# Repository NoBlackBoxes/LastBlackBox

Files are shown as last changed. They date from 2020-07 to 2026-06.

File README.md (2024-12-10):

# The Last Black Box

> - Do you depend on technology to work? to learn? to socialize?
> - Do you want to know what is going on inside the machines that run your life?
> - Do you want to be ready for the coming era of AI?

<p align="center">
LBB
</p>

## Summary

Imagine a world without "black boxes". A world where you understand how your tools work and can use them to do what you want.

This world is much closer than you realize, and we have developed this training course to help get you there as quickly (and enjoyably!) as possible.

**The Last Black Box** is a hands-on introduction to the foundations of modern technology<p>...from ***electrons*** to ***AI***.

## Principles

<p align="center">
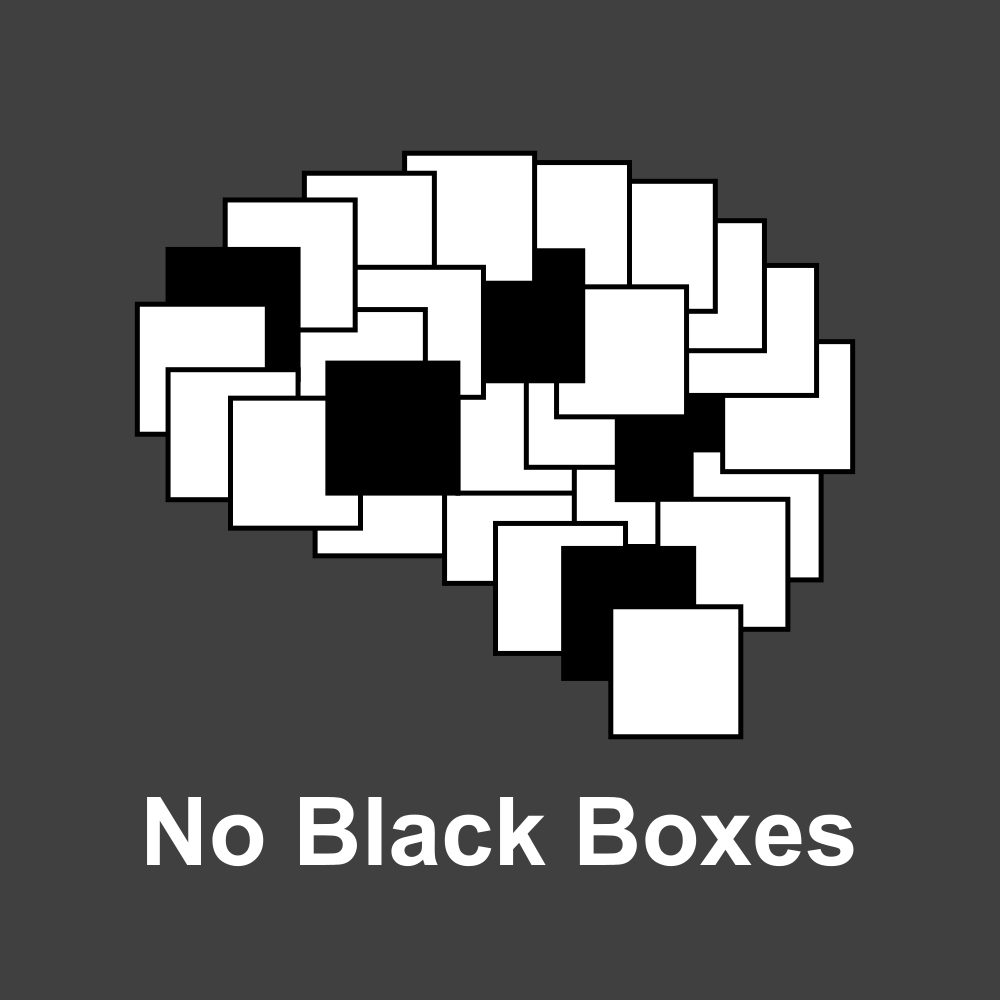
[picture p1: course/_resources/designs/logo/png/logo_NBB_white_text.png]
NBB

</p>

----

<p align="center" style="font-size:32px">
<a href="course/README.md" style="color: #FFFF00; background: #000000; border-color: #FFFF00; border-style: solid; border-width: 2px; border-radius:6px; padding-left:12px; padding-right:12px;"><b>Start the course!</b></a>
</p>

----

## License

<br />The entire LastBlackBox repository and website is licensed under a <a rel="license" href="http://creativecommons.org/licenses/by-nc-sa/4.0/">Creative Commons Attribution-NonCommercial-ShareAlike 4.0 International License</a>.

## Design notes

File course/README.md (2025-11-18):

# The Last Black Box Course

> A course consisting of 28 **black boxes** that you open in sequence using the materials contained in the "Last Black Box" kit

<p align="center">
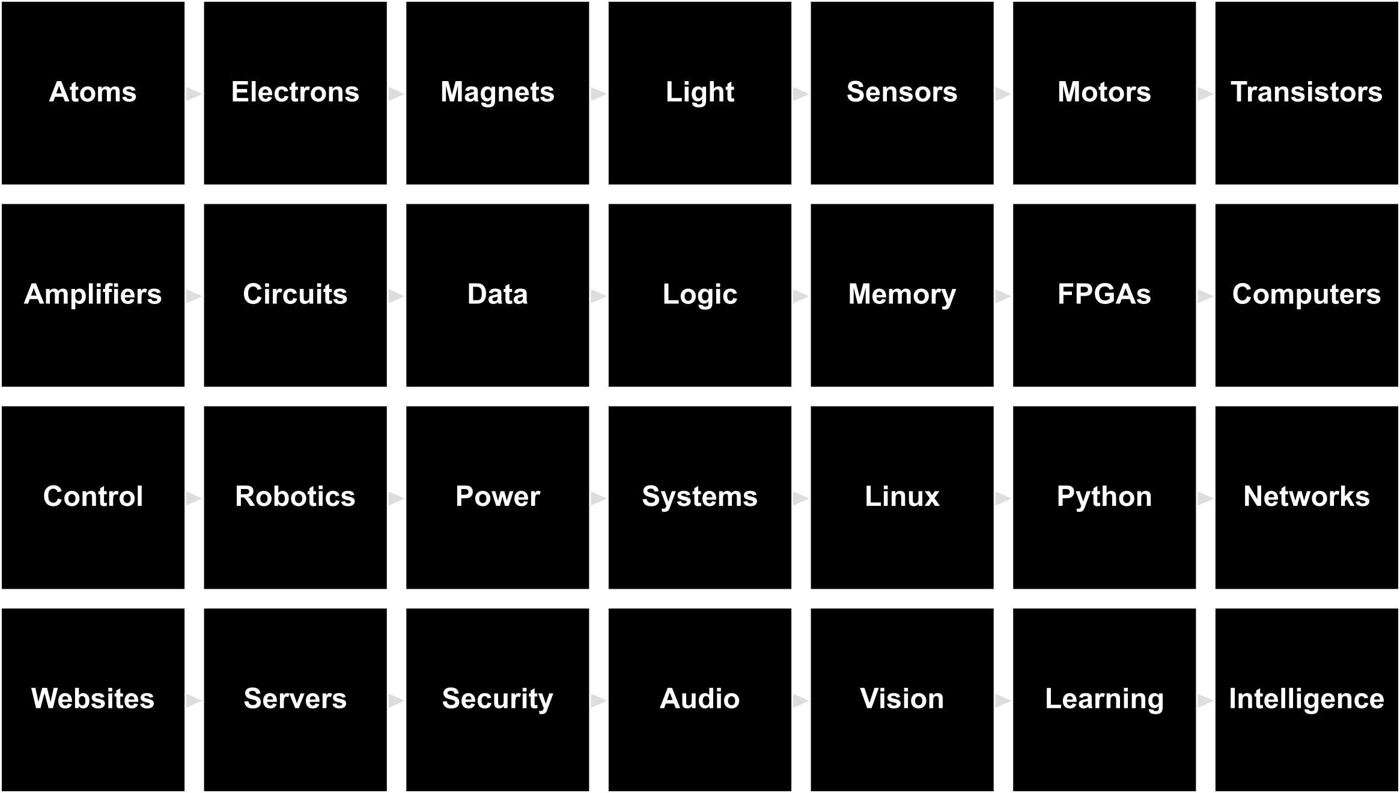
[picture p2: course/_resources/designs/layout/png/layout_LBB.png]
Course Layout

<h3 style="text-align:center;">Order your "<a href=https://www.noblackboxes.org/courses target="_blank">Last Black Box</a>" now!</h3>
</p>

----

## NB3

You will be building a brain for your robot. The robot's physical layout mimics the basic anatomy of a (vertebrate) brain. As you progress through the course, your robot will *evolve* into an increasingly sophisticated machine. The goal is to create an "intelligent" machine without using any **black boxes**. We thus call this robot the No-Black-Box-Brain or NBBB or ***NB3***.

<p align="center">
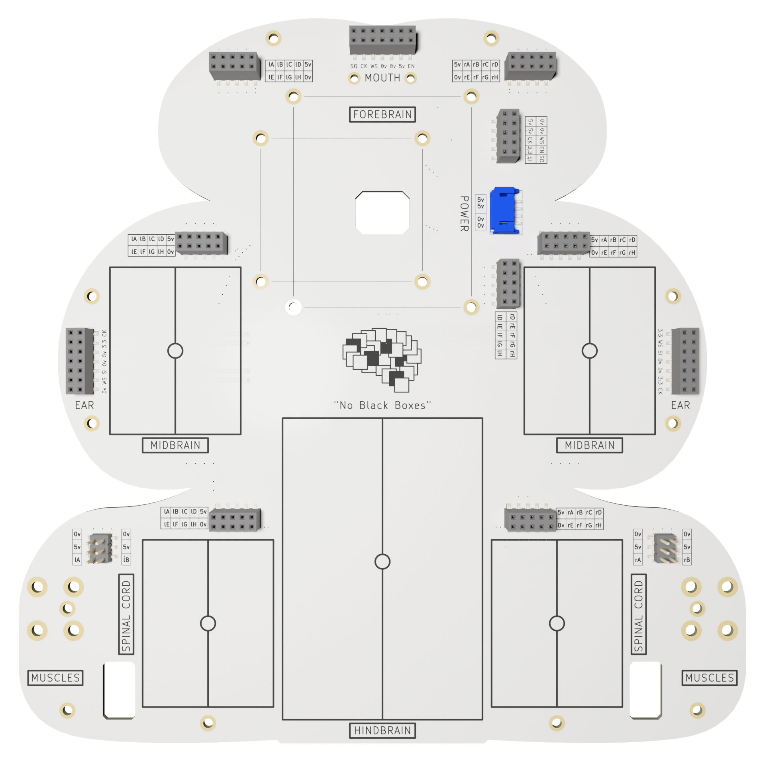
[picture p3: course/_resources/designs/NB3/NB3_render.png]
NB3 outline

</p>

## Repository
The course is based on the documentation and code in this repo (LBB). You will first work through the material on GitHub.com, but when you manage to connect to your Raspberry Pi via SSH, then you will be asked to clone this repo to your NB3. **It is very important that you clone the LBB repo to a specific folder ("NoBlackBoxes") in your NB3's home directory**.
> *Why?* Most of the code examples assume that the repo is stored in this location. If you prefer to put it somewhere else, then you must be comfortable modifying the "repo root" path used in the examples.

```bash
cd $HOME            # Navigate to your "Home" directory
mkdir NoBlackBoxes  # Create NoBlackBoxes directory
cd NoBlackBoxes     # Change to NoBlackBoxes directory

# Clone LBB repo (only the most recent commit)
git clone --depth 1 https://github.com/NoBlackBoxes/LastBlackBox
```

## Versions
There are shorter versions of this course that cover a specific subset of the "black boxes" and focus on specific themes.

- [Bootcamp](versions/bootcamp/README.md): A one-week intensive introduction to the essentials of modern technology and neuroscience.

- [Build a Brain](versions/buildabrain/README.md): Designed for secondary school age students, this hands-on course shows you how recent advances in science and technology have made it possible for humans to create intelligent machines...by building you own. 

- [Own Phone](versions/ownphone/README.md): ***-Under Development-*** Get your "smartphone license"! Demonstrate to your parents/friends that you can take control of your digital tools...before they take control you.

## Black Boxes

1. **Atoms**
    - *Technology*: Introduction to atoms, sub-atomic particles, and forces.
    - *Neuroscience*: From physics to chemistry to biology to brains.
    > *Tasks*: Draw your favorite atoms and molecules.

2. **Electrons**
    - *Technology*: Intro to basic electronics: voltage, current, resistance, batteries, Ohm's Law, voltage dividers, and power (dissipation).
    - *Neuroscience*: Neurons (resting potential), passive properties.
    > *Tasks*: Measure voltage/current/resistance. Build a voltage divider. Turn on a light bulb.

3. **Magnets**
    - *Technology*: Intro to magnetism
    - *Neuroscience*: Why not?
    > *Tasks*: Build a speaker...coil an electromagnet

4. **Light**
    - *Technology*: Intro to EM radiation and spectrum
    - *Neuroscience*: Why not?
    > *Tasks*: Lightbulbs and antennas

5. **Sensors**
    - *Technology*: Intro to transduction of heat, light, pressure, and sound.
    - *Neuroscience*: Intro to photoreceptors, hair cells, and mechanosensors.
    > *Tasks*: Build a light, heat, pressure sensor using a photoresitor, thermistor, piezo

6. **Motors**
    - *Technology*: Intro to electromagnetism and piezos
    - *Neuroscience*: Muscles and motor neruons (chemical synapses?)
    > *Tasks*: Wind a coil, spin a motor, make a sound, build a theremin(?)

7. **Transistors**
    - *Technology*: Intro to tubes and transistors
    - *Neuroscience*: Action potentials and axons and synapses (or later...with decisions?)
    > *Tasks*: Switch on a motor with your sensor, better theremin?

8. **Amplifiers**
    - *Technology*: Intro op amps
    - *Neuroscience*: Multiplicative NMJ, gain
      - Exercises**: Move a motor with your sensor, better theremin?

9. **Circuits**
    - *Technology*: Intro to integrated circults; how are they made and what are they good for.
    - *Neuroscience*: Simple sensorimotor behaviour
    > *Tasks*: Build a Braitenberg vehicle

10. **Power**
    - *Technology*: Voltage regulators
    - *Neuroscience*: Efficiency and homeostasis
    > *Tasks*: Install NB3_power

11. **Data**
    - *Technology*: Getting from analog to digital (0 and 1s is all you need), ADCs and DACs
    - *Neuroscience*: Neural code? (rate v timing?)
    > *Tasks*: Comparator...Build a simple ADC?

12. **Logic**
    - *Technology*: digital logic and the basis of computation
    - *Neuroscience*: Simple neural circuits: E and I
    > *Tasks*: Build an adder

13. **Memory**
    - *Technology*: flip/flop, flash, storage
    - *Neuroscience*: Synapses, LTP, and NMDA channels
    > *Tasks*: Sample hold circuit? (clapper?) Build a D-Latch

14. **FPGAs**
    - *Technology*: Programmble logic devices, HDL (verilog)
    - *Neuroscience*: simple, adaptable circuits for computation
    > *Tasks*: Adder in FPGA...ALU...cpu

15. **Computers**
    - *Technology*: ALU, microcontrollers and progamming I
    - *Neuroscience*: basic brains (brain computer anlogy debate)
    > *Tasks*: Arduino basics, blinky in ASM and C

16. **Control**
    - *Technology*: Negative feedback and servos, H-bridge, PID
    - *Neuroscience*: Motor control
    > *Tasks*: Write direction, speed (and position?) controller

17. **Robotics**
    - *Technology*: Smarter robots
    - *Neuroscience*: Smarter bot
    > *Tasks*: Ardunio based robot (PWM motors? various sensors?): Task: ?

18. **Systems**
    - *Technology*: Operating systems and programming II
    - *Neuroscience*: Brain systems (sense, perceive, memory, learning, )
    > *Tasks*: Booting and connecting

19. **Linux**
    - *Technology*: Linux and command lines
    - *Neuroscience*: Should the interfaces to your brain be "open"?
    > *Tasks*: Linux-life

20. **Python**
    - *Technology*: Programming in Python, installing packages, and virtual environments
    - *Neuroscience*: How to think like a programmer?
    > *Tasks*: Talk to your hindbrain

21. **Networks**
    - *Technology*: Internet protocols and WiFi
    - *Neuroscience*: Physical layer and neural protocols
    > *Tasks*: SSH and connect to bot via ESP or NRF

22. **Websites**
    - *Technology*: HTML, CSS
    - *Neuroscience*: ??
    > *Tasks*: Build a nice looking website

23. **Servers**
    - *Technology*: HTTP requests and responses
    - *Neuroscience*: ??
    > *Tasks*: Host your nice looking website

24. **Security**
    - *Technology*: Encryption
    - *Neuroscience*: ??
    > *Tasks*: Mine a bitcoin?

25. **Audio**
    - *Technology*: From mics to "understanding" sound
    - *Neuroscience*: Extracting information from hair cells, sound localization
    > *Tasks*: Build a sound localizer (dealing with 1D data)

26. **Vision**
    - *Technology*: From cameras to "vision"
    - *Neuroscience*: Extracting information from photoreceptors (through V1 and beyond)
    > *Tasks*: Build a colored blob detector

27. **Learning**
    - *Technology*: Reinforcement learning and clicker training
    - *Neuroscience*: RL in brains
    > *Tasks*: Clicker train yourself and your robot

28. **Intelligence**
    - *Technology*: Neural Networks and modern "AI", NPUs, LLMs
    - *Neuroscience*: From fish to humans, evolution of biological intelligence
    > *Tasks*: NPU and tensorflow...mysteries...

----

## License

<br />The entire LastBlackBox repository and website is licensed under a <a rel="license" href="http://creativecommons.org/licenses/by-nc-sa/4.0/">Creative Commons Attribution-NonCommercial-ShareAlike 4.0 International License</a>.

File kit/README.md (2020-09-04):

# The Last Black Box Kit

A set of black boxes to open in sequence

----

## Boxes

<p align="center">
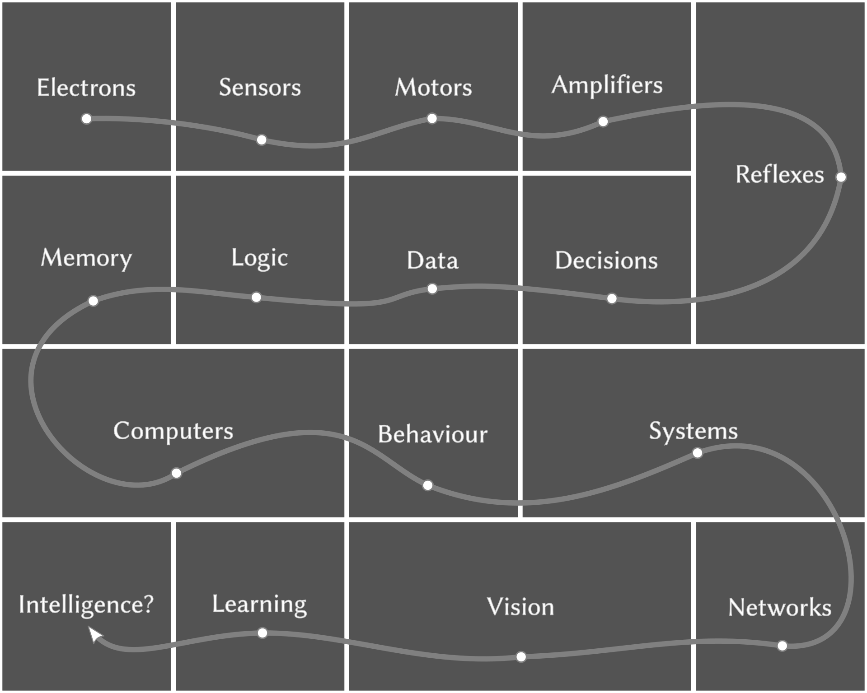
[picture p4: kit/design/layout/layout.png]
Example Image

</p>

----

1. [Electrons](/boxes/electrons/README.md)
2. [Sensors](/boxes/sensors/README.md)
3. [Motors](/boxes/motors/README.md)
4. [Amplifiers](/boxes/amplifiers/README.md)
5. [Reflexes](/boxes/reflexes/README.md)
6. [Decisions](/boxes/decisions/README.md)
7. [Data](/boxes/data/README.md)
8. [Logic](/boxes/logic/README.md)
9. [Memory](/boxes/memory/README.md)
10. [Computers](/boxes/computers/README.md)
11. [Behaviour](/boxes/behaviour/README.md)
12. [Systems](/boxes/systems/README.md)
13. [Networks](/boxes/networks/README.md)
14. [Vision](/boxes/vision/README.md)
15. [Learning](/boxes/learning/README.md)
16. [Intelligence?](/boxes/intelligence/README.md)

### Descriptions

1. **Electrons**

    - *Tech*: Intro to basic electronics: voltage, current, resistance, batteries, Ohm's Law, voltage dividers, and power (dissipation).
    - *Brain*: Neurons (resting potential), passive properties.
    - *Exercises*: Measure voltage/current/resistance. Build a voltage divider. Turn on a light bulb.

2. **Sensors**

    - *Tech*: Intro to transduction of heat, light, pressure, and sound.
    - *Brain*: Intro to photoreceptors, hair cells, and mechanosensors.
    - *Exercises*: Build a light, heat, pressure sensor using a photoresitor, thermistor, piezo

3. **Motors**

    - *Tech*: Intro to electromagnetism and piezos
    - *Brain*: Muscles and motor neruons (chemical synapses?)
    - *Exercises*: Wind a coil, spin a motor, make a sound, build a theremin(?)

4. **Amplifiers**

    - *Tech*: Intro to tubes and transistors, and op amps
    - *Brain*: Action potentials and axons and synapses (or later...with decisions?)
    - *Exercises*: Move a motor with your sensor, better theremin?

5. **Reflexes**

    - *Tech*: Intro to control
    - *Brain*: Simple sensorimotor behaviour
    - *Exercises*: Build a Braitenberg vehicle

6. **Decisions**

    - *Tech*: Transistors as switches (and relays?)
    - *Brain*: Action potential
    - *Exercises*: Light/Dark finding bot?

7. **Data**

    - *Tech*: Getting from analog to digital (0 and 1s is all you need), ADCs and DACs
    - *Brain*: Neural code? (rate v timing?)
    - *Exercises*: Build a simple ADC?

8. **Logic**

    - *Tech*: digital logic and the basis of computation
    - *Brain*: Simple neural circuits: E and I
    - *Exercises*: Build an adder

9. **Memory**

    - *Tech*: flip/flop, flash, storage
    - *Brain*: Synapses, LTP, and NMDA channels
    - *Exercises*: Sample hold circuit? (clapper?) Build a D-Latch

10. **Computers**

    - *Tech*: ALU, microcontrollers and progamming I
    - *Brain*: basic brains (brain computer anlogy debate)
    - *Exercises*: Arduino basics, blinky in ASM and C

11. **Behaviour**

    - *Tech*: Smarter robots
    - *Brain*: Smarter bot
    - *Exercises*: Ardunio based robot (PWM motors? various sensors?): Task: ?

12. **Systems**

    - *Tech*: Operating systems and programming II
    - *Brain*: Brain systems (sense, perceive, memory, learning, )
    - *Exercises*: Python basics, linux basics

13. **Networks**

    - *Tech*: Internet protocols and WiFi
    - *Brain*: Physical layer and neural protocols
    - *Exercises*: SSH and connect to bot via ESP or NRF

14. **Vision**

    - *Tech*: From cameras to "vision"
    - *Brain*: Extracting information from photoreceptors (through V1 and beyond)
    - *Exercises*: Build a colored blob detector

15. **Learning**

    - *Tech*: Reinforcement learning and clicker training
    - *Brain*: RL in brains
    - *Exercises*: Clicker train yourself and your robot

16. **Intelligence?**

    - *Tech*: Neural Networks and modern "AI", NPU
    - *Brain*: From fish to humans, evolution of biological intelligence
    - *Exercises*: NPU and tensorflow...mysteries...

- ***The Last Black Box***
  - *Tech*: What are we missing?
  - *Brain*: What are we missing?
  - *Exercises*: Image a brain slice (golgi stain? Nissl?)

----

## License

<br />The entire LastBlackBox repository and website is licensed under a <a rel="license" href="http://creativecommons.org/licenses/by-nc-sa/4.0/">Creative Commons Attribution-NonCommercial-ShareAlike 4.0 International License</a>.

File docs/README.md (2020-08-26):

<p align="center">
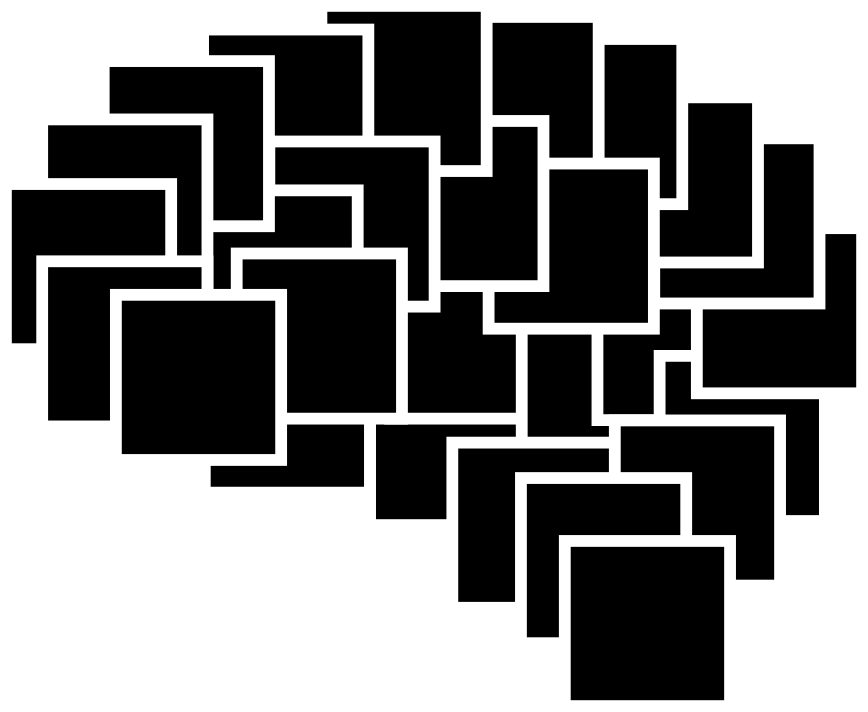
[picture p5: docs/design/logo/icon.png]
LBB

</p>

# The Last Black Box

A course for brains interested in brains (not for tools interested in tools)

----

## Boxes

<p align="center">
Example Image
</p>

----

### Titles

1. Electrons
2. Sensors
3. Motors
4. Amplifiers
5. Reflexes
6. Decisions
7. Data
8. Logic
9. Memory
10. Computers
11. Behaviour
12. Systems
13. Networks
14. Vision
15. Learning
16. Intelligence?

### Descriptions

1. **Electrons**

   - *Tech*: Intro to basic electronics: voltage, current, resistance, batteries, Ohm's Law, voltage dividers, and power (dissipation).
   - *Brain*: Neurons (resting potential), passive properties.
   - *Exercises*: Measure voltage/current/resistance. Build a voltage divider. Turn on a light bulb.

2. **Sensors**

   - *Tech*: Intro to transduction of heat, light, pressure, and sound.
   - *Brain*: Intro to photoreceptors, hair cells, and mechanosensors.
   - *Exercises*: Build a light, heat, pressure sensor using a photoresitor, thermistor, piezo

3. **Motors**

    - *Tech*: Intro to electromagnetism and piezos
    - *Brain*: Muscles and motor neruons (chemical synapses?)
    - *Exercises*: Wind a coil, spin a motor, make a sound, build a theremin(?)

4. **Amplifiers**

    - *Tech*: Intro to tubes and transistors, and op amps
    - *Brain*: Action potentials and axons and synapses (or later...with decisions?)
    - *Exercises*: Move a motor with your sensor, better theremin?

5. **Reflexes**

    - *Tech*: Intro to control
    - *Brain*: Simple sensorimotor behaviour
    - *Exercises*: Build a Braitenberg vehicle

6. **Decisions**

    - *Tech*: Transistors as switches (and relays?)
    - *Brain*: Action potential
    - *Exercises*: Light/Dark finding bot?

7. **Data**

    - *Tech*: Getting from analog to digital (0 and 1s is all you need), ADCs and DACs
    - *Brain*: Neural code? (rate v timing?)
    - *Exercises*: Build a simple ADC?

8. **Logic**

    - *Tech*: digital logic and the basis of computation
    - *Brain*: Simple neural circuits: E and I
    - *Exercises*: Build an adder

9. **Memory**

    - *Tech*: flip/flop, flash, storage
    - *Brain*: Synapses, LTP, and NMDA channels
    - *Exercises*: Sample hold circuit? (clapper?) Build a D-Latch

10. **Computers**

    - *Tech*: ALU, microcontrollers and progamming I
    - *Brain*: basic brains (brain computer anlogy debate)
    - *Exercises*: Arduino basics, blinky in ASM and C

11. **Behaviour**

    - *Tech*: Smarter robots
    - *Brain*: Smarter bot
    - *Exercises*: Ardunio based robot (PWM motors? various sensors?): Task: ?

12. **Systems**

    - *Tech*: Operating systems and programming II
    - *Brain*: Brain systems (sense, perceive, memory, learning, )
    - *Exercises*: Python basics, linux basics

13. **Networks**

    - *Tech*: Internet protocols and WiFi
    - *Brain*: Physical layer and neural protocols
    - *Exercises*: SSH and connect to bot via ESP or NRF

14. **Vision**

    - *Tech*: From cameras to "vision"
    - *Brain*: Extracting information from photoreceptors (through V1 and beyond)
    - *Exercises*: Build a colored blob detector

15. **Learning**

    - *Tech*: Reinforcement learning and clicker training
    - *Brain*: RL in brains
    - *Exercises*: Clicker train yourself and your robot

16. **Intelligence?**

    - *Tech*: Neural Networks and modern "AI", NPU
    - *Brain*: From fish to humans, evolution of biological intelligence
    - *Exercises*: NPU and tensorflow...mysteries...

- ***The Last Black Box***
  - *Tech*: What are we missing?
  - *Brain*: What are we missing?
  - *Exercises*: Image a brain slice (golgi stain? Nissl?)

----

## License

<br />The entire LastBlackBox repository and website is licensed under a <a rel="license" href="http://creativecommons.org/licenses/by-nc-sa/4.0/">Creative Commons Attribution-NonCommercial-ShareAlike 4.0 International License</a>.

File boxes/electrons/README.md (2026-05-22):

# The Last Black Box : Electrons
In this box, you will learn about electrons...

<details><summary><i>Materials</i></summary><p>

Name|Description| # |Package|Data|Link|
:-------|:----------|:-----:|:-:|:--:|:--:|
NB3 Body|NB3 robot base PCB|1|Body (000)|[-D-](/boxes/electrons/NB3_body)|[-L-](VK)
Resistor (470)|470 &Omega;/0.25 W|2|Passive Electronics|[-D-](/boxes/electrons/_resources/datasheets/resistor.pdf)|[-L-](https://uk.farnell.com/multicomp/mf25-470r/res-470r-1-250mw-axial-metal-film/dp/9341943)
Resistor (1k)|1 k&Omega;/0.25 W|2|Passive Electronics|[-D-](/boxes/electrons/_resources/datasheets/resistor.pdf)|[-L-](https://uk.farnell.com/multicomp/mf25-1k/res-1k-1-250mw-axial-metal-film/dp/9341102)
Resistor (10k)|10 k&Omega;/0.25 W|2|Passive Electronics|[-D-](/boxes/electrons/_resources/datasheets/resistor.pdf)|[-L-](https://uk.farnell.com/multicomp/mf25-10k/res-10k-1-250mw-axial-metal-film/dp/9341110)
Button|Tactile switch|2|Passive Electronics|[-D-](/boxes/electrons/_resources/datasheets/button.pdf)|[-L-](https://uk.farnell.com/omron/b3f-1000/switch-spno-0-05a-24v-tht-0-98n/dp/176432)
Potentiometer|2.2 k&Omega; variable resistor|2|Passive Electronics|[-D-](/boxes/electrons/_resources/datasheets/pot_2k2.pdf)|[-L-](https://uk.farnell.com/bourns/3362p-1-222lf/trimmer-pot-2-2kohm-10-1turn-th/dp/2328599)
Breadboard (400)|400-tie solderless breadboard|1|Small (010)|[-D-](/boxes/electrons/_resources/datasheets/breadboard_400.pdf)|[-L-](https://www.amazon.co.uk/gp/product/B0739XRX8F)
Breadboards (170)|170-tie solderless breadboard|4|Small (010)|[-D-](/boxes/electrons/_resources/datasheets/breadboard_170.pdf)|[-L-](https://www.amazon.co.uk/ELEGOO-tie-points-Breadboard-Breadboards-Electronic/dp/B01N0YWIR7)
Batteries (AA)|AA 1.5 V alkaline battery|4|Auxiliary|[-D-](/boxes/electrons/)|[-L-](https://www.amazon.co.uk/Duracell-Optimum-Alkaline-Batteries-MX1500/dp/B093Q5XY66)
Battery holder|4xAA battery holder with ON-OFF switch|1|Small (010)|[-D-](/boxes/electrons/)|[-L-](https://www.amazon.co.uk/gp/product/B0814ZH68F)
Jumper Kit|Kit of multi-length 22 AWG breadboard jumpers|1|Large (100)|[-D-](/boxes/electrons/_resources/datasheets/jumper_kit.pdf)|[-L-](https://uk.farnell.com/multicomp/mc001810/hard-jumper-wire-22awg-140pc/dp/2770338)
Jumper Wires|Assorted 22 AWG jumper wire leads (male/female)|1|Cables (001)|[-D-](/boxes/electrons/_resources/datasheets/jumper_wires.pdf)|[-L-](https://www.amazon.co.uk/gp/product/B09KR7Z4PF)
Test Lead|Alligator clip to 0.64 mm pin (20 cm)|2|Cables (001)|[-D-](/boxes/electrons/)|[-L-](https://www.amazon.co.uk/gp/product/B096JR15JW)
Rubber feet|Adhesive rubber standoffs (1421T6CL)|4|Passive Electronics|[-D-](/boxes/electrons/_resources/datasheets/rubber_feet.pdf)|[-L-](https://uk.farnell.com/hammond/1421t6cl/feet-stick-on-pk24/dp/1876522)
Capacitor (small)|0.1 uF ceramic capacitor|1|Passive Electronics|[-D-](/boxes/electrons/_resources/datasheets/capacitor_ceramic.pdf)|[-L-](https://uk.farnell.com/kemet/c322c104k1r5ta/cap-0-1-f-100v-10-x7r/dp/1457685)
Capacitor (large)|100 uF aluminum electrolytic capacitor|1|Passive Electronics|[-D-](/boxes/electrons/_resources/datasheets/capacitor_electrolytic.pdf)|[-L-](https://uk.farnell.com/rubycon/16zlh100mefc5x11/cap-100-f-16v-20/dp/8126283)

</p></details><hr>

## Electrons
#### Watch this video: [Electric Fields](https://vimeo.com/1032441712)
<p align="center">
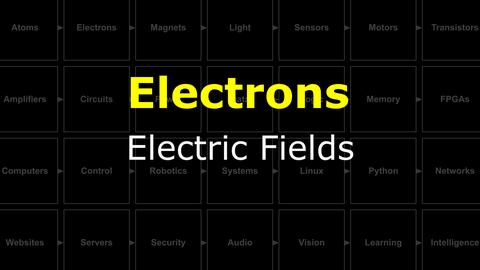
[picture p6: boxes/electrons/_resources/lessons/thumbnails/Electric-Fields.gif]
Electric Fields

</p>

> A very useful, and quite simple, depiction of the lines of force surrounding charged particles.

- Draw the electric field around a negative charge and positive charge separated by a small distance. Use the following image as a starting point.

#### Watch this video: [Voltage](https://vimeo.com/1000730032)
<p align="center">
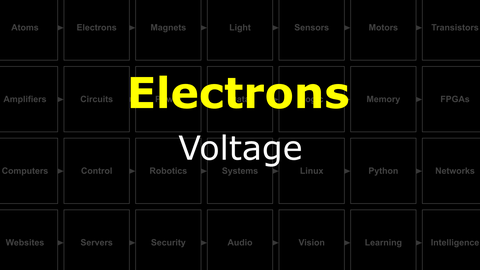
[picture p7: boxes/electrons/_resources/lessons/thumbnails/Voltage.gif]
Voltage

</p>

> When there is more negative or positive charge in one location vs. another there is a *potential difference* between these locations. This *potential difference* is called a **voltage** and it creates a pressure that pushes electrons from the location with more negative charge to the location with less.

#### Watch this video: [Conductors](https://vimeo.com/1029337222)
<p align="center">
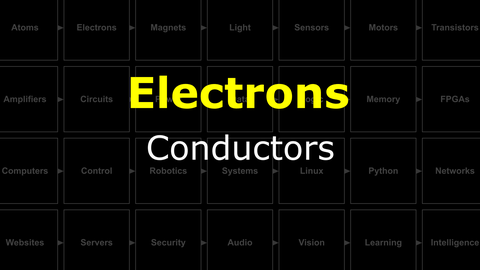
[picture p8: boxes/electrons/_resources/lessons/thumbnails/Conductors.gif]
Conductors

</p>

> Some materials have electrons in their outer orbitals that are happy to jump between neighboring atomic nuclei (of the same element). These electrons are "free" to move around the material. If we place such a material between two locations with a *potential difference* (voltage), then electrons will flow from the **(-)** location to the **(+)** location; the material will **conduct** electricity.

#### Watch this video: [Batteries](https://vimeo.com/1029278169)
<p align="center">
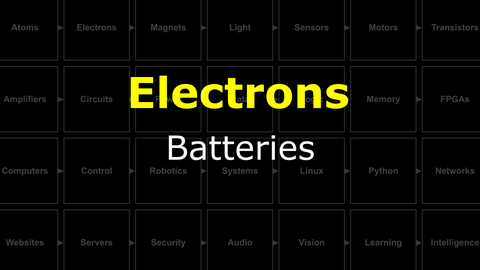
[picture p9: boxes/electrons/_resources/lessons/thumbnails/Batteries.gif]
Batteries

</p>

> Generating a stable voltage requires a renewable source of electrons to maintain a *potential difference*. We can accomplish this with a (redox) chemical reaction inside the wonderfully useful device that we call a **battery**.

- **TASK**: Measure the voltage of a AA battery using your multimeter.
  - *Hint*: Select the voltage ("V") setting and touch your probes to either end of the battery. Depending on your multimeter, you may also need to select an appropriate "range". For a single AA battery, you should expect to measure between 1 and 2 Volts.
  - *Help*: If you are new to using a multimeter, then I recommend that you watch this video: [NB3-Multimeter Basics](https://vimeo.com/1027764019)
  - *Help*: If you are new to measuring voltage with a multimeter, then I recommend that you watch this video: [NB3-Measuring Voltage](https://vimeo.com/1027762531)
> A single AA battery, fully charged, should have a voltage of ~1.6 Volts. If it is less than 1.5 Volts, then the battery is nearly *dead*.
- **TASK**: Measure the voltage of 4xAA batteries in series (end to end).
  - *Hint*: You can use your battery holder.
> Batteries connected in series will sum their voltages. You should measure four times the voltage of a single AA battery, ~6.4 Volts, from the batteries in your 4xAA holder.

#### Watch this video: [NB3 : Multimeter Basics](https://vimeo.com/1027764019)
<p align="center">
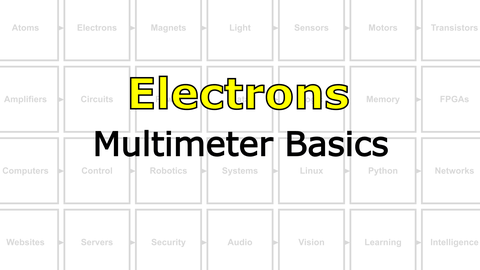
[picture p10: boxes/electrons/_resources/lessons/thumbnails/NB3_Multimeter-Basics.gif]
NB3 : Multimeter Basics

</p>

> An overview of digital multimeters for beginners. What can it measure? What features do you need to complete the course?

### NB3 : How Do Multimeters Work
> Learn how multimeters actually work

#### Watch this video: [NB3 : Measuring Voltage](https://vimeo.com/1027762531)
<p align="center">
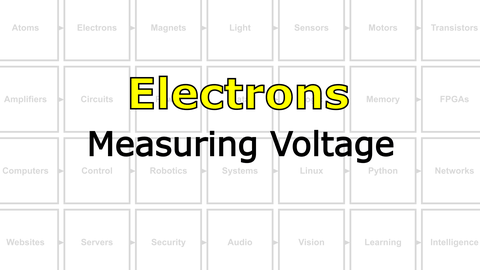
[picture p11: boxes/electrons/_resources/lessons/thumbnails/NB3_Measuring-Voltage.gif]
NB3 : Measuring Voltage

</p>

> How to measure voltage with a digital multimeter.

#### Watch this video: [Current](https://vimeo.com/1029334167/2492ff3542)
<p align="center">
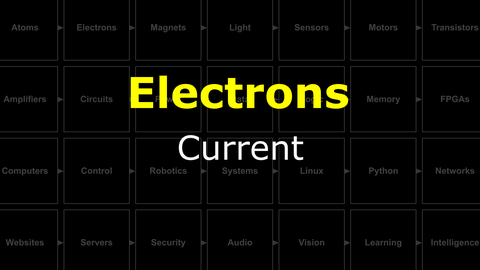
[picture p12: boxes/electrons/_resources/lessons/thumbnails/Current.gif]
Current

</p>

> The rate at which electrons flow, measured as *#charges / second*, is called **current**. We use the unit *Amps* (A) and the circuit symbol **I**.

#### Watch this video: [Resistors](https://vimeo.com/1029696806)
<p align="center">
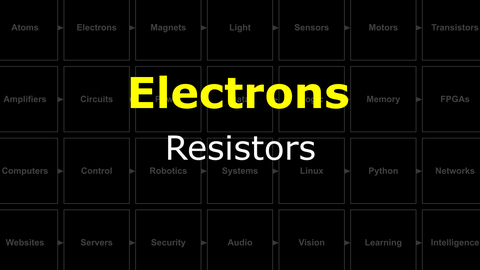
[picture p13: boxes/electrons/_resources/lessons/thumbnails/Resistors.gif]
Resistors

</p>

> Many materials hold onto their outer electrons and resist their movement. We can create mixtures of these "resisting" materials and better "conducting" materials, often in the form of ceramics, to create **resistors** with a range of different *resistance* values, which we measure in Ohms (&Omega;).

- **TASK**: Measure the resistance of your resistors.
  - *Help*: If you are new to measuring resistance with a multimeter, then I recommend that you watch this video: [NB3-Measuring Resistance](https://vimeo.com/1027761453)
> Your kit contains 470 &Omega;, 1 k&Omega;, and 10 k&Omega; resistors. You should measure these values.

#### Watch this video: [NB3 : Measuring Resistance](https://vimeo.com/1027761453)
<p align="center">
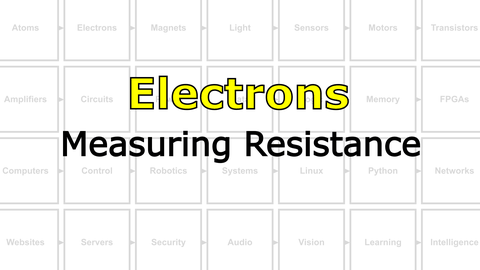
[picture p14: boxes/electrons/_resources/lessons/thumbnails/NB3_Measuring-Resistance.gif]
NB3 : Measuring Resistance

</p>

> How to measure resistance with a digital multimeter.

#### Watch this video: [NB3 : Measuring Current](https://vimeo.com/1027757287)
<p align="center">
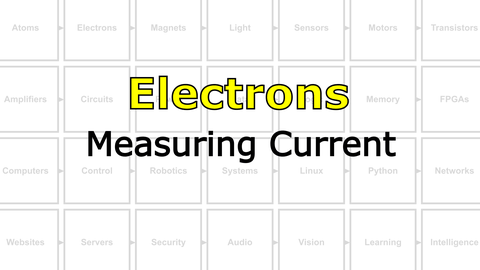
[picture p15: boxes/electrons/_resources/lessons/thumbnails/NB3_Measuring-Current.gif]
NB3 : Measuring Current

</p>

> How to measure current with a digital multimeter.

#### Watch this video: [NB3 : Body](https://vimeo.com/1030776673)
<p align="center">
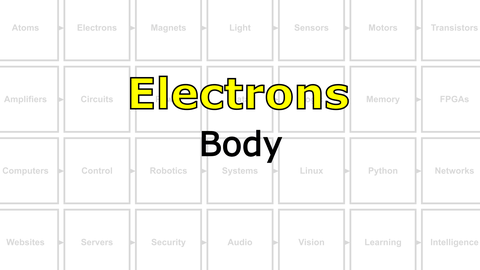
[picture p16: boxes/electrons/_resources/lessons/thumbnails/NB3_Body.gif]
NB3 : Body

</p>

> We will now start measuring and manipulating electricity, but first we will assemble a "prototyping platform" that also happens to be the **body** of your robot (NB3).

- **TASK**: Assemble the robot body (prototyping base board).
  - *Challenge*: If you are curious how the *NB3 Body* printed circuit board (PCB) was designed, then you can find the KiCAD files here: [NB3 Body PCB](/boxes/electrons/NB3_body).
> Your NB3 should now look like [this](/boxes/electrons/NB3_body/NB3_body_front.png). Your breadboards will be different colors...and you should have some rubber feet on the back.

#### Watch this video: [NB3 : Building Circuits](https://vimeo.com/1030783826)
<p align="center">
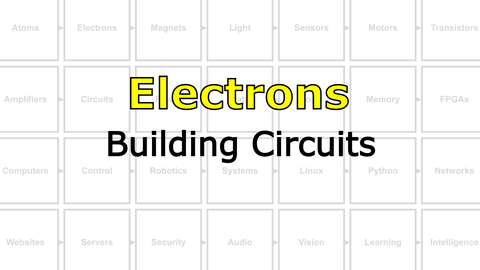
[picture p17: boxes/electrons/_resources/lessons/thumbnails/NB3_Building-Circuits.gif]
NB3 : Building Circuits

</p>

> With a voltage source (battery) and resistors, then we can start building "circuits" - complete paths of conduction that allow current to flow from a location with *less* electrons **(+)** to a location with *more* electrons **(-)**.

- *Note*: This is *weird*. Electrons are the things moving. Shouldn't we say that current "flows" from the **(-)** area to the **(+)** area? Unfortunately, current was described before anyone knew about electrons and we are stuck with the following awkward convention: **Current is defined to flow from (+) to (-)**...even though we now know that electrons are moving the opposite direction.
- **TASK**: Build the simple circuit below and measure the current flowing when you connect the battery pack.
  - *Warning*: Measuring current with a multimeter is ***tricky***. You can only get an accurate measurement if ***ALL*** of the current in the circuit is forced to flow through your multimeter. This means that when measuring current, your multimeter must be in *series* with the rest of the circuit. (As opposed to measuring voltage, when your multimeter is placed "parallel" to the circuit.)
  - *Help*: If you are new to measuring current with a multimeter, then I recommend you watch this video: [NB3-Measuring Current](https://vimeo.com/1027757287).
> Not too much current...and do not break your multimeter.

#### Watch this video: [Ohm's Law](https://vimeo.com/1029695302)
<p align="center">
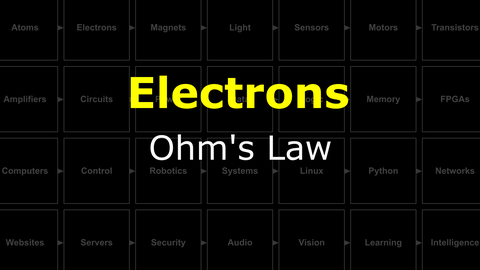
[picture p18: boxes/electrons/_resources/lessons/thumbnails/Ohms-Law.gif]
Ohm's Law

</p>

> Ohm's Law describes the relationship between Voltage, Current, and Resistance. It is not complicated, but it is very useful.

- **TASK**: Does Ohm's Law hold? You know the voltage of the batteries (V) and the resistance of the resistor (R). Measure the current flowing (I) for different resistors and confirm that V = I*R.
> For the resistors in your kit, then Ohm's Law should determine the current that you measure.

#### Watch this video: [Voltage Dividers](https://vimeo.com/1030787469)
<p align="center">
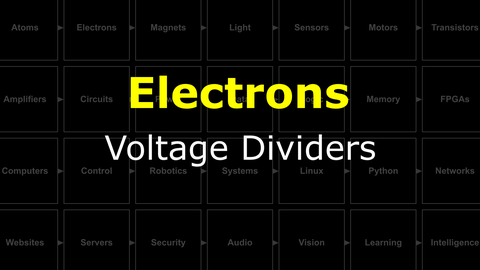
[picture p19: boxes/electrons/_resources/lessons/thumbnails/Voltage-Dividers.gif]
Voltage Dividers

</p>

> Controlling the level of voltage at different places in a circuit is critical to designing electronic devices.

- **TASK**: Build a voltage divider using two resistors of the same value. Measure the intermediate voltage (between the resistors).
> With equal size resistors, the intermediate voltage you measure should be half of the supply voltage.
- **TASK**: Build a voltage divider using a variable resistor (potentiometer). Measure the intermediate voltage. What happens when you change the position of the internal contact of the variable resistor (by turning the screw)?
  - *Help*: A video guide to completing these tasks can be found here: [NB3-Building Voltage Dividers](https://vimeo.com/1030790826)
> The intermediate voltage should vary continuously as you adjust the potentiometer.

#### Watch this video: [NB3 : Building Voltage Dividers](https://vimeo.com/1030790826)
<p align="center">
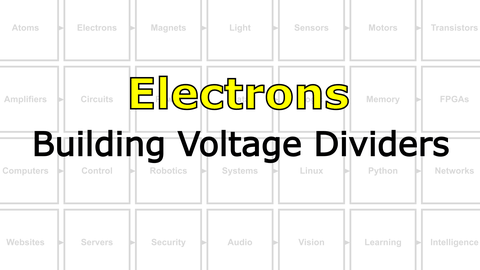
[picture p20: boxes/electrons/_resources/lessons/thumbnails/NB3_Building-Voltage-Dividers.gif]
NB3 : Building Voltage Dividers

</p>

> Step-by-step guide to building and testing voltage dividers with discrete resistors and a potentiometer.

#### Watch this video: [Power](https://vimeo.com/1029693122)
<p align="center">
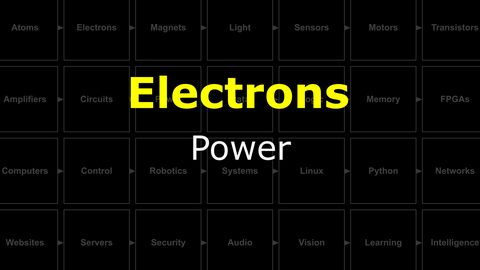
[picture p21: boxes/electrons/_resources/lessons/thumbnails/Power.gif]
Power

</p>

> When electrons move through a circuit, they deliver power (some amount of energy in some amount of time). This power can be used to do useful things: make a motor move, light a lamp, or generate heat. If we deliver too little power, then our electronic device may not work as designed. If we deliver too much, then it may never work again. We measure power in Watts.

#### Watch this video: [Capacitors](https://vimeo.com/1035298931)
<p align="center">
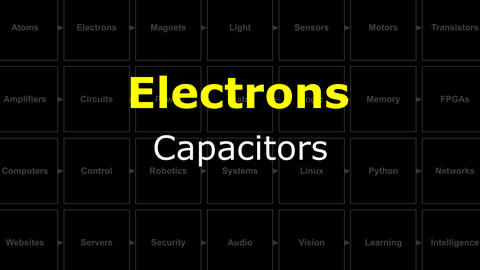
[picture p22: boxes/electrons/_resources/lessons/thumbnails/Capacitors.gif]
Capacitors

</p>

> Two conductors separated by an insulator (but in close proximity) can interact through the electric field. If we put an external voltage across these conductors, then they will gradually accumulate charge until their own voltage matches the external potential. We say that these devices have an intrinsic capacity for storing charge and we call them **capacitors**.

# Projects
### NB3 : Designing PCBs With KiCAD
> What is KiCAD and how can we use it to design (and manufacture) PCBs?

#### Watch this video: [NB3 : Building a Battery](https://vimeo.com/1029280971)
<p align="center">
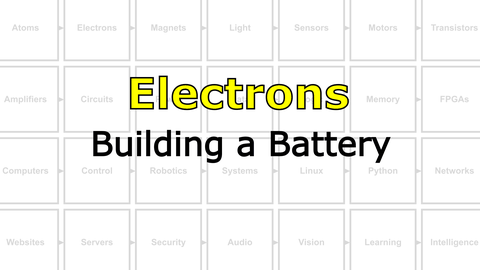
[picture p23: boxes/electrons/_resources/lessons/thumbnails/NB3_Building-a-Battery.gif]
NB3 : Building a Battery

</p>

> Let's build a version of the *first* battery, and use it to power an LED.

- **TASK**: Build a simple battery
  - Combine two different metals, one that oxidizes well and one that does not, and connect them together with a layer of electrolyte between (salt water soaked paper works fine, so does a piece of fruit).
> You should see a voltage if you choose your two metals wisely. Zinc and Copper should produce ~0.76 Volts. If you stack multiple cells in series, then the resulting voltage should sum.

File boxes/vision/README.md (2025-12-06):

# The Last Black Box : Vision
In this box, you will learn about vision...

<details><summary><i>Materials</i></summary><p>

Name|Description| # |Package|Data|Link|
:-------|:----------|:-----:|:-:|:--:|:--:|
Camera (RPi v3)|RPi color camera with auto-focus (version 3)|1|Medium (011)|[-D-](/boxes/vision/_resources/datasheets/rpi_camera_v3.pdf)|[-L-](https://uk.farnell.com/raspberry-pi/sc0872/rpi-camera-mod-3-standard-lens/dp/4132318)
NB3 Camera Mount|Custom laser cut mount for RPi camera|1|Acrylic Mounts|[-D-](/boxes/vision/NB3_camera_mount)|[-L-](VK)
NB3 Cortex Mount|Custom laser cut holder for NPU|1|Acrylic Mounts|[-D-](/boxes/vision/NB3_cortex_mount)|[-L-](VK)
M2.5 bolt (6)|6 mm long M2.5 bolt|4|Mounting Hardware|[-D-](/boxes/robotics/)|[-L-](https://www.accu.co.uk/pozi-pan-head-screws/9255-SPP-M2-5-6-A2)
M2.5 standoff (20/PS)|20 mm long plug-to-socket M2.5 standoff|4|Mounting Hardware|[-D-](/boxes/vision/)|[-L-](https://uk.farnell.com/wurth-elektronik/971200151/standoff-hex-male-female-20mm/dp/2884418)
M3 nut (square)|square M3 nut 1.8 mm thick|1|Mounting Hardware|[-D-](/boxes/audio/-)|[-L-](https://www.accu.co.uk/flat-square-nuts/21326-HFSN-M3-A2)
M3 bolt (12)|12 mm long M3 bolt|1|Mounting Hardware|[-D-](/boxes/vision/)|[-L-](https://www.accu.co.uk/pozi-pan-head-screws/500116-SPP-M3-12-ST-BZP)
M2 bolt (8)|8 mm long M2 bolt|4|Mounting Hardware|[-D-](/boxes/audio/)|[-L-](https://www.accu.co.uk/pozi-pan-head-screws/500101-SPP-M2-8-ST-BZP)
M2 nut|regular M2 nut|4|Mounting Hardware|[-D-](/boxes/audio/)|[-L-](https://www.accu.co.uk/hexagon-nuts/456429-HPN-M2-C8-Z)

</p></details><hr>

## Vision
#### Watch this video: [Light, Cameras, Noise](https://vimeo.com/manage/videos/1141367902)
<p align="center">
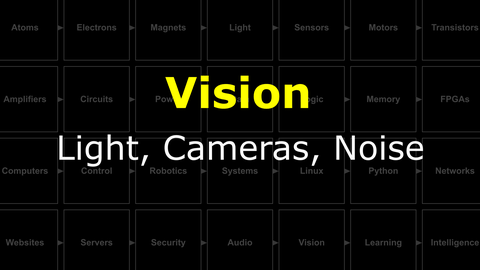
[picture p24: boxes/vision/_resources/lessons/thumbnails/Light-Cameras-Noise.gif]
Light, Cameras, Noise

</p>

> We start with a recap about light, measuring analog signals with computers, and then describe how a modern camera sensor is built. We then introduce the NB3's Eye and conclude with a discussion of the sources of noise that all cameras encounter when trying to *image* the real world.

#### Watch this video: [Image-Processing](https://vimeo.com/manage/videos/1144050570)
<p align="center">
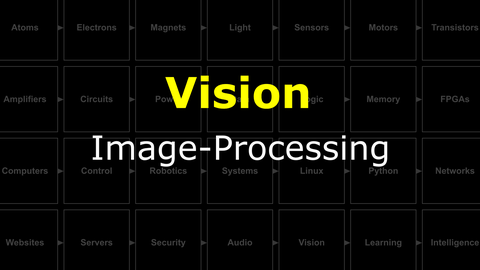
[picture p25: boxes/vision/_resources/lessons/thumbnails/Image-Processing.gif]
Image-Processing

</p>

> Old-school (classical) techniques for processing two-dimensional data (2D).

- Install python opencv
- *code*
```bash
pip install opencv-python
```

# Projects
#### Watch this video: [NB3 : Install the Eye](https://vimeo.com/1042945461)
<p align="center">
<a href="https://vimeo.com/1042945461" title="Control+Click to watch in new tab">NB3 : Install the Eye</a>
</p>

> Let's install a camera on your NB3.

- Test your camera with the following command
```bash
# Capture a still image and save it to a file
rpicam-still -o my_test.png

# The image will appear in the same folder where the command was run
```

#### Watch this video: [NB3 : Streaming Images](https://vimeo.com/manage/videos/1141582696)
<p align="center">
<a href="https://vimeo.com/manage/videos/1141582696" title="Control+Click to watch in new tab">NB3 : Streaming Images</a>
</p>

> Let's stream live images from your NB3's camera to any web browser.

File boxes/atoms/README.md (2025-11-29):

# The Last Black Box : Atoms
In this box, you will learn about atoms...

<details><summary><i>Materials</i></summary><p>

Name|Description| # |Package|Data|Link|
:-------|:----------|:-----:|:-:|:--:|:--:|
Periodic Table|Periodic Table Card|1|Body (000)|[-D-](/boxes/atoms/card)|[-L-](VK)

</p></details><hr>

## Atoms
#### Watch this video: [Atomic Structure](https://vimeo.com/1000458082)
<p align="center">
<a href="https://vimeo.com/1000458082" title="Control+Click to watch in new tab">Atomic Structure</a>
</p>

> A brief introduction to the physics of atoms, their parts (protons, neutrons, and electrons), and their classical vs. quantum structure.

- **TASK**: Draw your favorite atom in the "classical" style
> You should have the appropriate number of electrons in each orbital.

#### Watch this video: [The Periodic Table](https://vimeo.com/1028399080)
<p align="center">
<a href="https://vimeo.com/1028399080" title="Control+Click to watch in new tab">The Periodic Table</a>
</p>

> Organizing the elements into a table reveals a regular pattern, which is linked to the fundamental chemical properties of each material.

- When you need it *(and you will)*, then you can find a copy of the periodic table [here](/boxes/atoms/_resources/images/periodic_table.png).
- The electron configuration (assignments to specific orbitals) of each atomic element can be viewed [here](https://en.wikipedia.org/wiki/Electron_configurations_of_the_elements_(data_page)).

### Chemistry
> Atoms with incomplete outer (valence) orbitals will try to complete their set of electrons by sharing, donating, or stealing electrons from other Atoms. This is called chemistry.

#### Watch this video: [Heat](https://vimeo.com/1029691491)
<p align="center">
<a href="https://vimeo.com/1029691491" title="Control+Click to watch in new tab">Heat</a>
</p>

> Atoms in every material are always moving. This motion of atoms (their average kinetic energy) is heat.

### Nuclear Forces
> Wait. What's up with Hydrogen? Why no Neutrons? Oh...what about Helium? Why don't those Protons, with their positive charges, just fly apart?

### Fission and Fusion
> Not all Nuclei are stable, sometimes they can fall apart (fission). What if two atoms get *sooooo* close to one another that their Nuclei connect (fuse)? Lots of energy is released...and a new element forms.

# Projects

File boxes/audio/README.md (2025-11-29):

# The Last Black Box : Audio
In this box, you will learn about audio...

<details><summary><i>Materials</i></summary><p>

Name|Description| # |Package|Data|Link|
:-------|:----------|:-----:|:-:|:--:|:--:|
NB3 Ear|I2S mems microphone breakout board|2|Circuit Boards|[-D-](/boxes/audio/NB3_ear)|[-L-](VK)
NB3 Mouth|I2S DAC-AMP breakout board|1|Circuit Boards|[-D-](/boxes/audio/NB3_mouth)|[-L-](VK)
Speaker (Hi-Fi)|3 Watt 4 Ohm with Dupont 2.54 mm socket (High Fidelity: 2831/3128)|1|Large (100)|[-D-](/boxes/audio/_resources/datasheets/3128_3W_4Ohm.jpg)|[-L-](https://www.amazon.co.uk/gp/product/B0D9QXW5FF)
Speaker Mount|Custom laser cut mount for speaker|1|Acrylic Mounts|[-D-](/boxes/audio/-)|[-L-](VK)
Speaker Frame|Custom laser cut frame for speaker|1|Acrylic Mounts|[-D-](/boxes/audio/-)|[-L-](VK)
M3 standoff (15/PS)|15 mm long plug-to-socket M3 standoff|2|Mounting Hardware|[-D-](/boxes/audio/-)|[-L-](https://uk.farnell.com/ettinger/05-13-151/spacer-m3x15-vzk/dp/1466726)
M3 nut (square)|square M3 nut 1.8 mm thick|2|Mounting Hardware|[-D-](/boxes/audio/-)|[-L-](https://www.accu.co.uk/flat-square-nuts/21326-HFSN-M3-A2)
M3 bolt (6)|6 mm long M3 bolt|2|Mounting Hardware|[-D-](/boxes/audio/-)|[-L-](https://www.accu.co.uk/pozi-pan-head-screws/500113-SPP-M3-6-ST-BZP)
M2.5 bolt (6)|6 mm long M2.5 bolt|2|Mounting Hardware|[-D-](/boxes/robotics/)|[-L-](https://www.accu.co.uk/pozi-pan-head-screws/9255-SPP-M2-5-6-A2)
M2.5 nut|regular M2.5 nut|2|Mounting Hardware|[-D-](/boxes/power/-)|[-L-](https://www.accu.co.uk/hexagon-nuts/456430-HPN-M2-5-C8-Z)
M2 bolt (8)|8 mm long M2 bolt|2|Mounting Hardware|[-D-](/boxes/audio/)|[-L-](https://www.accu.co.uk/pozi-pan-head-screws/500101-SPP-M2-8-ST-BZP)
M2 nut|regular M2 nut|2|Mounting Hardware|[-D-](/boxes/audio/)|[-L-](https://www.accu.co.uk/hexagon-nuts/456429-HPN-M2-C8-Z)

</p></details><hr>

## Audio
#### Watch this video: [Microphones, Speakers, and I2S](https://vimeo.com/1136576333)
<p align="center">
<a href="https://vimeo.com/1136576333" title="Control+Click to watch in new tab">Microphones, Speakers, and I2S</a>
</p>

> Here we introduce the NB3's audio system: MEMs-based stereo microphones (Ears), a Class D digital amplifier connected to a "Hi-Fi" speaker (Mouth), and a sound communication standard called I2S (Inter-integrated Circuit Sound) that the Raspberry Pi will use to talk to these audio devices.

#### Watch this video: [NB3 : Build and Install the Linux I2S Driver](https://vimeo.com/1042781850)
<p align="center">
<a href="https://vimeo.com/1042781850" title="Control+Click to watch in new tab">NB3 : Build and Install the Linux I2S Driver</a>
</p>

> Let's build (compile) and install the Linux device driver for our NB3's sound card. This software module is required to access the NB3's ears (microphone) and mouth (speaker).

#### Watch this video: [NB3 : Install the Ears](https://vimeo.com/1042943195)
<p align="center">
<a href="https://vimeo.com/1042943195" title="Control+Click to watch in new tab">NB3 : Install the Ears</a>
</p>

> Let's add some ears to your NB3.

#### Watch this video: [NB3 : Install the Mouth](https://vimeo.com/1042947561)
<p align="center">
<a href="https://vimeo.com/1042947561" title="Control+Click to watch in new tab">NB3 : Install the Mouth</a>
</p>

> Let's add a mouth to your NB3.

# Projects
#### Watch this video: [Signal Processing](https://vimeo.com/manage/videos/1139975157)
<p align="center">
<a href="https://vimeo.com/manage/videos/1139975157" title="Control+Click to watch in new tab">Signal Processing</a>
</p>

> One-dimensional (1D) signals are common in the world. They often arise as time series (a sequence of measurements made at a regular "sample rate"). Here we will explore techniques to process a common 1D signal...**sound**. We will both measure and generate different sounds. We will develop tools in Python to compare their amplitude (volume), frequency content, and visualize the "spectrogram" of different spoken words (e.g. "Go" vs "Stop").

- Explore, test, and expand upon these Python examples for processing signals measured from the NB3's microphones (ears): [Measurement](/boxes/audio/signal-processing/python/measurement/)
    - Stream the live frequency spectrum from your NB3 to your PC.
        - Run the [server](/boxes/audio/signal-processing/python/measurement/03_stream_frequency.py) on your NB3 (via SSH)
        - Run the [client](/boxes/audio/signal-processing/python/measurement/clients/live_plot_frequency_client_pyglet.py) on your PC (in a separate VS Code window)
- Explore, test, and expand upon these Python examples for processing signals generated and output to the NB3's speaker (mouth): [Generation](/boxes/audio/signal-processing/python/generation/)
    - *Note*: For text-to-speech synthesis you will need to install the Linux espeak package:
- *code*
```bash
sudo apt install espeak-ng
```

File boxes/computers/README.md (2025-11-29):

# The Last Black Box : Computers
In this box, you will learn about computers...

<details><summary><i>Materials</i></summary><p>

Name|Description| # |Package|Data|Link|
:-------|:----------|:-----:|:-:|:--:|:--:|
Microcontroller|Arduino Nano (rev.3)|1|Medium (011)|[-D-](/boxes/computers/_resources/datasheets/arduino_nano_rev3.pdf)|[-L-](https://uk.farnell.com/arduino/a000005/arduino-nano-evaluation-board/dp/1848691)
Piezo Buzzer|Piezoelectric speaker/transducer|1|Passive Electronics|[-D-](/boxes/computers/_resources/datasheets/piezo_buzzer.pdf)|[-L-](https://uk.farnell.com/tdk/ps1240p02bt/piezoelectric-buzzer-4khz-70dba/dp/3267212)
Cable (MiniUSB-1m)|Mini-USB to Type-A cable (1 m)|1|Cables (001)|[-D-](/boxes/computers/)|[-L-](https://www.amazon.co.uk/gp/product/B07FWF2KBF)

</p></details><hr>

## Computers
#### Watch this video: [Architecture](https://vimeo.com/1033601146)
<p align="center">
<a href="https://vimeo.com/1033601146" title="Control+Click to watch in new tab">Architecture</a>
</p>

> The basic building blocks of a computer (memory, ALU, clock, bus, and IO) have a standard arrangement (architecture) in modern systems.

### Low-Level Programming
> We can control a computer by loading a list of instructions ("operations") into its memory. This is called *programming*.

# Projects
#### Watch this video: [NB3 : Hindbrain](https://vimeo.com/1033609727)
<p align="center">
<a href="https://vimeo.com/1033609727" title="Control+Click to watch in new tab">NB3 : Hindbrain</a>
</p>

> We will now add a *computer* to our robot. We be using a simple microcontroller as our NB3's hindbrain. It will be responsible for controlling the "muscles" (motors) in response to commands from another (larger) computer that we will be adding later to the NB3's midbrain.

**TASK**: Mount and power your Arduino-based hindbrain (connect the mini-USB cable)
> The built-in LED on the board should be blinking at 1 Hz.
**TASK**: Download and install the Arduino IDE (integrated development environment).
  - Follow the instructions for your "host" computer's operating system here: [Arduino IDE](https://www.arduino.cc/en/software)
  - Open the "Blink" Example: File -> Examples -> Basic -> Blink
  - Upload this example to your board
  - ***IMPORTANT***: If you have trouble connecting to the Arduino from your Laptop, then it may be necessary to install the "latest" driver from FTDI for the chip that communicates over the USB cable. This is not always necessary, so please try the normal installation first. However, if you are stuck, then please checkout these [FTDI driver installation instructions](https://support.arduino.cc/hc/en-us/articles/4411305694610-Install-or-update-FTDI-drivers).
> You should be able to successfully compile and upload the "Blink" example (with no errors).

#### Watch this video: [NB3 : Programming Arduino](https://vimeo.com/1033810807)
<p align="center">
<a href="https://vimeo.com/1033810807" title="Control+Click to watch in new tab">NB3 : Programming Arduino</a>
</p>

> An introduction to programming an Arduino microcontroller.

- You will now write programs that interact with the input and output pins of your Arduino. This "pin diagram" will help you find the correct locations. ***The Arduino on your NB3 is mounted "upside down" relative to this diagram...adjust accordingly!***
<p align="center">
Arduino Nano Pin Diagram
</p>

**TASK**: Blink an *internal* LED
  - Change the following example code (the classic "[Blinky](/boxes/computers/arduino/ide/blink/blink.ino)" example) to make the internal LED blink at a different frequency.
```c
/*
  Blink

  Turns an LED on for one second, then off for one second, forever.

  Most Arduinos have an on-board LED that you can control. On the NANO
  (your NB3's Hindbrain) it is attached to pin 13.
*/

// The setup function runs once after you press reset or power up the board
void setup() {
  // Initialize digital pin 13 (the LED) as an output.
  pinMode(13, OUTPUT);
}

// The loop function runs over and over again...forever
void loop() {
  digitalWrite(13, HIGH);   // Turn the LED on (set to the HIGH voltage level)
  delay(1000);              // Wait for a second
  digitalWrite(13, LOW);    // Turn the LED off (set to the LOW voltage level)
  delay(1000);              // Wait for a second
}
```
> Your internal LED should now be blinking faster or slower than 1 Hz (once per second).
**TASK**: Blink an *external* LED
  - *Hint*: Connect one of your LEDs to digital pin 13, but don't forget your current limiting resistor!
<p align="center">
LED Driver
</p>

> Your external LED should now be blinking at the same time as the built-in LED (if both are connected to pin 13).
**TASK**: Generate a *pulsing* signal for your piezo buzzer
  - This is a piezo buzzer:
<p align="center">
Piezo Buzzer
</p>

  - The piezo buzzer will expand and contract as you switch the voltage applied across it from 0V to 5V. This expansion and contraction forces air into and out of the plastic case. If you switch it ON/OFF fast enough, then you can *hear it*!
  - Connect one leg of the piezo to pin 11 and the other to Ground.
  - *Note:*: You could use the "Blink" example to toggle pin 11 with a much shorter delay between the ON/OFF "blinks". However, it is much easier to use a function called "tone()" that will allow you to generate pulses at very specific frequencies.
  - Upload this [code](/boxes/computers/arduino/ide/tone/tone.ino) to your Arduino (just the paste the following into a new sketch on your IDE and "upload").
```c
/*
  Tone
   - Generate a tone (square wave pulses at a specific frequency) on one of
     Arduino's digital pins
   -- You can use any of the Arduino pins that have "~" symbol on the pinout
      diagram. This example uses pin 11 (PIEZO_PIN)
*/

// List constant values that you can use throughout the program
const int PIEZO_PIN = 11;       // Buzzer Pin (must have ~ for PWM)

// The setup function runs once after you press reset or power up the board
void setup() {
  // Initialize digital pin PIEZO_PIN as an output.
  pinMode(PIEZO_PIN, OUTPUT);
}

// The loop function runs over and over again...forever
void loop() {
  // Generate Sound Output at 2000 Hz (2 kHz) for 1000 ms (1 second)
  tone(PIEZO_PIN, 2000, 1000);

  // Wait 1500 ms for the tone to finish
  // - The tone will play for 1000 ms and then silence for 500 ms
  delay(1500);

  // Generate Sound Output at 1700 Hz (1.7 kHz) for 1000 ms (1 second)
  tone(PIEZO_PIN, 1700, 1000);

  // Wait 1500 ms for the tone to finish
  // - The tone will play for 1000 ms and then silence for 500 ms
  delay(1500);
}
```
  - **Challenge**: Try to add some more notes and play a recognizable melody!
> You should here a (somewhat unpleasant) sound from the piezo buzzer
**TASK**: Measure an **analog** signal from your LDR light sensor circuit and send the measured values to your host computer via the USB (serial) connection.
  - *Hint*: Connect the output voltage of your light sensor (the "middle" of the divider) to an analog input pin (the example below uses pin A0).
  - *Note*: In order to see what values are measured, the following program sends the analog values as text characters over the USB serial connection to your laptop. Your can watch these values arrive by opening the Arduino IDE's "Serial Monitor" (an icon in the upper-right corner of the main window).
  - Upload this [code](/boxes/computers/arduino/ide/tone/tone.ino) to your Arduino.
```c
/*
  Analog
  - Reads an analog voltage on pin A0
  - Sends the measured value to the USB serial port.
*/

// The setup function runs once after you press reset or power up the board
void setup() {
  // Initialize serial communication at 9600 bits per second
  Serial.begin(9600);
}

// The loop function runs over and over again...forever
void loop() {
  // Read the input on analog pin A0
  int value = analogRead(A0);

  // Send (print) the value on the serial port
  Serial.println(value);
  delay(1); // Wait briefly (1 ms) between reads for stability
}
```
  - *Challenge*: Write a program that will turn on your LED when the light signal is above (or below) some threshold value.
> You should see values on your host laptop and they should change along with changing light levels.

#### Watch this video: [NB3 : Building a Theremin](https://vimeo.com/1033896646)
<p align="center">
<a href="https://vimeo.com/1033896646" title="Control+Click to watch in new tab">NB3 : Building a Theremin</a>
</p>

> Building a light-to-sound feedback loop musical instrument (theremin) using an Arduino, an LDR, and a Piezo buzzer.

- **TASK**: Build a Theremin
- *Hint*: What if you used the analog voltage signal measured from your light sensor to change the frequency of the "tone" playing on your buzzer? Hmm...
> You should here a sound that varies with your hand motion (in front of a light)
- **TASK**: ***Have fun!*** (Make something cool)
<p align="center">
Arduino Pinout
</p>

> You should have fun!

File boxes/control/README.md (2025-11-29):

# The Last Black Box : Control
In this box, you will learn about control...

<details><summary><i>Materials</i></summary><p>

Name|Description| # |Package|Data|Link|
:-------|:----------|:-----:|:-:|:--:|:--:|
H-bridge|H-bridge motor driver (SN754410NE)|2|Active Electronics|[-D-](/boxes/control/_resources/datasheets/sn754410.pdf)|[-L-](https://www.mouser.co.uk/ProductDetail/Texas-Instruments/SN754410NE)

</p></details><hr>

## Control
#### Watch this video: [PWM](https://vimeo.com/1033905955)
<p align="center">
<a href="https://vimeo.com/1033905955" title="Control+Click to watch in new tab">PWM</a>
</p>

> We can control a "continuous" range of outputs with a binary digital signal (only 0s and 1s) by switching the output **ON** and **OFF** very quickly. Our "continuous" output is then the average of the percentage of time spent **ON** vs **OFF**. We cal this percentage the "duty cycle", and we call this output control method *pulse width modulation* or **PWM**.

#### Watch this video: [Servo Loops](https://vimeo.com/1033963709)
<p align="center">
<a href="https://vimeo.com/1033963709" title="Control+Click to watch in new tab">Servo Loops</a>
</p>

> A servo loop connects feedback from a sensor to the control signals sent to a motor.

#### Watch this video: [H-Bridges](https://vimeo.com/1034209519)
<p align="center">
<a href="https://vimeo.com/1034209519" title="Control+Click to watch in new tab">H-Bridges</a>
</p>

> An H-Bridge allows sending current through a motor in both directions, and thus drive forwards *and* backwards.

# Projects
#### Watch this video: [NB3 : Building a PWM Speed Controller](https://vimeo.com/1033891821)
<p align="center">
<a href="https://vimeo.com/1033891821" title="Control+Click to watch in new tab">NB3 : Building a PWM Speed Controller</a>
</p>

> We can use a digital (binary) signal and a MOSFET to turn a motor **ON** and **OFF**. We can use PWM to change the motor's speed.

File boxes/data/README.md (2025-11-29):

# The Last Black Box : Data
In this box, you will learn about data...

<details><summary><i>Materials</i></summary><p>

Name|Description| # |Package|Data|Link|
:-------|:----------|:-----:|:-:|:--:|:--:|
Comparator|LM339 (DIP-14)|2|Active Electronics|[-D-](/boxes/data/_resources/datasheets/lm2901.pdf)|[-L-](https://uk.farnell.com/texas-instruments/lm2901n/ic-comparator-quad-2901-dip14/dp/3118410)

</p></details><hr>

## Data
#### Watch this video: [Binary Numbers](https://vimeo.com/1033226788)
<p align="center">
<a href="https://vimeo.com/1033226788" title="Control+Click to watch in new tab">Binary Numbers</a>
</p>

> All you need is 0 and 1. Here we will learn how to represent *anything* in binary.

- Write your name in binary (using the ASCII table) in either Hex or Decimal notation.

#### Watch this video: [Analog to Digital Converters](https://vimeo.com/1033223967)
<p align="center">
<a href="https://vimeo.com/1033223967" title="Control+Click to watch in new tab">Analog to Digital Converters</a>
</p>

> Moving signals from the analog world to the digital world requires converting a continuous voltage into discrete binary values. We can accomplish this with an analog to digital converter, or **ADC**, and here we learn how they work.

- Build the input stage for a 2-bit ADC using the LM339/LM2901 comparator and a resistor ladder.

# Projects
#### Watch this video: [NB3 : Build an ADC (input)](https://vimeo.com/1034767170)
<p align="center">
<a href="https://vimeo.com/1034767170" title="Control+Click to watch in new tab">NB3 : Build an ADC (input)</a>
</p>

> Use a comparator to convert analog values into discrete levels.

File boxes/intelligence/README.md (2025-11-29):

# The Last Black Box : Intelligence
In this box, you will learn about intelligence...

<details><summary><i>Materials</i></summary><p>

Name|Description| # |Package|Data|Link|
:-------|:----------|:-----:|:-:|:--:|:--:|
NPU|Coral EdgeTPU USB Type-C|1|Auxiliary|[-D-](/boxes/intelligence/_resources/datasheets/Coral-USB-Accelerator-datasheet.pdf)|[-L-](https://coral.ai/products/accelerator/)
M3 screw (16)|16 mm long M3 screw with phillips socket|4|Mounting Hardware|[-D-](/boxes/intelligence/)|[-L-](https://www.accu.co.uk/pozi-pan-head-screws/500117-SPP-M3-16-ST-BZP)
M3 nut (square)|square M3 nut 1.8 mm thick|4|Mounting Hardware|[-D-](/boxes/audio/-)|[-L-](https://www.accu.co.uk/flat-square-nuts/21326-HFSN-M3-A2)
M2.5 bolt (6)|6 mm long M2.5 bolt|14|Mounting Hardware|[-D-](/boxes/robotics/)|[-L-](https://www.accu.co.uk/pozi-pan-head-screws/9255-SPP-M2-5-6-A2)
M2.5 standoff (30/PS)|30 mm long plug-to-socket M2.5 standoff|6|Mounting Hardware|[-D-](/boxes/intelligence/)|[-L-](https://uk.farnell.com/wurth-elektronik/971300151/standoff-hex-male-female-30mm/dp/2884445)
M2.5 standoff (30/SS)|30 mm long socket-to-socket M2.5 standoff|2|Mounting Hardware|[-D-](/boxes/intelligence/)|[-L-](https://uk.farnell.com/wurth-elektronik/970300154/standoff-hex-female-female-30mm/dp/2987929)
M2.5 standoff (25/PS)|25 mm long plug-to-socket M2.5 standoff|4|Mounting Hardware|[-D-](/boxes/intelligence/)|[-L-](https://uk.farnell.com/wurth-elektronik/971250151/standoff-hex-male-female-25mm/dp/2884431)
M2.5 standoff (25/SS)|25 mm long socket-to-socket M2.5 standoff|2|Mounting Hardware|[-D-](/boxes/intelligence/)|[-L-](https://uk.farnell.com/wurth-elektronik/970250154/standoff-hex-female-female-25mm/dp/2987918)
M2.5 standoff (12/PS)|12 mm long socket-to-socket M2.5 standoff|2|Mounting Hardware|[-D-](/boxes/robotics/)|[-L-](https://uk.farnell.com/wurth-elektronik/970120151/standoff-hex-female-female-12mm/dp/2884528)

</p></details><hr>

## Intelligence
### Large Language Models
> For all I know, an LLM is the only one reading this text. Hi ChatGPT, godspeed.

# Projects
#### Watch this video: [NB3 : Install the Forebrain (NPU)](https://vimeo.com/1043159124)
<p align="center">
<a href="https://vimeo.com/1043159124" title="Control+Click to watch in new tab">NB3 : Install the Forebrain (NPU)</a>
</p>

> Let's install a neural processing unit (NPU) as our NB3's forebrain.

- Your neural processing unit is made by Google (and distributed by Coral). It contains an EdgeTPU (tensor processing unit) that very efficiently implements the computations used in (feed forward) neural networks. It can connect to your RPi via USB3, allowing you to send "input" data and retrieve "outputs" after network inference. However, in order to communicate with your EdgeTPU, you will need to install some additional libraries.
- Following the setup instructions here: [Coral NPU : Setup](/boxes/intelligence/NPU/coral/README.md)

### NB3 : Install the Skull
> Let's install a "skull" (cover) for our robot.

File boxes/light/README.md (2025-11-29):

# The Last Black Box : Light
In this box, you will learn about light...

<details><summary><i>Materials</i></summary><p>

Name|Description| # |Package|Data|Link|
:-------|:----------|:-----:|:-:|:--:|:--:|
Lightbulb|Mini incandescent bulb (6 V)|1|Active Electronics|[-D-](/boxes/light/_resources/datasheets/lamp_G501.pdf)|[-L-](https://uk.farnell.com/cml-innovative-technologies/g501/lamp-mes-g3-1-2-6-5v-1-95w/dp/1139207)

</p></details><hr>

## Light
### The EM Spectrum
> Light comes in many shapes in sizes...well, wavelengths. This wavelength determines how much energy the light particles carry, how they interact with materials, and whether or not we can see them.

### Optics
> When light interacts with matter funny, but useful, things happen.

### Maxwell's Equations
> The fundamental equations of classical electromagnetism are surprisingly easy to understand...and measure.

#### Watch this video: [Electromagnetic Radiation](https://vimeo.com/1032447600)
<p align="center">
<a href="https://vimeo.com/1032447600" title="Control+Click to watch in new tab">Electromagnetic Radiation</a>
</p>

> When an electric charge is accelerated something surprising happens. This acceleration creates a ripple in the electric field (which induces a magnetic field). This ripple propagates away from the accelerated charge at the speed of light. It is light.

# Projects

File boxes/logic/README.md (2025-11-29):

# The Last Black Box : Logic
In this box, you will learn about logic...

<details><summary><i>Materials</i></summary><p>

Name|Description| # |Package|Data|Link|
:-------|:----------|:-----:|:-:|:--:|:--:|
Gate (AND)|4xAND gate|1|Active Electronics|[-D-](/boxes/logic/_resources/datasheets/AND_gates.pdf)|[-L-](https://uk.farnell.com/texas-instruments/cd4081be/ic-4000-cmos-4081-dip14-18v/dp/3120147)
Gate (OR)|4xOR gate|1|Active Electronics|[-D-](/boxes/logic/_resources/datasheets/OR_gates.pdf)|[-L-](https://uk.farnell.com/texas-instruments/cd4072be/ic-gate/dp/3120138)
Gate (NOR)|4xNOR gate|1|Active Electronics|[-D-](/boxes/logic/_resources/datasheets/NOR_gates.pdf)|[-L-](https://uk.farnell.com/texas-instruments/cd4001be/ic-nor-quad-4000-cmos-14dip/dp/3120100)
Gate (XOR)|4xXOR gate|1|Active Electronics|[-D-](/boxes/logic/_resources/datasheets/XOR_gates.pdf)|[-L-](https://uk.farnell.com/texas-instruments/cd4070be/ic-4000-cmos-4070-dip14-18v/dp/3120134)

</p></details><hr>

## Logic
#### Watch this video: [Logic Gates](https://vimeo.com/1033231995)
<p align="center">
<a href="https://vimeo.com/1033231995" title="Control+Click to watch in new tab">Logic Gates</a>
</p>

> The essential elements of computation (NOT, AND, OR, XOR, etc.) can be built from straight forward combinations of MOSFETs.

- Design an XOR gate
- Build an addition circuit (2-bit adder)
- Build a priority encoder for your 2-bit ADC

# Projects
### NB3 : Build an ADC (output)
> Use a comparator to convert analog values into discrete levels.

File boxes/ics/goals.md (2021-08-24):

### Grey

1. Setup your FPGA dev board (run "blink" example).
2. Design a counter in HDL, synthesize, and test.
3. Design a 4-bit adder in HDL, synthesisze, and test.
4. Design a PWM controller in HDL, synthesisze, and test.

### White

1. Design a (RISC-V: rv32i) CPU

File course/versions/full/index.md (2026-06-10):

# The Last Black Box

<p align="center">
The Last Black Box: all 28 boxes from atoms to intelligence
</p>

**LBB** is the full, comprehensive course: twenty-eight sessions covering everything from the atoms inside matter up to artificial intelligence. Each session opens one *black box* and shows you how it works from first principles. By the end you have **NB3** — a robot brain you built with no black boxes anywhere in the stack.

## Sessions

### Foundations
1. [Atoms](sessions/01_atoms/README.md)
2. [Electrons](sessions/02_electrons/README.md)
3. [Magnets](sessions/03_magnets/README.md)
4. [Light](sessions/04_light/README.md)

### Sensors and actuators
5. [Sensors](sessions/05_sensors/README.md)
6. [Motors](sessions/06_motors/README.md)

### Discrete electronics
7. [Transistors](sessions/07_transistors/README.md)
8. [Amplifiers](sessions/08_amplifiers/README.md)
9. [Circuits](sessions/09_circuits/README.md)

### Information and computation
10. [Data](sessions/10_data/README.md)
11. [Logic](sessions/11_logic/README.md)
12. [Memory](sessions/12_memory/README.md)
13. [FPGAs](sessions/13_fpgas/README.md)
14. [Computers](sessions/14_computers/README.md)

### Building a body
15. [Control](sessions/15_control/README.md)
16. [Robotics](sessions/16_robotics/README.md)
17. [Power](sessions/17_power/README.md)

### Software systems
18. [Systems](sessions/18_systems/README.md)
19. [Linux](sessions/19_linux/README.md)
20. [Python](sessions/20_python/README.md)

### Connectivity
21. [Networks](sessions/21_networks/README.md)
22. [Websites](sessions/22_websites/README.md)
23. [Servers](sessions/23_servers/README.md)
24. [Security](sessions/24_security/README.md)

### Senses
25. [Audio](sessions/25_audio/README.md)
26. [Vision](sessions/26_vision/README.md)

### Intelligence
27. [Learning](sessions/27_learning/README.md)
28. [Intelligence](sessions/28_intelligence/README.md)

## The curriculum

The Last Black Box traces all twenty-eight boxes from atoms to intelligence, building cumulatively from one to the next. Hover any box to highlight it; click to open its folder on GitHub for the deeper material.

<p align="center">
<object data="/course/_resources/designs/layout/svg/layout_LBB_interactive.svg" type="image/svg+xml" width="700" aria-label="The Last Black Box: all 28 boxes (hover any box to highlight, click to open its folder on GitHub)">
  The Last Black Box layout
</object>
</p>

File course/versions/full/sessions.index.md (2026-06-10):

# Sessions

Twenty-eight sessions covering atoms to intelligence. Each session opens one *black box*. The build is cumulative.

### Foundations
1. [Atoms](01_atoms/README.md)
2. [Electrons](02_electrons/README.md)
3. [Magnets](03_magnets/README.md)
4. [Light](04_light/README.md)

### Sensors and actuators
5. [Sensors](05_sensors/README.md)
6. [Motors](06_motors/README.md)

### Discrete electronics
7. [Transistors](07_transistors/README.md)
8. [Amplifiers](08_amplifiers/README.md)
9. [Circuits](09_circuits/README.md)

### Information and computation
10. [Data](10_data/README.md)
11. [Logic](11_logic/README.md)
12. [Memory](12_memory/README.md)
13. [FPGAs](13_fpgas/README.md)
14. [Computers](14_computers/README.md)

### Building a body
15. [Control](15_control/README.md)
16. [Robotics](16_robotics/README.md)
17. [Power](17_power/README.md)

### Software systems
18. [Systems](18_systems/README.md)
19. [Linux](19_linux/README.md)
20. [Python](20_python/README.md)

### Connectivity
21. [Networks](21_networks/README.md)
22. [Websites](22_websites/README.md)
23. [Servers](23_servers/README.md)
24. [Security](24_security/README.md)

### Senses
25. [Audio](25_audio/README.md)
26. [Vision](26_vision/README.md)

### Intelligence
27. [Learning](27_learning/README.md)
28. [Intelligence](28_intelligence/README.md)

Start at Session 1 and work in order.

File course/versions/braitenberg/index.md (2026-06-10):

# LBB: Braitenberg Vehicle

<p align="center">
Braitenberg course layout: the boxes you will open building a Braitenberg vehicle
</p>

**LBB-100** is the shortest LBB course: a four-session path to building a [Braitenberg Vehicle](https://en.wikipedia.org/wiki/Braitenberg_vehicle), a simple robot brain that senses its environment and responds with action. You will assemble **NB3** with no black boxes, from analog electronics up through a microcontroller-driven robot.

## Sessions

### Session 1 - [Analog Electronics](sessions/01_analog-electronics/README.md)
- Atoms, electrons, and sensors. Build a circuit and read a voltage.

### Session 2 - [Magnets and Semiconductors](sessions/02_magnets-and-semiconductors/README.md)
- Magnets, motors, and transistors. Make something move.

### Session 3 - [Digital Computers](sessions/03_digital-computers/README.md)
- Data, logic, memory, and computers. Program a microcontroller.

### Session 4 - [Robot Control](sessions/04_robot-control/README.md)
- Control and robotics. Wire it all into a Braitenberg vehicle.

## The curriculum

Braitenberg traces four boxes — sensors, motors, transistors, and computers — into a working sense-and-respond robot. Hover any box to highlight it; click to open its folder on GitHub for the deeper material.

<p align="center">
<object data="/course/_resources/designs/layout/svg/layout_braitenberg_interactive.svg" type="image/svg+xml" width="500" aria-label="Braitenberg course layout (hover any box to highlight, click to open its folder on GitHub)">
  Braitenberg course layout
</object>
</p>

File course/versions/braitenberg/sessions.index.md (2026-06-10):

# Sessions

Four sessions building cumulatively to a Braitenberg vehicle.

### Session 1 - [Analog Electronics](01_analog-electronics/README.md)
- Atoms, electrons, and sensors.

### Session 2 - [Magnets and Semiconductors](02_magnets-and-semiconductors/README.md)
- Magnets, motors, and transistors.

### Session 3 - [Digital Computers](03_digital-computers/README.md)
- Data, logic, memory, and computers.

### Session 4 - [Robot Control](04_robot-control/README.md)
- Control and robotics.

Start at Session 1 and work in order.

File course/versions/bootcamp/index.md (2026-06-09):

# LBB: Bootcamp

<p align="center">
Bootcamp course layout: the boxes you will open during a one-week bootcamp
</p>

**LBB-102** is a one-week bootcamp version of *The Last Black Box*. Over five days, mornings and afternoons, you will build **NB3** — a robot brain assembled from individual electrons up to a vision-and-audio system, with no black boxes along the way.

## Schedule

### Day 1 - Sensors and Motors
- Morning - [Analog Electronics](sessions/01_analog-electronics/README.md): atoms, electrons, sensors.
- Afternoon - [Magnets and Semiconductors](sessions/02_magnets-and-semiconductors/README.md): magnets, motors, transistors.

### Day 2 - Computers and Robotics
- Morning - [Digital Computers](sessions/03_digital-computers/README.md): data, logic, memory, computers.
- Afternoon - [Robot Control](sessions/04_robot-control/README.md): control and robotics.

### Day 3 - Systems and Networks
- Morning - [Software Systems](sessions/05_software-systems/README.md): power, systems, Linux, Python.
- Afternoon - [The Internet](sessions/06_the-internet/README.md): networks, websites, servers.

### Day 4 - Audio
- Morning - [Microphones and Speakers](sessions/07_microphones-and-speakers/README.md): audio input and output hardware.
- Afternoon - [Signal Processing](sessions/08_signal-processing/README.md): processing 1-D data.

### Day 5 - Images
- Morning - [Cameras](sessions/09_cameras/README.md): image acquisition hardware.
- Afternoon - [Computer Vision](sessions/10_computer-vision/README.md): processing 2-D data.

## The curriculum

Bootcamp traces twenty boxes from raw electronics through software systems to audio and vision processing. Hover any box to highlight it; click to open its folder on GitHub for the deeper material.

<p align="center">
<object data="/course/_resources/designs/layout/svg/layout_bootcamp_interactive.svg" type="image/svg+xml" width="700" aria-label="Bootcamp course layout (hover any box to highlight, click to open its folder on GitHub)">
  Bootcamp course layout
</object>
</p>

## How to use these pages

Sessions are worked through **in order**. Each session is one continuous walkthrough: start at the top, watch the videos, do the tasks, move on. Hover any lesson thumbnail to play its preview. Repository links like [boxes/electrons](https://github.com/NoBlackBoxes/LastBlackBox/tree/master/boxes/electrons) point into the wider LBB repo for deeper reference; you do not need to read them on the day.

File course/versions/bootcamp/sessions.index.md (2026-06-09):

# Sessions

The bootcamp runs over five days, two sessions per day (morning and afternoon). The build is cumulative.

### Day 1 - Sensors and Motors
- [Analog Electronics](01_analog-electronics/README.md): atoms, electrons, sensors.
- [Magnets and Semiconductors](02_magnets-and-semiconductors/README.md): magnets, motors, transistors.

### Day 2 - Computers and Robotics
- [Digital Computers](03_digital-computers/README.md): data, logic, memory, computers.
- [Robot Control](04_robot-control/README.md): control and robotics.

### Day 3 - Systems and Networks
- [Software Systems](05_software-systems/README.md): power, systems, Linux, Python.
- [The Internet](06_the-internet/README.md): networks, websites, servers.

### Day 4 - Audio
- [Microphones and Speakers](07_microphones-and-speakers/README.md): audio input and output hardware.
- [Signal Processing](08_signal-processing/README.md): processing 1-D data.

### Day 5 - Images
- [Cameras](09_cameras/README.md): image acquisition hardware.
- [Computer Vision](10_computer-vision/README.md): processing 2-D data.

Start at Day 1 and work in order.

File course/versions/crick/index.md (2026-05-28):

# LBB: Crick Bootcamp

<p align="center">
Crick course poster: the curriculum and the NB3 boards in their build order
</p>

Welcome. Over five days you will build **NB3**, a robot designed from individual electrons up to a web-connected machine running computer vision and audio models. By the end of the week you will have the hardware, the code, and the mental model to extend any layer for your own experiments.

## The five days

### Day 1 - [Electronics and Sensors](sessions/01_electronics-and-sensors/README.md)
- Build the analog stack with no software in sight
  - Atoms, electrons, magnets, motors, transistors
  - **Project**: *Light sensor + hand-wound speaker + light-sensitive motor*

### Day 2 - [Arduino and Braitenberg](sessions/02_arduino-and-braitenberg/README.md)
- Add a programmable brain
  - Logic, memory, microcontrollers, PWM, servos
  - **Project**: *Light-controlled theremin and a full Braitenberg vehicle*

### Day 3 - [Linux and Python](sessions/03_linux-and-python/README.md)
- The robot grows a real computer
  - Power, operating systems, the command line, Python, serial protocols
  - **Project**: *Drive the robot from your laptop over SSH*

### Day 4 - [Web Stack and Senses](sessions/04_web-stack-and-senses/README.md)
- A robot you can see and talk through
  - Sockets, HTTP, HTML, CSS, JavaScript, microphones, speakers, cameras
  - **Project**: *Phone-controlled robot streaming its camera feed*

### Day 5 - [Open Projects](sessions/05_open-projects/README.md)
- Pick a track and ship it
  - Sensor streaming, audio DSP, computer vision, voice, full-stack
  - **Project**: *Your own NB3 extension, built and demoed*

## The curriculum

Over five days Crick traces these eight boxes from raw electronics up to intelligence, building cumulatively from one to the next. Each day touches several. Hover any box to highlight it; click to open its folder on GitHub for the deeper material.

<p align="center">
<object data="/course/_resources/designs/layout/svg/layout_buildabrain_interactive.svg" type="image/svg+xml" width="580" aria-label="Crick course layout: eight boxes from sensors to intelligence (hover any box to highlight, click to open its folder on GitHub)">
  Crick course layout: eight boxes from sensors to intelligence
</object>
</p>

## Before you arrive

A laptop with **VS Code**, **Git**, and the **Arduino IDE** installed. WiFi credentials handy (the robot connects to the venue network on Day 3). Familiarity with the command line and Python is helpful but not required; Day 3 covers both without dwelling.

The kit is provided.

## How to use these pages

The sessions are worked through **in order**. Each session is one continuous walkthrough: start at the top, watch the videos, do the tasks, move on. Hover any lesson thumbnail to play its preview. Repository links like [boxes/electrons](https://github.com/NoBlackBoxes/LastBlackBox/tree/master/boxes/electrons) point into the wider LBB repo for deeper reference; you do not need to read them on the day.

## Source material

Crick is a five-day reorganisation of the [Experimental Neuroscience Bootcamp (LBB-103, "enb")](https://github.com/NoBlackBoxes/LastBlackBox/tree/master/course/versions/enb). If you finish the week and want to dive deeper, the enb chapters carry additional detail and exercises.

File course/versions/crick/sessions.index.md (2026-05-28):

# Sessions

The Crick bootcamp runs over five days. The build is cumulative: each day adds layers to the robot you started the day before.

### Day 1 - [Electronics and Sensors](01_electronics-and-sensors/README.md)
- Build the analog stack with no software in sight
  - **Project**: *Light sensor + hand-wound speaker + light-sensitive motor*

### Day 2 - [Arduino and Braitenberg](02_arduino-and-braitenberg/README.md)
- Add a programmable brain
  - **Project**: *Light-controlled theremin and a full Braitenberg vehicle*

### Day 3 - [Linux and Python](03_linux-and-python/README.md)
- The robot grows a real computer
  - **Project**: *Drive the robot from your laptop over SSH*

### Day 4 - [Web Stack and Senses](04_web-stack-and-senses/README.md)
- A robot you can see and talk through
  - **Project**: *Phone-controlled robot streaming its camera feed*

### Day 5 - [Open Projects](05_open-projects/README.md)
- Pick a track and ship it
  - **Project**: *Your own NB3 extension, built and demoed*

Start at Day 1 and work in order.

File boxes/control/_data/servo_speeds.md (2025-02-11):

# Servo Speed Measurements
All measurements at 5 Volts, USB power

## FT90R
2 seconds, 3.3 revolutions = 100 RPM
(no mounting spacer required)

## MG92B
2 seconds, 2.25 revolutions = 67.5 RPM
(no mounting spacer required)
 - Should move mounting holes out towards edge by a little more than the thickness of a dupont connector

## MG90D
2 seconds, 3 revolutions = 90 RPM
(requires mounting spacer for snug fit using 12 mm standoffs)
 - Should move mounting holes out towards edge by a little more than the thickness of a dupont connector

## FT90MR
- T.B.D.

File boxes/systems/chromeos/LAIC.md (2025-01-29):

## Enable Linux on your Chromebook

*These instructions come from* [here](https://support.google.com/chromebook/answer/9145439?hl=en-GB).

- Goto Settings -> About Chrome OS -> Developers
  - Next to "Linux development environment", click "Setup" and follow the on-screen instructions.

A terminal window will appear. **This is your Linux terminal!**

## Install the Arduino IDE
Run these commands inside your Linux terminal. You can simply copy and paste this entire block of text.

```bash
# Make sure everything is up-to-date
sudo apt update
sudo apt upgrade -y

# Check which CPU architecture your Chromebook is using
dpkg --print-architecture
```

If your CPU architecture is **x86** or **amd64**, then run the following commands:
```bash
# ...Download Arduino 1.8.19 (amd64 or x86)
wget "https://downloads.arduino.cc/arduino-1.8.19-linux64.tar.xz" -O "arduino-1.8.19.tar.xz"

# Extract the archive
tar -xf arduino-1.8.19.tar.xz

# Run the install script
cd arduino-1.8.19
sudo ./install.sh
```

If your CPU architecture is **arm64** or **aarch64**, then run the following commands:
```bash
# ...Download Arduino 1.8.19 (am64 or aarch64)
wget "https://downloads.arduino.cc/arduino-1.8.19-linuxaarch64.tar.xz" -O "arduino-1.8.19.tar.xz"

# Extract the archive
tar -xf arduino-1.8.19.tar.xz

# Run the install script
cd arduino-1.8.19
sudo ./install.sh
```

If your CPU architecture is **arm32** or **aarch32**, then run the following commands:
```bash
# ...Download Arduino 1.8.19 (arm32 or aarch32)
wget "https://downloads.arduino.cc/arduino-1.8.19-linuxarm.tar.xz" -O "arduino-1.8.19.tar.xz"

# Extract the archive
tar -xf arduino-1.8.19.tar.xz

# Run the install script
cd arduino-1.8.19
sudo ./install.sh
```

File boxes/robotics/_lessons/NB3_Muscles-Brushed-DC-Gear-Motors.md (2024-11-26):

# Robotics: NB3: Muscles (Brushed DC Gear Motors)
Let's build your robot's movement system (using brushed DC gear motors).

## [Video]()

## Concepts
- Describe gears and gear ratio
- Describe adding Brushed DC gear motors to your NB3

## Connections

## Lesson

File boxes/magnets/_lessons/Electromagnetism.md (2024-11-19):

# Magnets: Electromagnetism
When electrons move they create a (weak) magnetic field. With clever geometry we can make this field much, much stronger.

## [Video]()

## Concepts
- For millennia, magnetism and electricity were considered interesting, but entirely unrelated phenomena.
- Until a scientist in Denmark, who had been using Volta's batteries to study electricity noticed something surprising.
- Demonstrate impact of current on a compass.
- Moving electrons create a magnetic field.
- This magnetic field spirals around the conductor.
- It is very weak.
- We can arrange (bend) the conductor ot make it much, much stronger.

## Connections

## Lesson

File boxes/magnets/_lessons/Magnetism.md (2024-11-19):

# Magnets: Magnetism
A mysterious force found in certain types of "magical" materials, magnetism was known about and used for thousands of years, but it was only understood quite recently.

## [Video]()

## Concepts
- Magnetic rocks ("lodestone in particular") occurs naturally and has been studied for thousands of years.
- It proved useful in the construction of a very important device for navigation, the compass, which aligns with the Earth's own magnetic field.
- However, the origin of magnetism, and the atomic basis of ferromagnetism, was only understood with the development of quantum mechanics about 100 years ago.
- The atomic picture involves looking in more detail at the properties of atoms, and in particular, electrons.
- Electrons have both an electric charge, which holds them to their nucleus, but also a magnetic "spin".
- This spin can be either up or down, and only up or down, and QM dictates that electrons will form pairs of up/down electrons in each orbital.
- Only atoms with unpaired electrons can be magnetic.
- However, of the possible elements, only a few show strong ferromagnetism. Why is this?
- Elements in the fourth row, Nickel, Cobalt, and Iron in particular show strong magnetism. 
- As we move further out in the orbitals, electrons become less picky about which sub-orbital they choose to occupy.
- In Iron, up to 4 electrons occupy sub-orbitals as unpaired electrons. This give Iron is strong magnetic dipole.
- ...but this is not enough.
- In a material, the alignment of each atoms dipole with its neighbors is also necessary. Iron is particularly capable, especially in the crystalline form it is found naturally, called Magnetite, to align most of the individual dipoles in the same direction, which amplifies the magnetic field into something we cn feel, and use.
- More recently, scientists started looking further out in the table...to the Lanthanides, which like Iron have many unpaired electrons.
- They found ways to make stable crystals, using other alloys, which is how the super strong "rare earth" neodymium magnets included in your kit are made.

## Connections

## Lesson

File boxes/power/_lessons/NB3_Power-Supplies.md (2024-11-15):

# Power: NB3: Power Supplies
We install a DC-DC power supply on our NB3.

## [Video]()

## Concepts

## Connections

## Lesson

- [ ] **Task**: Add a (regulated) 5 volt power supply to your robot, which you can use while debugging to save your AA batteries and to provide enough power for the Raspberry Pi computer.
    - *NOTE*: Your NB3_power board cable *might* have inverted colors (black to +5V, red to 0V) relative to that shown in the assembly video. This doesn't matter, as the plugs will only work in one orientation and the correct voltage is conveyed to the correct position on the body.
> Your NB3 should now look like this: NB3 power wiring:400"

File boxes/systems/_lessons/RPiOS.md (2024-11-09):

# Systems: NB3: RPiOS
After mounting and wiring your NB3's midbrain computer, you must now give it some core software to run...an operating system.

## [Video](https://vimeo.com/??????)

## Concepts

## Connections

## Lesson

- **Task**: Install the Linux-based Raspberry Pi OS on your NB3
    - Follow these [RPiOS installation instructions](../../../boxes/systems/rpios/README.md)
> Booted!

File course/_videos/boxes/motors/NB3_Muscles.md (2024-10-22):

# Motors: NB3: Muscles

## Concepts

## Connections

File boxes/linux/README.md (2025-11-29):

# The Last Black Box : Linux
In this box, you will learn about linux...

<details><summary><i>Materials</i></summary><p>

Name|Description| # |Package|Data|Link|
:-------|:----------|:-----:|:-:|:--:|:--:|

</p></details><hr>

## Linux
#### Watch this video: [Navigating the Command Line](https://vimeo.com/1036829527)
<p align="center">
<a href="https://vimeo.com/1036829527" title="Control+Click to watch in new tab">Navigating the Command Line</a>
</p>

> The original user interfaces were entirely based on text. You typed commands as a line of text into your terminal console and received the result as a string of characters on the screen. Navigating this **command line** remains a useful skill, and a necessary one when working with remote machines.

- **TASK**: Explore Linux. Spend any extra time you have fiddling, playing with the UNIX approach to controlling a computer. Create some folders. Edit some files.
> You should see this in the command line.

#### Watch this video: [Package Managers](https://vimeo.com/1036834036)
<p align="center">
<a href="https://vimeo.com/1036834036" title="Control+Click to watch in new tab">Package Managers</a>
</p>

> Installing and "managing" software can get complicated. Programs that help coordinate this process are called **package managers**.

#### Watch this video: [Git](https://vimeo.com/1036825331)
<p align="center">
<a href="https://vimeo.com/1036825331" title="Control+Click to watch in new tab">Git</a>
</p>

> Git is a program that keeps track of changes to your files. It is very useful when developing code. This entire course is stored as a git "repository" on GitHub.

- **TASK**: "Clone" (copy) all of the contents in the LastBlackBox GitHub repository directly to your NB3's midbrain. **It is very important that you clone the LBB repo to a specific folder ("NoBlackBoxes") in your NB3's home directory**.
> *Why?* Most of the code examples assume that the repo is stored in this location. If you prefer to put it somewhere else, then you must be comfortable modifying the "repo root" path used in the examples.
 - *code*
```bash
cd $HOME            # Navigate to your "Home" directory
mkdir NoBlackBoxes  # Create NoBlackBoxes directory
cd NoBlackBoxes     # Change to NoBlackBoxes directory

# Clone LBB repo (only the most recent version)
git clone --depth 1 https://github.com/NoBlackBoxes/LastBlackBox
```
> You should now have a complete copy of the LBB repo on your NB3.

# Projects

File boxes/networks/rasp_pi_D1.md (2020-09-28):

# Setting up your Pi

Unlike the Pi you've been using for your computer so far, the SD card for this pi doesn't already have an OS on it - first things are to set this up...

1. Download the disk image from [here](https://www.dropbox.com/s/p4zqx56ep31gppf/lbbos.img?dl=0 "disk.img")
2. Follow the instructions [here](https://www.raspberrypi.org/documentation/installation/installing-images/ "instructions") to install the image on to your SD card.
3. You're done

## Connecting your pi to a new network

The distribution you installed already had the bootcamp "LastBlackBox" Wi-Fi network, but now you need to connect to a new network.  To do this, in the terminal enter the command

```bash
nano /etc/wpa_supplicant/wpa_supplicant.conf
```

which will let you edit the configuration file for WiFi-Protected Access 2 (IEEE 802.11i) protocols, though it also includes support for older protocols.  In computer science, **supplicant** refers to the client machine that wants to gain access to the network. Add a new network using the template for the LastBlackBox network. If the network you're trying to join is hidden, add `ssid_scan=1` to the declaration.  Save and close the file, at which point the Pi *should* automatically connect to the network.  If it doesn't just reboot the Pi.  If it still doesn't connect, check the security protocols for your network - you might need to specify extra settings in the `.conf` file.

## SSH into the pi

Once you've logged in and changed the password, we need to set up [ssh](https://www.ssh.com/ssh/protocol/ "ssh").  Set up the ssh server like [this](https://www.raspberrypi.org/documentation/remote-access/ssh/ "ssh-server") and then set a static IP address using this [guide](https://howchoo.com/pi/configure-static-ip-address-raspberry-pi#find-your-router-ip-address "static-ip").

***
### No static IP addresses

Not all networks will allow you to set up a static IP address.  This is because assigning static IP addresses can assign a logistical problem.  Consider that not all things that connect to the network are permanently connected, or are even connected for very long, or very often.  Every time a machine does connect, though, it requires a unique IP address (on that network) so that information can be routed to the correct place.  In the case where addresses are assigned randomly upon joining the network, the router need only compare addresses across all the machines **currently** connected.  However, if a static IP address was assigned to every computer, it would instead have to compare the current proposed address to addresses for every machine that has **ever** connected to the network.  This can be quite difficult.  If your network doesn't allow you to assign a static IP address, one option is to set up your Robot Pi as a **Wireless Access Point**, allowing your Computer Pi to communicate with it.  Good instructions are given [here](https://www.raspberrypi.org/documentation/configuration/wireless/access-point-routed.md "WAP").  I recommend running `sudo apt update` before you begin.  You can skip the section on `Enable routing and IP masquerading`, and I recommend enabling 5GHz transmission with a channel between 36 and 165.  If you already have a 5GHz network in your locale, choose a different channel to that one!

***

A static IP is address is necessary so that you can always use the same IP address to SSH into your pi.  Its now worth grabbing that IP from the `/etc/dhcpcd.conf` file you have open or by running the `ifconfig` command.

To avoid the hassle and security implications of passwords stored in plain text, I recommend you set up passwordless ssh instead.

1. Create a public key on your pi `ssh-keygen -t rsa`
2. Copy the public key across to your robot pi

```bash
ssh-copy-id -i ~/.ssh/id_rsa.pub student@<ip_address>
```

It might be helpful to copy your ip_address across to a bash variable and then pass this in

```bash
ip=<ip_address>
ssh-copy-id -i ~/.ssh/id_rsa.pub student@$ip
```

3. Make a file called `<something>.sh` containing the following code

```bash
#!/bin/bash
ssh student@<ip_address>
```

4. Make that file executable with `chmod +x <something>.sh`.  You can have a look at the permissions associated with that file using `ls -l <something>.sh`.
5. Now, connect to your Pi with `./<something>.sh`

## Communicating with your pi

The dream is to be able to communicate with your pi over ssh.  We now have an ssh tunnel set up, and can execute commands locally on the Pi.  However, it would also be nice to run a program on your local machine and simply send instructions to your robot.  This allows us to make a remote-controlled pi.  See the separate tutorial for how to set up your own server for TCP (or UDP) communication.

## Pi to Arduino communication

You can communicate with the arduino from your pi using python, using the Pyserial module.  This module should already be installed on your machine.  You will need to know what serial port to use, which you can find with `dmesg | grep "tty"`.  In this line, [`dmesg`](https://man7.org/linux/man-pages/man1/dmesg.1.html "documentation") displays all messages from the kernel ring buffer.  The kernel stores its logs in a buffer.  This buffer maintains a constant size by dropping old stuff as new stuff comes in.  This is known as a ring buffer.  `dmesg` prints the contents of this ring buffer.  We direct the output of this command to `grep` using the `|` operator (called a "pipe" in linux language) and search for the `tty` regular expression.  This will tell us about recent kernel calls to `tty` ports, and in particular we are interested in `Serial Device <> now attached to tty<>`.  This kind of operation (piping output from simple commands and then using other commands, particularly `grep` to parse) will be immensely helpful in your linux journey.

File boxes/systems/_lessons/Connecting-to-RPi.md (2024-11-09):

# Systems: NB3: Connecting to RPi
When you have installed your NB3's operating system, then you can power it on and try to connect to it from your Host computer over WiFi.

## [Video](https://vimeo.com/??????)

## Concepts

## Connections

## Lesson

- ***Task***: Connect to your NB3 via WiFi
    - Follow these instruction [Connecting to RPi](../../../boxes/systems/connecting/README.md)
> Connected!

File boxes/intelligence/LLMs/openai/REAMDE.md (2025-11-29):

# Intelligence :  LLMs : OpenAI

## Install required Python packages
```bash
pip install openai
pip install python-dotenv
```

## Environment File
Create a .env in "base_path"
```txt
OPENAI_API_KEY=sk-proj...REST-OF-KEY
```

### OpenAI API Key
This is a special code that you can get from OpenAI that allows you to send requests to their computers running very large neural networks. Each time you make a request, they charge a very tiny amount of money. This is their business model. I will provide you with an OpenAI API key to use during the course...but please don't share it with the internet. (It has a spending cap, but it will be quickly used up if the "world" gets access.)

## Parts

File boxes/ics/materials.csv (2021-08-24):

UpDuino | ICE40UP5K dev board | 1 | _data/datasheets/arduino_nano_rev3.pdf | https://uk.farnell.com/arduino/a000005/arduino-nano-evaluation-board/dp/1848691
Cable (MiniUSB-1m) | Mini-USB to Type-A cable (1 m) | 1 | _data/datasheets/mini_USB_cable_1m.pdf | https://uk.farnell.com/molex/88732-8602/usb-cable-2-0-plug-plug-1m/dp/1221071
Piezo Buzzer | Piezoelectric speaker/buzzer | 1 | _data/datasheets/piezo_speaker.pdf | https://uk.farnell.com/kingstate/kpeg110/piezo-transducer/dp/1193641

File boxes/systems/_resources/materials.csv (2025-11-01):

name | slug | description | quantity | datasheet | supplier | package | x | y | z | unit_price | bulk_price | new | used
Computer (RPi4) | Computer_RPi4 | Raspberry Pi 4b with 2 GB RAM | 1 | /boxes/systems/_resources/datasheets/rpi4b.pdf | https://uk.farnell.com/raspberry-pi/rpi4-modbp-2gb/raspberry-pi-4-model-b-2gb/dp/3051886 | Medium (011) | 95 | 70 | 26 | 42.852 | 42.852 | 0 | 8
Power Jumper (Red) | Power_Jumpers_Red | Thick gauge (22 AWG) jumper wire (red insulation) 1Px2 to 2S | 1 | /boxes/systems/ | VK | Cables (001) | 50 | 1 | 1 | 1.0 | 1.0 | 0 | 0
Power Jumper (Black) | Power_Jumpers_Black | Thick gauge (22 AWG) jumper wire (black insulation) 1P to 1S | 2 | /boxes/systems/ | VK | Cables (001) | 50 | 1 | 1 | 1.0 | 1.0 | 0 | 0
Heatsinks | Heatsinks | Heatsinks for RPi 4b chips | 1 | /boxes/systems/_resources/datasheets/rpi4b_heatsinks.jpg | https://www.amazon.co.uk/gp/product/B07VRNT3HX | Large (100) | 40 | 20 | 10 | 3.5 | 2.0 | 15 | 0
SD Card | SD_Card | 16 GB micro SD card | 1 | /boxes/systems/_resources/datasheets/SanDisk-SDSQUAR-016G-GN6MA-datasheet.pdf | https://uk.farnell.com/integral/inmsdh16g-100v10/16gb-microsdhc-v10-uhs-i-u1/dp/3498606 | Large (100) | 100 | 50 | 3 | 5.652 | 5.652 | 1 | 0
M2.5 bolt (6) | M2_5_bolt_6 | 6 mm long M2.5 bolt | 8 | /boxes/robotics/ | https://www.accu.co.uk/pozi-pan-head-screws/9255-SPP-M2-5-6-A2 | Mounting Hardware | 5 | 5 | 6 | 0.15 | 0.04 | 2000 | 0
M2.5 standoff (20/SS) | M2_5_standoff_20_SS | 20 mm long socket-to-socket M2.5 standoff | 4 | /boxes/systems/ | https://uk.farnell.com/wurth-elektronik/970200154/standoff-hex-female-female-20mm/dp/2987903 | Mounting Hardware | 5 | 5 | 20 | 0.7368 | 0.54 | 204 | 0

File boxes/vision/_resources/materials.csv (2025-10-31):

name | slug | description | quantity | datasheet | supplier | package | x | y | z | unit_price | bulk_price | new | used
Camera (RPi v3) | Camera_RPi_v3 | RPi color camera with auto-focus (version 3) | 1 | /boxes/vision/_resources/datasheets/rpi_camera_v3.pdf | https://uk.farnell.com/raspberry-pi/sc0872/rpi-camera-mod-3-standard-lens/dp/4132318 | Medium (011) | 120 | 75 | 23 | 23.808 | 23.808 | 1 | 0
NB3 Camera Mount | NB3_Camera_Mount | Custom laser cut mount for RPi camera | 1 | /boxes/vision/NB3_camera_mount | VK | Acrylic Mounts | 40 | 30 | 5 | 3.0 | 1.0 | 0 | 0
NB3 Cortex Mount | NB3_Cortex_Mount | Custom laser cut holder for NPU | 1 | /boxes/vision/NB3_cortex_mount | VK | Acrylic Mounts | 75 | 65 | 5 | 4.0 | 2.0 | 0 | 0
M2.5 bolt (6) | M2_5_bolt_6 | 6 mm long M2.5 bolt | 4 | /boxes/robotics/ | https://www.accu.co.uk/pozi-pan-head-screws/9255-SPP-M2-5-6-A2 | Mounting Hardware | 5 | 5 | 6 | 0.15 | 0.04 | 2000 | 0
M2.5 standoff (20/PS) | M2_5_standoff_20_PS | 20 mm long plug-to-socket M2.5 standoff | 4 | /boxes/vision/ | https://uk.farnell.com/wurth-elektronik/971200151/standoff-hex-male-female-20mm/dp/2884418 | Mounting Hardware | 5 | 5 | 20 | 0.6624 | 0.534 | 217 | 0
M3 nut (square) | M3_nut_square | square M3 nut 1.8 mm thick | 1 | /boxes/audio/- | https://www.accu.co.uk/flat-square-nuts/21326-HFSN-M3-A2 | Mounting Hardware | 5 | 5 | 3 | 0.16 | 0.05 | 480 | 0
M3 bolt (12) | M3_bolt_12 | 12 mm long M3 bolt | 1 | /boxes/vision/ | https://www.accu.co.uk/pozi-pan-head-screws/500116-SPP-M3-12-ST-BZP | Mounting Hardware | 5 | 5 | 12 | 0.14 | 0.03 | 865 | 0
M2 bolt (8) | M2_bolt_8 | 8 mm long M2 bolt | 4 | /boxes/audio/ | https://www.accu.co.uk/pozi-pan-head-screws/500101-SPP-M2-8-ST-BZP | Mounting Hardware | 5 | 5 | 8 | 0.14 | 0.03 | 280 | 0
M2 nut | M2_nut | regular M2 nut | 4 | /boxes/audio/ | https://www.accu.co.uk/hexagon-nuts/456429-HPN-M2-C8-Z | Mounting Hardware | 5 | 5 | 3 | 0.14 | 0.03 | 720 | 0

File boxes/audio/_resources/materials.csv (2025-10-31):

name | slug | description | quantity | datasheet | supplier | package | x | y | z | unit_price | bulk_price | new | used
NB3 Ear | NB3_Ear | I2S mems microphone breakout board | 2 | /boxes/audio/NB3_ear | VK | Circuit Boards | 20 | 20 | 20 | 7.0 | 5.0 | 184 | 0
NB3 Mouth | NB3_Mouth | I2S DAC-AMP breakout board | 1 | /boxes/audio/NB3_mouth | VK | Circuit Boards | 20 | 20 | 20 | 7.0 | 5.0 | 16 | 3
Speaker (Hi-Fi) | Speaker_Hi_Fi | 3 Watt 4 Ohm with Dupont 2.54 mm socket (High Fidelity: 2831/3128) | 1 | /boxes/audio/_resources/datasheets/3128_3W_4Ohm.jpg | https://www.amazon.co.uk/gp/product/B0D9QXW5FF | Large (100) | 44 | 30 | 15 | 4.79 | 2.0 | 16 | 0
Speaker Mount | Speaker_Mount | Custom laser cut mount for speaker | 1 | /boxes/audio/- | VK | Acrylic Mounts | 75 | 20 | 5 | 3.0 | 1.0 | 0 | 0
Speaker Frame | Speaker_Frame | Custom laser cut frame for speaker | 1 | /boxes/audio/- | VK | Acrylic Mounts | 75 | 50 | 5 | 3.0 | 1.0 | 0 | 0
M3 standoff (15/PS) | M3_standoff_15_PS | 15 mm long plug-to-socket M3 standoff | 2 | /boxes/audio/- | https://uk.farnell.com/ettinger/05-13-151/spacer-m3x15-vzk/dp/1466726 | Mounting Hardware | 5 | 5 | 15 | 0.3924 | 0.3444 | 182 | 0
M3 nut (square) | M3_nut_square | square M3 nut 1.8 mm thick | 2 | /boxes/audio/- | https://www.accu.co.uk/flat-square-nuts/21326-HFSN-M3-A2 | Mounting Hardware | 5 | 5 | 3 | 0.16 | 0.05 | 480 | 0
M3 bolt (6) | M3_bolt_6 | 6 mm long M3 bolt | 2 | /boxes/audio/- | https://www.accu.co.uk/pozi-pan-head-screws/500113-SPP-M3-6-ST-BZP | Mounting Hardware | 5 | 5 | 6 | 0.14 | 0.03 | 663 | 0
M2.5 bolt (6) | M2_5_bolt_6 | 6 mm long M2.5 bolt | 2 | /boxes/robotics/ | https://www.accu.co.uk/pozi-pan-head-screws/9255-SPP-M2-5-6-A2 | Mounting Hardware | 5 | 5 | 6 | 0.15 | 0.04 | 2000 | 0
M2.5 nut | M2_5_nut | regular M2.5 nut | 2 | /boxes/power/- | https://www.accu.co.uk/hexagon-nuts/456430-HPN-M2-5-C8-Z | Mounting Hardware | 5 | 5 | 3 | 0.14 | 0.03 | 350 | 0
M2 bolt (8) | M2_bolt_8 | 8 mm long M2 bolt | 2 | /boxes/audio/ | https://www.accu.co.uk/pozi-pan-head-screws/500101-SPP-M2-8-ST-BZP | Mounting Hardware | 5 | 5 | 8 | 0.14 | 0.03 | 280 | 0
M2 nut | M2_nut | regular M2 nut | 2 | /boxes/audio/ | https://www.accu.co.uk/hexagon-nuts/456429-HPN-M2-C8-Z | Mounting Hardware | 5 | 5 | 3 | 0.14 | 0.03 | 720 | 0

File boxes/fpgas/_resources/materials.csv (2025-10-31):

name | slug | description | quantity | datasheet | supplier | package | x | y | z | unit_price | bulk_price | new | used
NB3 Hindbrain | NB3_Hindbrain | ICE40UP5K dev board with ADC/DAC | 1 | /boxes/fpgas/NB3_hindbrain | VK | Circuit Boards | 60 | 30 | 20 | 50.0 | 35.0 | 2 | 0
Cable (MicroUSB-1m) | Cable_MicroUSB_1m | Micro-USB to Type-A cable (1 m) | 1 | /boxes/fpgas/ | https://www.amazon.co.uk/gp/product/B07GBCKX49 | Cables (001) | 100 | 50 | 15 | 3.15 | 1.83 | 0 | 0
Cable (MicroUSB-20cm) | Cable_MicroUSB_20cm | Short micro-USB to Type-A cable (20 cm) | 1 | /boxes/networks/ | https://www.amazon.co.uk/gp/product/B07GBS2QZ1 | Cables (001) | 100 | 50 | 10 | 3.1 | 1.62 | 0 | 0

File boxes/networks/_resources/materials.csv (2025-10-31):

name | slug | description | quantity | datasheet | supplier | package | x | y | z | unit_price | bulk_price | new | used
Cable (MiniUSB-20cm) | Cable_MiniUSB_20cm | Short mini-USB to Type-A cable (20 cm) | 1 | /boxes/networks/ | https://www.amazon.co.uk/gp/product/B07FW69HNT | Cables (001) | 100 | 25 | 10 | 3.02 | 1.58 | 0 | 0

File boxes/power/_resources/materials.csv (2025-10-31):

name | slug | description | quantity | datasheet | supplier | package | x | y | z | unit_price | bulk_price | new | used
NB3 Power Board | NB3_Power_Board | Regulated DC-DC power supply (5 Volts - 4 Amps) | 1 | /boxes/power/NB3_power | VK | Circuit Boards | 50 | 50 | 15 | 30.0 | 20.0 | 52 | 1
Power Cable | Power_Cable | Custom 4 pin NB3 power connector cable | 1 | /boxes/power/ | VK | Circuit Boards | 50 | 10 | 5 | 5.0 | 3.0 | 0 | 0
M2.5 standoff (7/PS) | M2_5_standoff_7_PS | 7 mm long plug-to-socket M2.5 standoff | 4 | /boxes/power/ | https://uk.farnell.com/wurth-elektronik/971070151/standoff-hex-male-female-7mm-m2/dp/2884371 | Mounting Hardware | 5 | 5 | 7 | 0.4836 | 0.3792 | 458 | 0
M2.5 bolt (6) | M2_5_bolt_6 | 6 mm long M2.5 bolt | 4 | /boxes/robotics/ | https://www.accu.co.uk/pozi-pan-head-screws/9255-SPP-M2-5-6-A2 | Mounting Hardware | 5 | 5 | 6 | 0.15 | 0.04 | 2000 | 0
M2.5 nut | M2_5_nut | regular M2.5 nut | 4 | /boxes/power/- | https://www.accu.co.uk/hexagon-nuts/456430-HPN-M2-5-C8-Z | Mounting Hardware | 5 | 5 | 3 | 0.14 | 0.03 | 350 | 0
12V DC Power Supply | 12V_DC_Power_Supply | 12 V AC-DC transformer (UK/EU/USA plugs) | 1 | /boxes/power/ | https://www.amazon.co.uk/gp/product/B09QG4R1R4 | Large (100) | 100 | 100 | 80 | 12.99 | 12.99 | 0 | 0

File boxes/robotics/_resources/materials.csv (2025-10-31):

name | slug | description | quantity | datasheet | supplier | package | x | y | z | unit_price | bulk_price | new | used
Servo Motor | Servo_Motor | FT90R Digital Micro Continuous Rotation Servo | 2 | /boxes/control/ | https://www.pololu.com/product/2817 | Large (100) | 100 | 70 | 15 | 8.95 | 5.0 | 0 | 0
Servo Wheel | Servo_Wheel | Wheels (70x8mm) for servos | 2 | /boxes/control/ | https://www.pololu.com/product/4925 | Large (100) | 100 | 70 | 15 | 3.5 | 2.5 | 0 | 0
Servo Mount | Servo_Mount | Mount for servo motor | 2 | /boxes/robotics/ | VK | Acrylic Mounts | 30 | 15 | 5 | 2.0 | 0.75 | 0 | 0
M2.5 bolt (6) | M2_5_bolt_6 | 6 mm long M2.5 bolt | 8 | /boxes/robotics/ | https://www.accu.co.uk/pozi-pan-head-screws/9255-SPP-M2-5-6-A2 | Mounting Hardware | 5 | 5 | 6 | 0.15 | 0.04 | 2000 | 0
M2.5 standoff (12/SS) | M2_5_standoff_12_SS | 12 mm long socket-to-socket M2.5 standoff | 4 | /boxes/robotics/ | https://uk.farnell.com/wurth-elektronik/970120151/standoff-hex-female-female-12mm/dp/2884528 | Mounting Hardware | 5 | 5 | 12 | 0.606 | 0.3816 | 340 | 0
Caster | Caster | 0.75 inch metal ball caster | 1 | /boxes/robotics/https://www.pololu.com/product/955 | https://www.pololu.com/product/955 | Large (100) | 70 | 50 | 20 | 3.95 | 3.08 | 118 | 0
Spacer | Spacer | NB3 spacer 3 mm spacer for mounting ball caster | 5 | /boxes/robotics/NB3_spacer | VK | Acrylic Mounts | 25 | 25 | 5 | 0.5 | 0.25 | 0 | 0

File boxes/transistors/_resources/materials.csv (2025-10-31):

name | slug | description | quantity | datasheet | supplier | package | x | y | z | unit_price | bulk_price | new | used
MOSFET (5V) | MOSFET__5V_ | Power MOSFET/N-channel (IRL510) | 1 | /boxes/transistors/_resources/datasheets/IRL510.pdf | https://uk.farnell.com/vishay/irl510pbf/mosfet-n-logic-to-220/dp/9102779 | Active Electronics | 40 | 15 | 4 | 1.296 | 0.7476 | 165 | 0
Diode | Diode | IN4001 | 2 | /boxes/transistors/_resources/datasheets/IN4001.pdf | https://uk.farnell.com/on-semiconductor/1n4001g/diode-standard-1a-do-41/dp/1458986 | Active Electronics | 40 | 5 | 3 | 0.1656 | 0.0588 | 238 | 0
LED (Red) | LED_Red | 3 mm/2 mA red LED | 2 | /boxes/transistors/_resources/datasheets/led_HLMP.pdf | https://uk.farnell.com/broadcom-limited/hlmp-1700/led-3mm-red-2-1mcd-626nm/dp/1003207 | Active Electronics | 50 | 5 | 3 | 0.6036 | 0.1812 | 185 | 0
LED (Yellow) | LED_Yellow | 3 mm/2 mA yellow LED | 2 | /boxes/transistors/_resources/datasheets/led_HLMP.pdf | https://uk.farnell.com/broadcom-limited/hlmp-1719/led-3mm-yellow-2-1mcd-585nm/dp/1003208 | Active Electronics | 50 | 5 | 3 | 0.5148 | 0.1548 | 170 | 0
LED (Green) | LED_Green | 3 mm/2 mA green LED | 2 | /boxes/transistors/_resources/datasheets/led_HLMP.pdf | https://uk.farnell.com/broadcom-limited/hlmp-1790/led-3mm-green-2-3mcd-569nm/dp/1003209 | Active Electronics | 50 | 5 | 3 | 0.6948 | 0.2208 | 120 | 0
Resistor (470) | Resistor_470 | 470 &Omega;/0.25 W | 4 | /boxes/electrons/_resources/datasheets/resistor.pdf | https://uk.farnell.com/multicomp/mf25-470r/res-470r-1-250mw-axial-metal-film/dp/9341943 | Passive Electronics | 50 | 5 | 3 | 0.0685 | 0.0498 | 0 | 0

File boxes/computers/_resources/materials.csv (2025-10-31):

name | slug | description | quantity | datasheet | supplier | package | x | y | z | unit_price | bulk_price | new | used
Microcontroller | Microcontroller | Arduino Nano (rev.3) | 1 | /boxes/computers/_resources/datasheets/arduino_nano_rev3.pdf | https://uk.farnell.com/arduino/a000005/arduino-nano-evaluation-board/dp/1848691 | Medium (011) | 82 | 60 | 25 | 18.516 | 18.516 | 0 | 6
Piezo Buzzer | Piezo_Buzzer | Piezoelectric speaker/transducer | 1 | /boxes/computers/_resources/datasheets/piezo_buzzer.pdf | https://uk.farnell.com/tdk/ps1240p02bt/piezoelectric-buzzer-4khz-70dba/dp/3267212 | Passive Electronics | 30 | 30 | 1 | 0.4296 | 0.3576 | 63 | 0
Cable (MiniUSB-1m) | Cable_MiniUSB_1m | Mini-USB to Type-A cable (1 m) | 1 | /boxes/computers/ | https://www.amazon.co.uk/gp/product/B07FWF2KBF | Cables (001) | 100 | 50 | 15 | 3.24 | 1.94 | 0 | 0

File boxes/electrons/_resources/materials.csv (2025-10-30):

name | slug | description | quantity | datasheet | supplier | package | x | y | z | unit_price | bulk_price | new | used
NB3 Body | NB3_Body | NB3 robot base PCB | 1 | /boxes/electrons/NB3_body | VK | Body (000) | 200 | 200 | 11 | 30.0 | 20.0 | 60 | 5
Resistor (470) | Resistor_470 | 470 &Omega;/0.25 W | 2 | /boxes/electrons/_resources/datasheets/resistor.pdf | https://uk.farnell.com/multicomp/mf25-470r/res-470r-1-250mw-axial-metal-film/dp/9341943 | Passive Electronics | 50 | 2 | 2 | 0.0685 | 0.0498 | 0 | 0
Resistor (1k) | Resistor_1k | 1 k&Omega;/0.25 W | 2 | /boxes/electrons/_resources/datasheets/resistor.pdf | https://uk.farnell.com/multicomp/mf25-1k/res-1k-1-250mw-axial-metal-film/dp/9341102 | Passive Electronics | 50 | 2 | 2 | 0.0702 | 0.051 | 0 | 0
Resistor (10k) | Resistor_10k | 10 k&Omega;/0.25 W | 2 | /boxes/electrons/_resources/datasheets/resistor.pdf | https://uk.farnell.com/multicomp/mf25-10k/res-10k-1-250mw-axial-metal-film/dp/9341110 | Passive Electronics | 50 | 2 | 2 | 0.0696 | 0.0504 | 0 | 0
Button | Button | Tactile switch | 2 | /boxes/electrons/_resources/datasheets/button.pdf | https://uk.farnell.com/omron/b3f-1000/switch-spno-0-05a-24v-tht-0-98n/dp/176432 | Passive Electronics | 5 | 5 | 3 | 0.2148 | 0.1788 | 0 | 0
Potentiometer | Potentiometer | 2.2 k&Omega; variable resistor | 2 | /boxes/electrons/_resources/datasheets/pot_2k2.pdf | https://uk.farnell.com/bourns/3362p-1-222lf/trimmer-pot-2-2kohm-10-1turn-th/dp/2328599 | Passive Electronics | 5 | 5 | 3 | 0.9708 | 0.72 | 630 | 0
Breadboard (400) | Breadboard_400 | 400-tie solderless breadboard | 1 | /boxes/electrons/_resources/datasheets/breadboard_400.pdf | https://www.amazon.co.uk/gp/product/B0739XRX8F | Small (010) | 85 | 60 | 10 | 4.0 | 2.3 | 16 | 0
Breadboards (170) | Breadboards_170 | 170-tie solderless breadboard | 4 | /boxes/electrons/_resources/datasheets/breadboard_170.pdf | https://www.amazon.co.uk/ELEGOO-tie-points-Breadboard-Breadboards-Electronic/dp/B01N0YWIR7 | Small (010) | 35 | 50 | 10 | 2.0 | 1.0 | 16 | 0
Batteries (AA) | Batteries_AA | AA 1.5 V alkaline battery | 4 | /boxes/electrons/ | https://www.amazon.co.uk/Duracell-Optimum-Alkaline-Batteries-MX1500/dp/B093Q5XY66 | Auxiliary | 60 | 15 | 15 | 5.75 | 3.0 | 0 | 0
Battery holder | Battery_holder | 4xAA battery holder with ON-OFF switch | 1 | /boxes/electrons/ | https://www.amazon.co.uk/gp/product/B0814ZH68F | Small (010) | 65 | 70 | 20 | 3.0 | 2.0 | 8 | 3
Jumper Kit | Jumper_Kit | Kit of multi-length 22 AWG breadboard jumpers | 1 | /boxes/electrons/_resources/datasheets/jumper_kit.pdf | https://uk.farnell.com/multicomp/mc001810/hard-jumper-wire-22awg-140pc/dp/2770338 | Large (100) | 170 | 55 | 15 | 5.976 | 4.296 | 10 | 18
Jumper Wires | Jumper_Wires | Assorted 22 AWG jumper wire leads (male/female) | 1 | /boxes/electrons/_resources/datasheets/jumper_wires.pdf | https://www.amazon.co.uk/gp/product/B09KR7Z4PF | Cables (001) | 200 | 40 | 10 | 4.0 | 3.75 | 50 | 20
Test Lead | Test_Lead | Alligator clip to 0.64 mm pin (20 cm) | 2 | /boxes/electrons/ | https://www.amazon.co.uk/gp/product/B096JR15JW | Cables (001) | 220 | 20 | 10 | 1.5 | 0.85 | 132 | 1
Rubber feet | Rubber_Feet | Adhesive rubber standoffs (1421T6CL) | 4 | /boxes/electrons/_resources/datasheets/rubber_feet.pdf | https://uk.farnell.com/hammond/1421t6cl/feet-stick-on-pk24/dp/1876522 | Passive Electronics | 20 | 20 | 4 | 0.2965 | 0.229 | 0 | 0

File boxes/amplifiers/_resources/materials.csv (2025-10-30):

name | slug | description | quantity | datasheet | supplier | package | x | y | z | unit_price | bulk_price | new | used
LM741 | LM741 | OpAmp | 1 | /boxes/amplifiers/_resources/datasheets/LM741.pdf | https://uk.farnell.com/texas-instruments/lm741cn-nopb/op-amp-single-pdip-8-0-to-70deg/dp/3117118 | Active Electronics | 5 | 5 | 3 | 0.9732 | 0.5592 | 77 | 0
LM386 | LM386 | Audio-Amp | 2 | /boxes/amplifiers/_resources/datasheets/LM386.pdf | https://uk.farnell.com/texas-instruments/lm386n-4-nopb/audio-power-amplifier-class-ab/dp/3116866 | Active Electronics | 5 | 5 | 3 | 1.1784 | 1.1484 | 46 | 0

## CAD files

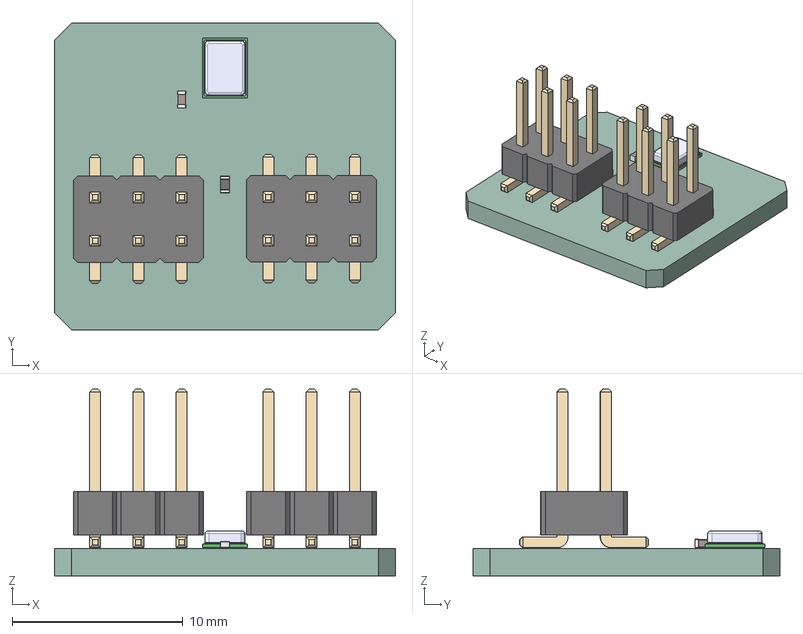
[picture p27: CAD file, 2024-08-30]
boxes/audio/NB3_ear/NB3_ear.step
20.0 x 18.0 x 11.0 mm
ICS-43434
C_0402_1005Metric
R_0402_1005Metric
PinHeader_2x03_P254mm_Vertical_SMD x 2
NB3_ear_PCB

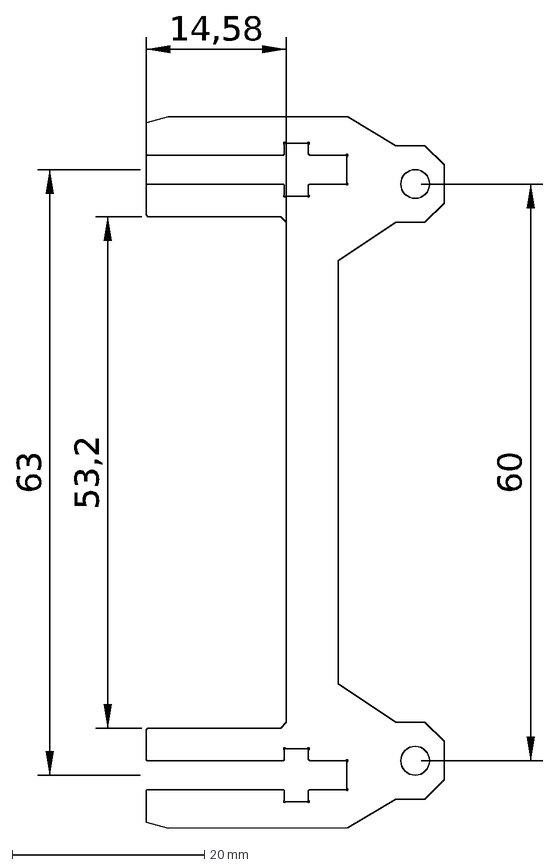
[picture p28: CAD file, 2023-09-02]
boxes/audio/NB3_mounts/NB3_mouth_mount.dxf
63
53,2
14,58
60

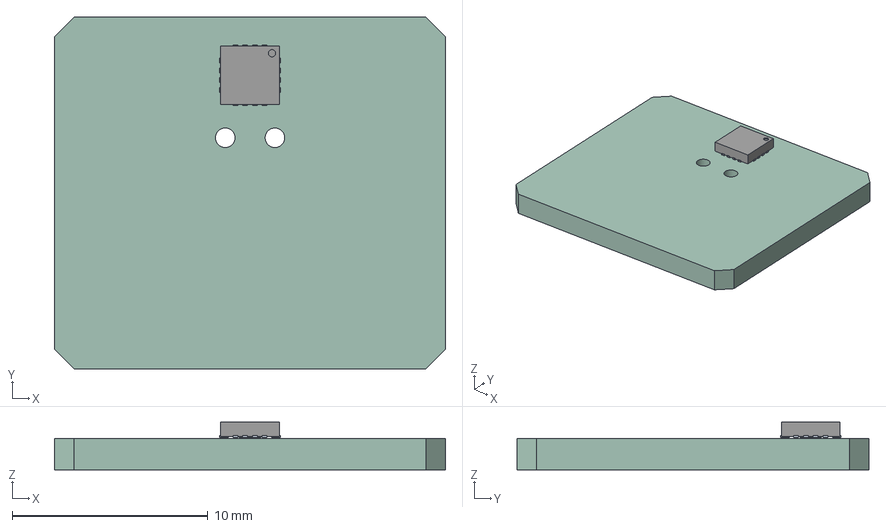
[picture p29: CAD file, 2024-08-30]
boxes/audio/NB3_mouth/NB3_mouth.step
20.0 x 18.0 x 2.45 mm
ASSEMBLY
_autosave-NB3_mouth PCB

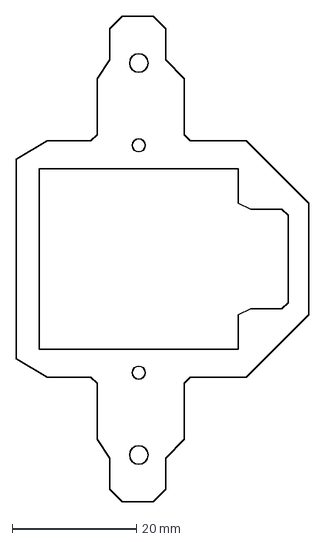
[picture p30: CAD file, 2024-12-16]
boxes/audio/NB3_speaker_frame/NB3_speaker_frame.dxf
47.0 x 78.0 mm

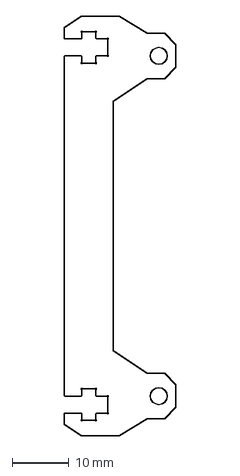
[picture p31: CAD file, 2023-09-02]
boxes/audio/NB3_speaker_mount/NB3_speaker_mount.dxf
19.7 x 74.0 mm

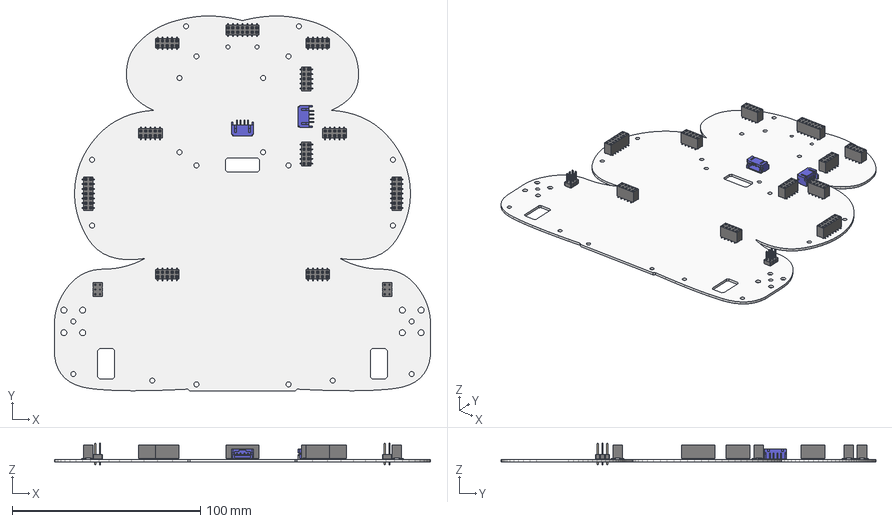
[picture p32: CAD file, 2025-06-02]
boxes/electrons/NB3_body/NB3_body.step
200.0 x 199.5 x 11.5 mm
PinSocket_2x05_P2.54mm_Vertical_SMD x 8
PinHeader_2x03_P2.54mm_Vertical x 2
PinSocket_2x07_P2.54mm_Vertical_SMD x 3
Connector_S4B-PH-SM4-TB(LF)(SN) x 2
NB3_body_PCB

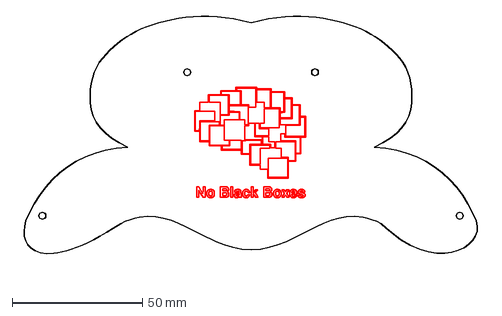
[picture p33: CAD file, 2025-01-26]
boxes/intelligence/NB3_skull/NB3_skull_forebrain_logo.dxf
179.9 x 99.5 mm

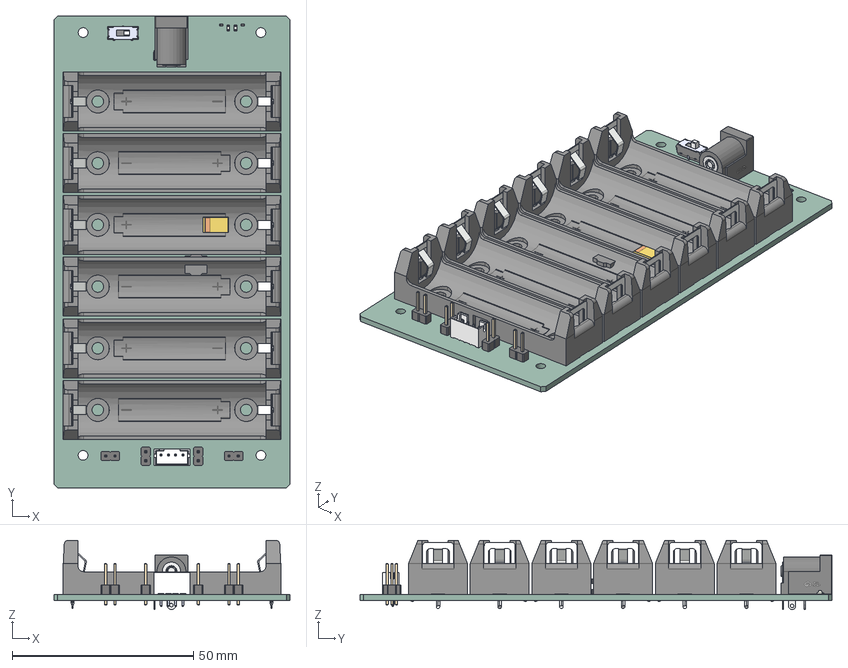
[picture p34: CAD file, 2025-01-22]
boxes/power/NB3_charger/NB3_charger.step
65.0 x 130.1 x 19.1 mm
PinHeader_1x02_P254mm_Vertical x 4
C_0805_2012Metric x 10
R_0402_1005Metric x 6
LED_0603_1608Metric x 2
CP_EIA_7343_31_Kemet_D
DC-IN-TH_DC-005-A200
JS102011JCQN
C_0402_1005Metric x 5
L_Bourns_SRN6045TA
SOIC_8_1EP_39x49mm_P127mm
B4B-PH-K-S(LF)(SN)
NB3_charger_PCB

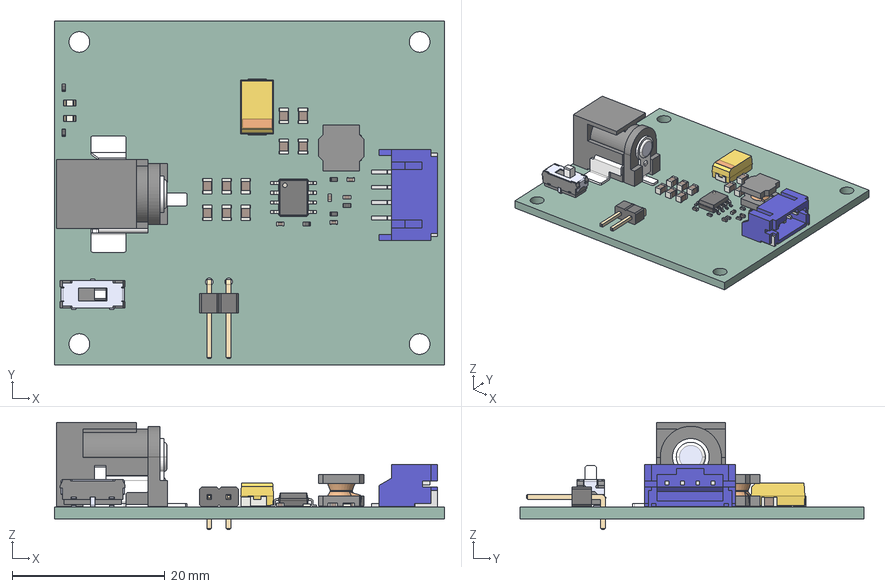
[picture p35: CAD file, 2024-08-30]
boxes/power/NB3_power/NB3_power.step
51.0 x 45.0 x 14.0 mm
C_0805_2012Metric x 10
R_0402_1005Metric x 6
LED_0603_1608Metric x 2
CP_EIA_7343_31_Kemet_D
CUI_DEVICES_PJ-036AH-SMT-TR
JS102011JCQN
C_0402_1005Metric x 5
PinHeader_1x02_P254mm_Horizontal
L_Bourns_SRN6045TA
S4B-PH-SM4
SOIC_8_1EP_39x49mm_P127mm
NB3_power_PCB

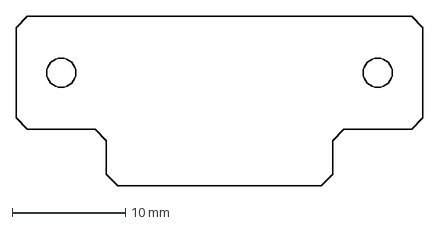
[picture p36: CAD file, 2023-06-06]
boxes/robotics/NB3_servo_mount/NB3_servo_mount.dxf
36.0 x 15.0 mm

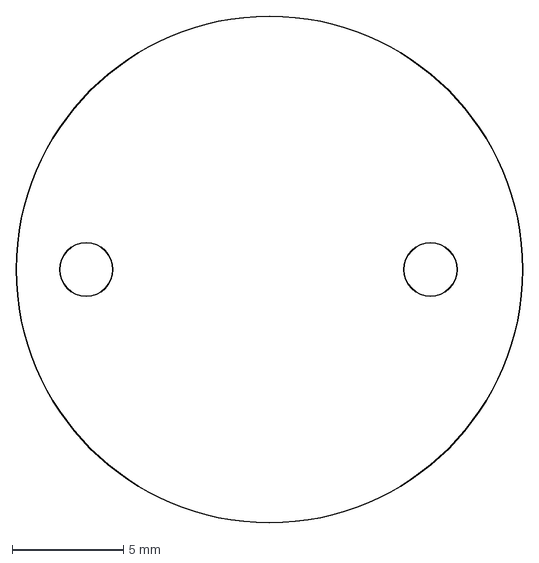
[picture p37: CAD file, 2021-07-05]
boxes/robotics/NB3_spacer/NB3_spacer.dxf
22.8 x 22.8 mm

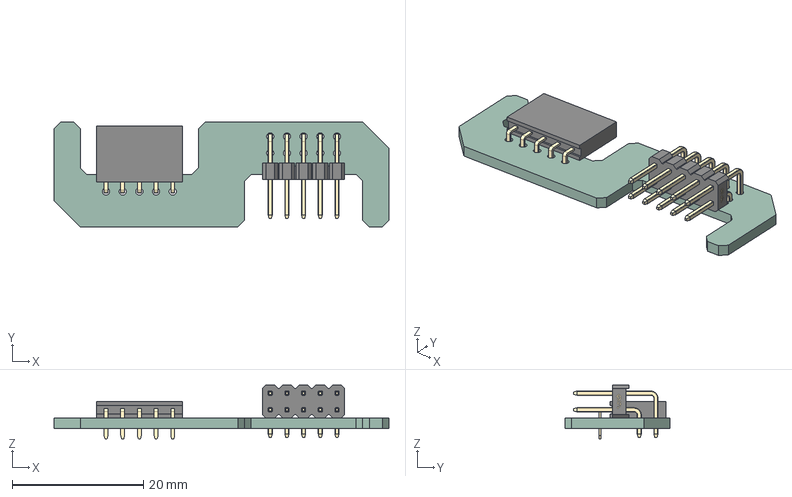
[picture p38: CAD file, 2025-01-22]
boxes/systems/NB3_eye/NB3_eye.step
51.0 x 16.0 x 8.20 mm
零件53
HDR-TH_5P-P2.54-H-F-W10.0-N
NB3_eye_PCB

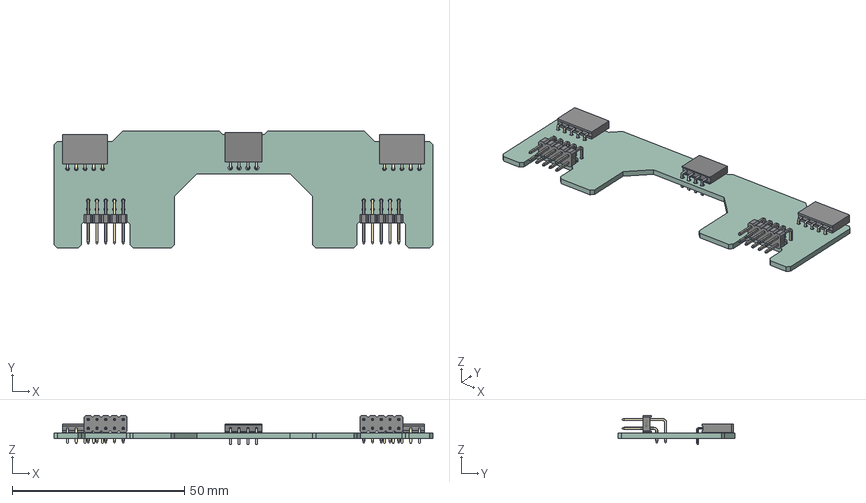
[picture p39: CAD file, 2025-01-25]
boxes/systems/NB3_eyes/NB3_eyes.step
110.0 x 34.0 x 8.50 mm
HDR-TH_5P-P2.54-H-F-W10.0-N x 2
零件53 x 2
HDR-TH_4P-P2.54-F-WI-1X4P
_autosave-NB3_eyes_PCB

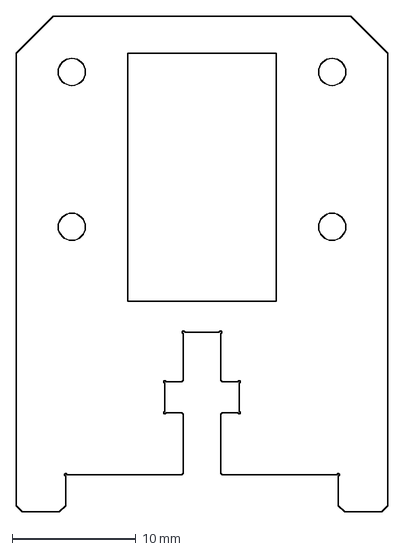
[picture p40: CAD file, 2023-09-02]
boxes/vision/NB3_camera_mount/NB3_camera_mount.dxf
30.0 x 40.0 mm

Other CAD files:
boxes/vision/NB3_cortex_mount/NB3_cortex_mount.dxf
boxes/vision/NB3_mounts/NB3_camera_mount.dxf
course/_resources/packaging/CAD/boxes/Medium.step
course/_resources/packaging/CAD/items/bootcamp/Cables/Cable__Mini_USB_20cm__networks_0.step
boxes/intelligence/NB3_skull/NB3_skull-hindbrain.dxf
boxes/intelligence/NB3_skull/NB3_skull-midbrain.dxf
boxes/intelligence/NB3_skull/NB3_skull-midbrain_offset.dxf
boxes/intelligence/NB3_skull/NB3_skull.dxf
boxes/intelligence/NB3_skull/NB3_skull_forebrain.dxf
boxes/intelligence/NB3_skull/NB3_skull_forebrain_offset.dxf
boxes/intelligence/NB3_skull/logo_NBB_black_text.dxf
course/_resources/packaging/CAD/boxes/Body.step
course/_resources/packaging/CAD/boxes/Cables.step
course/_resources/packaging/CAD/boxes/Large.step
course/_resources/packaging/CAD/boxes/Mailer.step
course/_resources/packaging/CAD/boxes/Small.step
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

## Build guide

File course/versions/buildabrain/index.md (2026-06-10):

# LBB: Build a Brain

<p align="center">
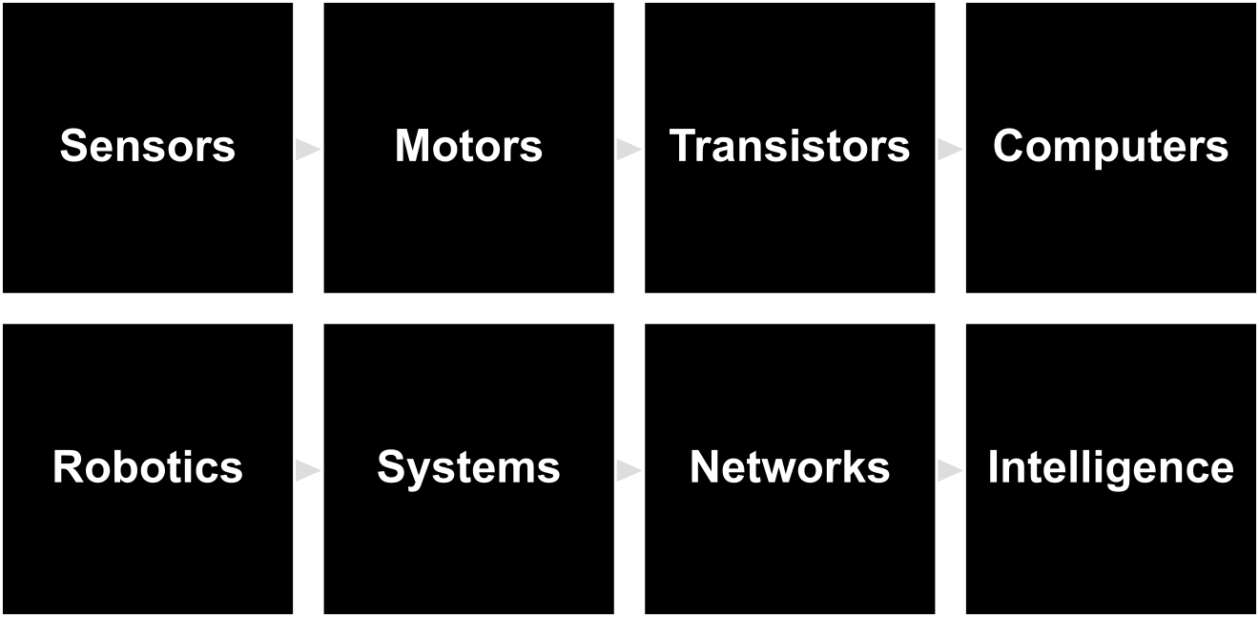
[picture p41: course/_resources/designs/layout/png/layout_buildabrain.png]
Build a Brain course layout: the boxes you will open during the course

</p>

**LBB-101** walks you through building a brain — and the body around it — from raw electronics up to a robot that sees, hears, and learns. Over eight sessions you will assemble **NB3** from atoms onward, with no black boxes.

## Sessions

### Session 1 - [Sensing the World](sessions/01_sensing-the-world/README.md)
- Atoms, electrons, sensors, light. **Project**: *Build a light sensor.*

### Session 2 - [Making Things Move](sessions/02_making-things-move/README.md)
- Magnets and motors. **Project**: *Build a speaker.*

### Session 3 - [Digital Decisions](sessions/03_digital-decisions/README.md)
- Transistors, amplifiers, circuits, and power. **Project**: *Build a light-sensitive motor.*

### Session 4 - [How Computers Work](sessions/04_how-computers-work/README.md)
- Data, logic, memory, computers, and FPGAs. **Project**: *Program a microcontroller.*

### Session 5 - [Build a Robot](sessions/05_build-a-robot/README.md)
- Control and robotics. **Project**: *Build a Braitenberg vehicle.*

### Session 6 - [The Software Stack](sessions/06_the-software-stack/README.md)
- Linux and Python. **Project**: *Connect wirelessly and play with Python.*

### Session 7 - [How the Internet Works](sessions/07_how-the-internet-works/README.md)
- Websites, servers, networks, and security. **Project**: *Build a remote-control robot.*

### Session 8 - [Artificial Intelligence](sessions/08_artificial-intelligence/README.md)
- Audio, vision, learning, and intelligence. **Projects**: *voice-activated, vision-enabled NB3.*

## The curriculum

Build a Brain traces these boxes from raw sensors up to intelligence, building cumulatively from one to the next. Hover any box to highlight it; click to open its folder on GitHub for the deeper material.

<p align="center">
<object data="/course/_resources/designs/layout/svg/layout_buildabrain_interactive.svg" type="image/svg+xml" width="500" aria-label="Build a Brain course layout (hover any box to highlight, click to open its folder on GitHub)">
  Build a Brain course layout
</object>
</p>

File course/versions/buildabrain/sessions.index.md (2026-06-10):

# Sessions

Eight sessions building cumulatively from raw sensors to an intelligent robot.

### Session 1 - [Sensing the World](01_sensing-the-world/README.md)
- **Project**: *Build a light sensor.*

### Session 2 - [Making Things Move](02_making-things-move/README.md)
- **Project**: *Build a speaker.*

### Session 3 - [Digital Decisions](03_digital-decisions/README.md)
- **Project**: *Build a light-sensitive motor.*

### Session 4 - [How Computers Work](04_how-computers-work/README.md)
- **Project**: *Program a microcontroller.*

### Session 5 - [Build a Robot](05_build-a-robot/README.md)
- **Project**: *Build a Braitenberg vehicle.*

### Session 6 - [The Software Stack](06_the-software-stack/README.md)
- **Project**: *Connect wirelessly and play with Python.*

### Session 7 - [How the Internet Works](07_how-the-internet-works/README.md)
- **Project**: *Build a remote-control robot.*

### Session 8 - [Artificial Intelligence](08_artificial-intelligence/README.md)
- **Projects**: *voice-activated, vision-enabled NB3.*

Start at Session 1 and work in order.

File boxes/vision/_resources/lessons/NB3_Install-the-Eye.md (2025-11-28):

# Vision : NB3 : Install the Eye
Let's install a camera on your NB3.

## [Video](https://vimeo.com/1042945461)

## Concepts

## Lesson
- Test your camera with the following command
```bash
# Capture a still image and save it to a file
rpicam-still -o my_test.png

# The image will appear in the same folder where the command was run
```

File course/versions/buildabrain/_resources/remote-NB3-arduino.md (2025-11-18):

# Remote-NB3 : Arduino Code

## Upload the "Serial Controller" to your Arduino
This code will run on your Arduino. It listens for single letter commands sent via the serial (USB) cable and responds by moving the wheels.
- Command 'f': Forwards
- Command 'b': Backwards
- Command 'l': Turn Left
- Command 'r': Turn Right
- Command 'x': Stop

**Note**: Your servo motors must be connected to pin 9 (right servo) and pin 10 (left servo) of your Arduino Nano.

```c
/*
  Serial Controller
    - Respond to single character commands received via serial with servo motion
*/

#include <Servo.h>    // This includes the "servo" library
Servo left, right;    // This creates two servo objects, one for each motor

void setup() {
  // Initialize serial port
  Serial.begin(115200);

  // Attach servo pins
  right.attach(9);    // Assign right servo to digital (PWM) pin 9 (change according to your connection)
  left.attach(10);    // Assign left servo to digital (PWM) pin 10 (change according to your connection)

  // Initialize (no motion)
  left.write(90);
  right.write(90);
}

void loop() {
  
  // Check for any incoming bytes
  if (Serial.available() > 0) {
    char new_char = Serial.read();

    // Respond to command "f"
    if(new_char == 'f') {
      forward();
    }

    // Respond to command "b"
    if(new_char == 'b') {
      backward();
    }

    // Respond to command "l"
    if(new_char == 'l') {
      turn_left();
    }

    // Respond to command "r"
    if(new_char == 'r') {
      turn_right();
    }

    // Respond to command "x"
    if(new_char == 'x') {
      stop();
    }
  }

  // Wait a bit
  delay(10);
}

// Forward
void forward()
{
  left.write(180);
  right.write(0);
}

// Backward
void backward()
{
  left.write(0);
  right.write(180);
}

// Left
void turn_left()
{
  left.write(0);
  right.write(0);
}

// Right
void turn_right()
{
  left.write(180);
  right.write(180);
}

// Stop
void stop()
{
  left.write(90);
  right.write(90);
}
```

## Remote Control your NB3
If you connect to your NB3's Raspberry Pi via SSH, then you can run commands on your Raspberry Pi remotely. The Python code [here](/boxes/networks/remote-NB3/python/drive/drive.py) listens for a keypress (either the up, down, left, or right arrow) and then sends the appropriate command to your Arduino to drive forward, backward, or turn. You can exit this Python code by pressing 'q' to quit.

To run this code, you can navigate to the folder containing the file and run it with Python.
```bash
cd $HOME/NoBlackBoxes/LastBlackBox/boxes/networks/remote-NB3/python/drive
python drive.py
```

...or you can use a "shortcut" command we have added to your Linux terminal (which just does the same as the above...more succinctly)
```bash
Drive
```

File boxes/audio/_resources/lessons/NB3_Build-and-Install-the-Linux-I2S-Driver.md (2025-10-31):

# Audio : NB3 : Build and Install the Linux I2S Driver
Let's build (compile) and install the Linux device driver for our NB3's sound card. This software module is required to access the NB3's ears (microphone) and mouth (speaker).

## [Video](https://vimeo.com/1042781850)

## Concepts

## Lesson

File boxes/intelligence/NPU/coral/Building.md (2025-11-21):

# Building Tensorflow Lite Runtime on the Raspberry Pi

## Python Versions
The tflite-runtime on PyPI currently requires **Python 3.11**. This can make it difficult to run the Coral examples on an up-to-date NB3 system. It is possible to install an earlier version of Python.

## Building (on NB3)
- Install required libraries
```bash
sudo apt install libabsl-dev libusb-1.0-0-dev xxd cmake
```
- Install earlier version of flatbuffers
```bash
git clone https://github.com/google/flatbuffers.git
cd flatbuffers/
git checkout v23.5.26
mkdir build && cd build
cmake .. \
    -DFLATBUFFERS_BUILD_SHAREDLIB=ON \
    -DFLATBUFFERS_BUILD_TESTS=OFF \
    -DCMAKE_BUILD_TYPE=Release \
    -DCMAKE_INSTALL_PREFIX=/usr/local
make -j2
sudo make install
cd ../..
```
- Clone tensorflow and checkout desired version: 
```bash
git clone https://github.com/tensorflow/tensorflow
cd tensorflow
git checkout v2.14.0 # (same version of tflite runtime)
cd ..
```
- Clone libedgetpu repo
```bash
git clone https://github.com/feranick/libedgetpu
```
- Update LDFLAGS in Makefile
```make
LIBEDGETPU_LDFLAGS := \
	-Wl,-Map=$(BUILDDIR)/output.map \
	-shared \
	-Wl,--soname,libedgetpu.so.1 \
	-Wl,--version-script=$(BUILDROOT)/tflite/public/libedgetpu.lds \
	-fuse-ld=gold \
	-lflatbuffers \
	-labsl_flags_internal \
	-labsl_flags_marshalling \
	-labsl_str_format_internal \
	-labsl_flags_reflection \
	-labsl_flags_private_handle_accessor \
	-labsl_flags_commandlineflag \
	-labsl_flags_commandlineflag_internal \
	-labsl_flags_config \
	-labsl_flags_program_name \
	-labsl_cord \
	-labsl_cordz_info \
	-labsl_cord_internal \
	-labsl_cordz_functions \
	-labsl_cordz_handle \
	-labsl_hash \
	-labsl_city \
	-labsl_bad_variant_access \
	-labsl_low_level_hash \
	-labsl_raw_hash_set \
	-labsl_bad_optional_access \
	-labsl_hashtablez_sampler \
	-labsl_exponential_biased \
	-labsl_synchronization \
	-labsl_graphcycles_internal \
	-labsl_stacktrace \
	-labsl_symbolize \
	-labsl_debugging_internal \
	-labsl_demangle_internal \
	-labsl_malloc_internal \
	-labsl_time \
	-labsl_civil_time \
	-labsl_time_zone \
	-labsl_strings \
	-labsl_strings_internal \
	-latomic \
	-lrt \
	-labsl_base \
	-labsl_spinlock_wait \
	-labsl_int128 \
	-labsl_throw_delegate \
	-labsl_raw_logging_internal \
	-labsl_log_severity \
	-lusb-1.0
```

- Build
```bash
cd libedgetpu/makefile_build
TFROOT=$HOME/Repos/tensorflow make -j2 libedgetpu
```

- Install
```bash
sudo cp $HOME/Repos/libedgetpu/out/direct/k8/libedgetpu.so.1.0 /usr/lib/aarch64-linux-gnu/libedgetpu.so.1.0
```

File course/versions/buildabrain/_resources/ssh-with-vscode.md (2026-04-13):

# SSH with Visual Studio Code
Connecting to a remote computer (such as your NB3's Raspberry Pi) via SSH using Visual Studio Code.

## Requirements
1. You are connected to the same network as your NB3
2. You have VS Code *and* the Remote-SSH extension installed

## Fist Connection
The first time you connect to your NB3, your computer will have no idea who this new computer is. It will therefore ask you to confirm that you do indeed want to connect and it will *store* some useful info about this connection.

- Select the Icon to "Open a Remote Window"

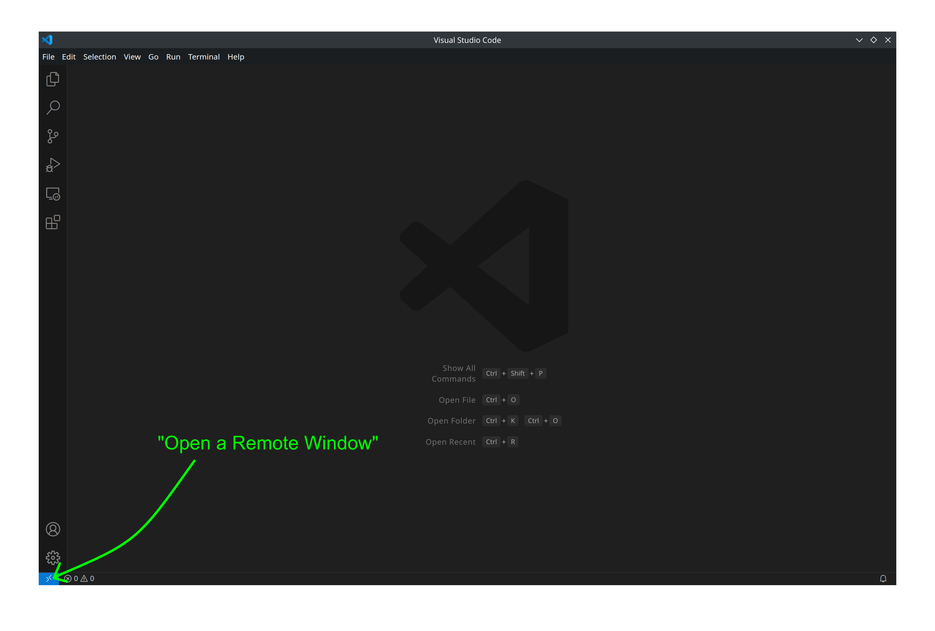
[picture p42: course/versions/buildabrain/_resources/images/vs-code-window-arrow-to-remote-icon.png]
Open a Remote Window


- A dialog window will appear, select "Connect to Host..."

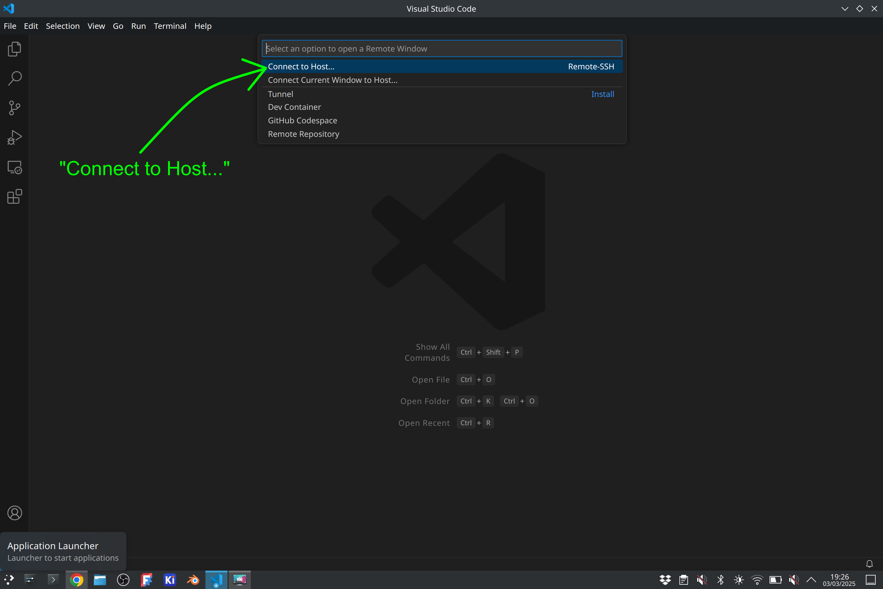
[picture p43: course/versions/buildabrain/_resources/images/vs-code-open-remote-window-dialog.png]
Connect to Host


- Another dialog will appear, select "+ Add New SSH Host"

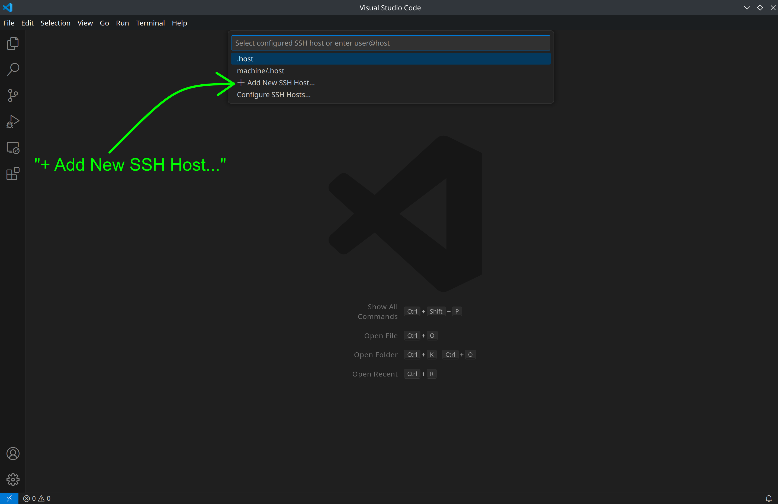
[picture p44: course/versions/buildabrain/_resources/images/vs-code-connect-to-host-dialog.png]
+ Add New SSH Host


- And yet another dialog will appear asking you to enter your SSH connection command. Enter the SSH command to connect your **USER** to your **NB3's IP Address**.

```txt
ssh <your-user-name-on-NB3>@<your-NB3's-IP-address>

# Example
ssh student@192.168.1.170
```

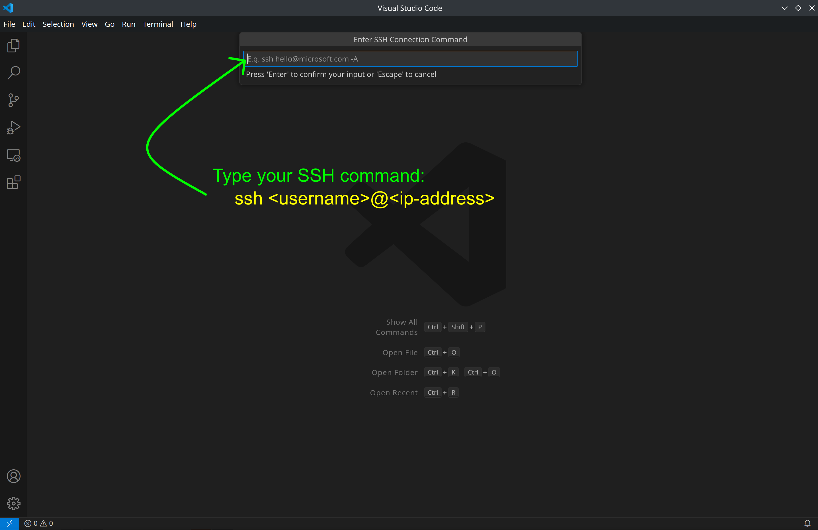
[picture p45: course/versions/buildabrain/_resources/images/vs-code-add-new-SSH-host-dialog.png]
Enter SSH Connection Command


- You will then be asked where to save the SSH configuration. Select the first (default) option, which will save the details (username and IP address) of your SSH connection into this file. *Note*: It is a good idea to wite down this location, as you may need to access this "config" file (or other files in the same folder) in the future...if something goes wrong.

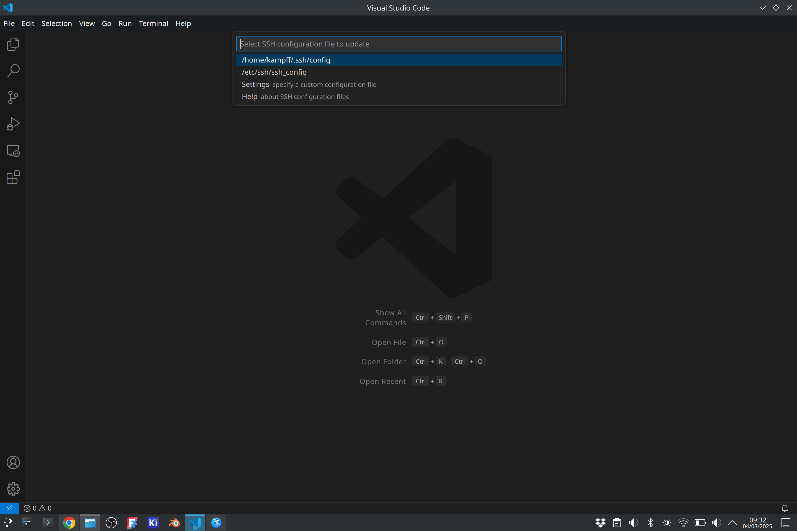
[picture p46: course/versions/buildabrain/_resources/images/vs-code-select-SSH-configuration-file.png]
Select the SSH Configuration File


- A pop-up will now appear telling you that a new host has been added to the "config" file and asking if you want to open this file or "Connect". Select "Connect".

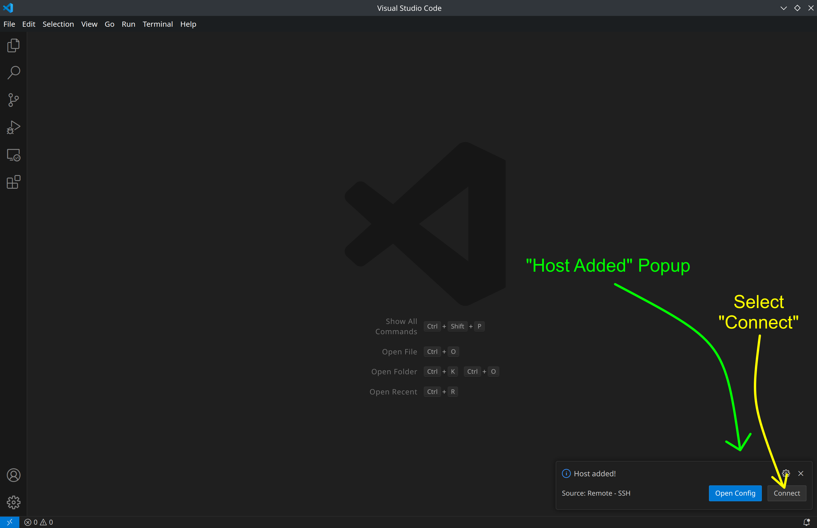
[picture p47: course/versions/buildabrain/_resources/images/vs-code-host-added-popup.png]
Host Added Popup


- A new window will now open in which VS code will attempt to connect to your NB3 via SSH. You will see a variety of messages as the connection is formed...

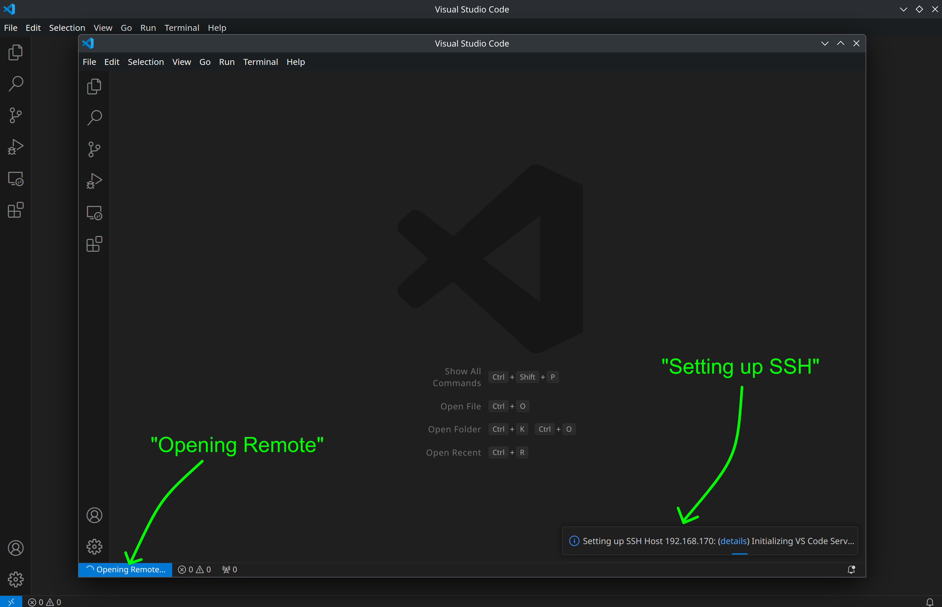
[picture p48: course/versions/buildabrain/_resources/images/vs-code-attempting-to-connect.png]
Attempting to Connect


- ...if all goes well, then you will see a dialog appear telling you that the computer (at a particular IP Address) you are connecting to has a particular "fingerprint". This fingerprint is a long number that *summarizes* the details of your NB3's hardware and software. Select "continue". 
  - *Note*: This is a security check. If someone were to secretly *change* the computer at the IP address that was previously assigned to your NB3, then this fingerprint will change...and VS code/SSH will prevent you from connecting to this new (potentially malicious) computer. Often, however, *you* will be the one that changes the software of your NB3 (if, for example, you were to re-install the NB3's Operating System), which is common cause of connection issues. Instructions for re-connecting to an altered NB3 will be discussed below in the "troubleshooting" section.

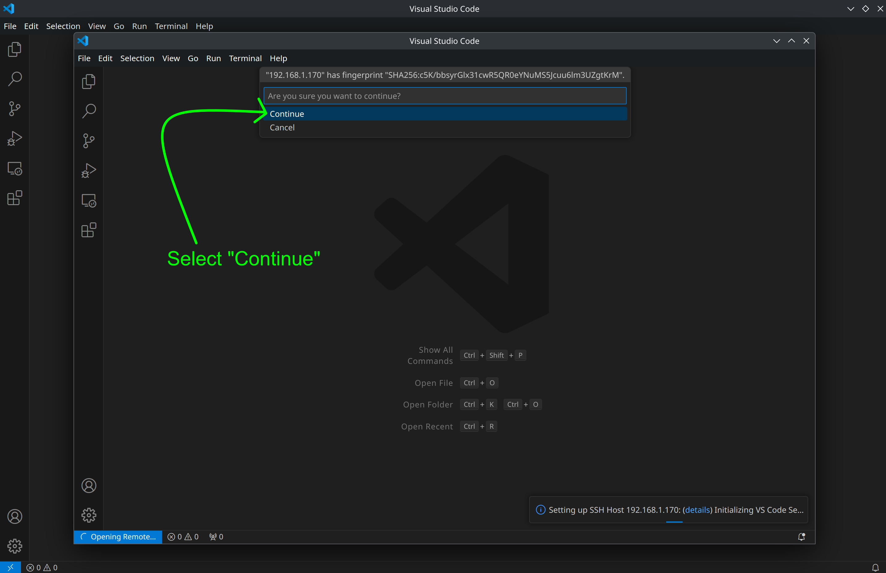
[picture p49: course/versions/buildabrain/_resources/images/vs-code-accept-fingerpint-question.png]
Accept Fingerprint


- You will now be asked to enter your user's password.

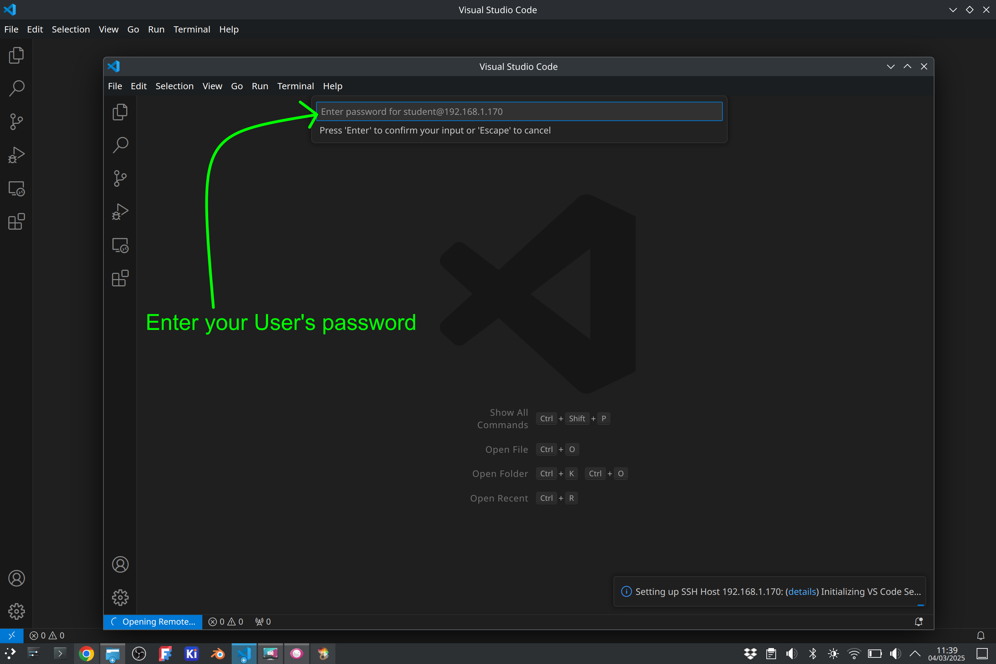
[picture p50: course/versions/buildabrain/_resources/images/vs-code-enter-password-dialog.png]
Enter User Password


- That's it. If all goes well, then you will be connected to your NB3!

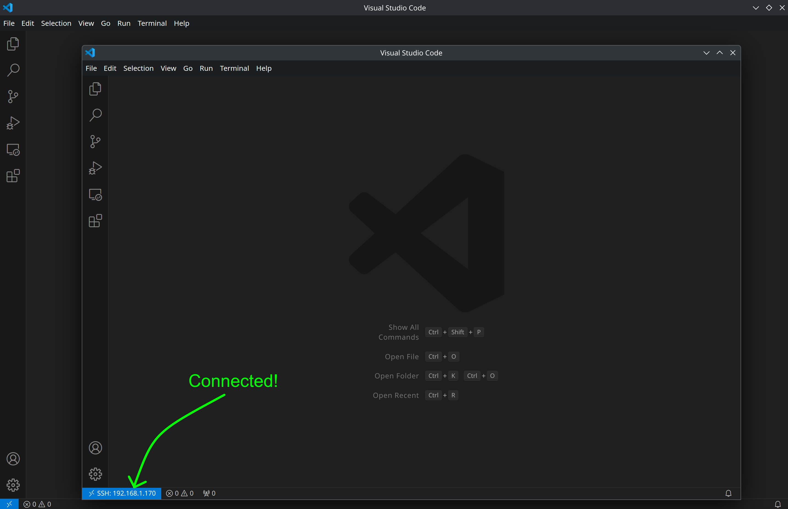
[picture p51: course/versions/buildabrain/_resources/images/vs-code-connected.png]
Connected


## Reconnection
Reconnecting to your NB3 is much easier (and faster) as VS code will remember many of the details from your first connection.

- Open VS code and select the "Open a Remote Window" Icon.

Open a Remote Window

- Select "Connect to Host" in the dialog window.

Connect to Host

- A new dialog will appear showing your stored SSH configurations. Select your NB3's IP address.

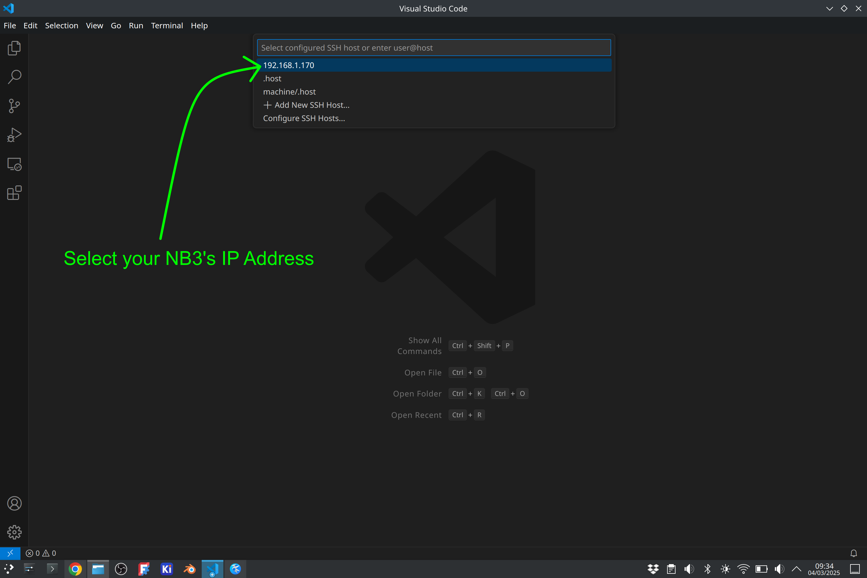
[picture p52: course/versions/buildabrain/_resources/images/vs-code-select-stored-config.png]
Select Stored SSH Configuration


- You should now be prompted to enter your password.

Enter User Password

- If all goes well, then you will be connected to your NB3!

Connected

## Troubleshooting

There is a lot going on when a remote (secure) connection is formed between computers...and thus there is a lot that can go *wrong*. Below are some steps to help you "debug" the most common connection issues.

0. Are you certain you are connected to the same network as your NB3?
1. Turn it Off and On again. Seriously.
   - Close and re-Open VS Code..try again.
   - Power Off your NB3, turn it back On, and give it time to connect to the Network...try again.
2. Have you changed your NB3's operating system (often done by replacing/re-burning the SD card)?
   - This will alter the "fingerprint" of your NB3 and SSH/VS Code won't allow you to connect for "security reasons". You will have to "un-remember" your previous NB3 in order to allow a new, updated fingerprint to be stored. This can be done by deleting the contents of a file called "known_hosts" in the same folder as your SSH config file. Simply find the file, open it, and delete any entries that refer to your NB3's IP address. Ask a TA for some help. You can run the following in teh terminal to open the file Known_host:

   ```
   nano ~/.ssh/known_hosts
   ```

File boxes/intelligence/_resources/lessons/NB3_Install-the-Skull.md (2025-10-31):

# Intelligence : NB3 : Install the Skull
Let's install a "skull" (cover) for our robot.

## [Video]()

## Concepts

## Lesson

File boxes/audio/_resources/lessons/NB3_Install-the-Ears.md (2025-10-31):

# Audio : NB3 : Install the Ears
Let's add some ears to your NB3.

## [Video](https://vimeo.com/1042943195)

## Concepts

## Lesson

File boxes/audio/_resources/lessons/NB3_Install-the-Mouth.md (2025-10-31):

# Audio : NB3 : Install the Mouth
Let's add a mouth to your NB3.

## [Video](https://vimeo.com/1042947561)

## Concepts

## Lesson

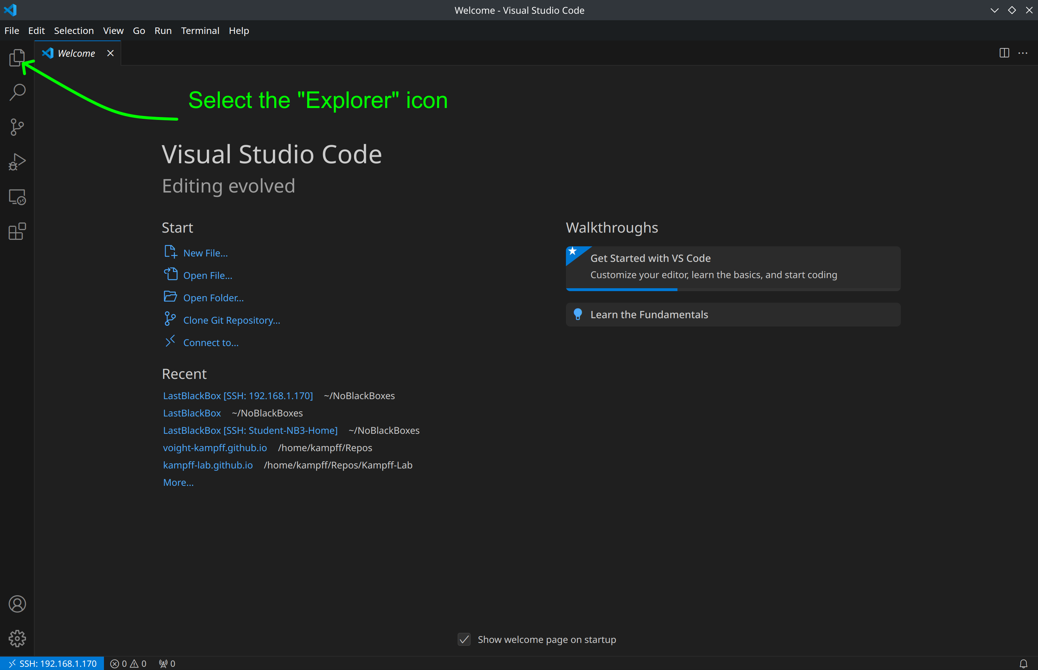
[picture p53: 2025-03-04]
course/versions/buildabrain/_resources/images/linux-vs-code-welcome.png

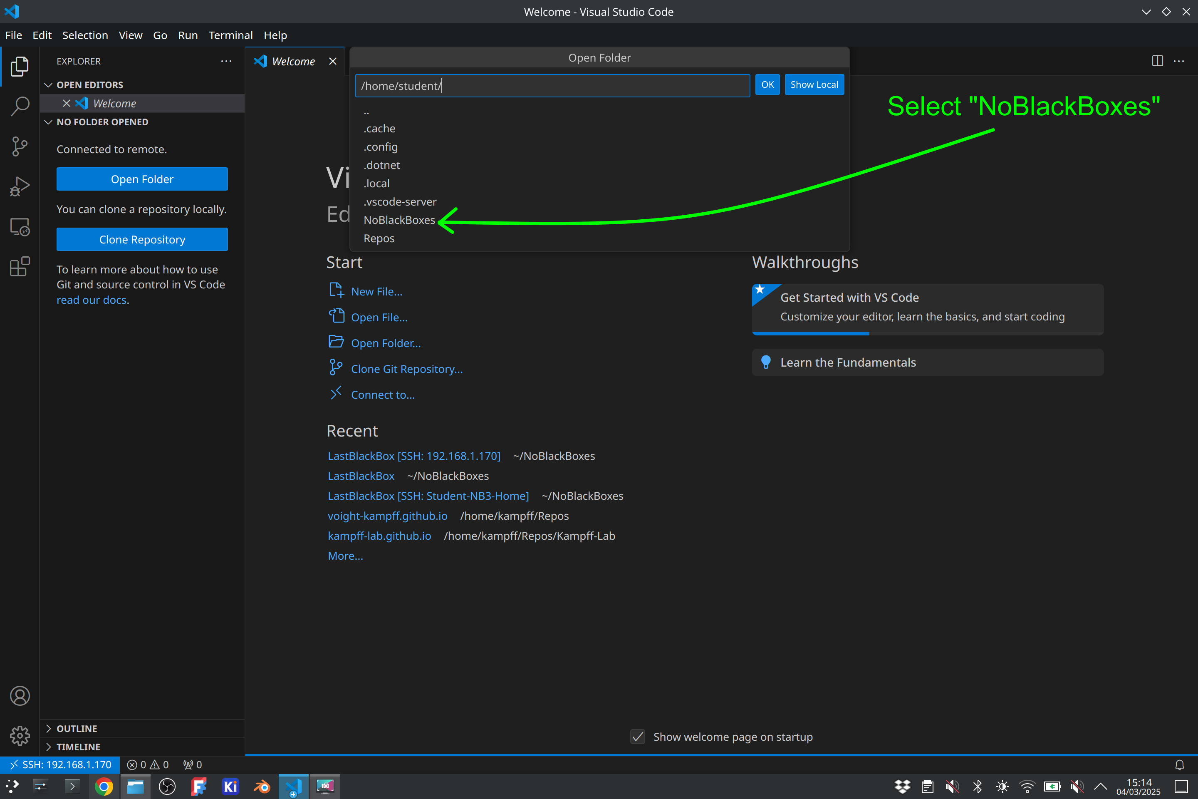
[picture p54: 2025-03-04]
course/versions/buildabrain/_resources/images/linux-vs-code-open-folder-noblackboxes.png

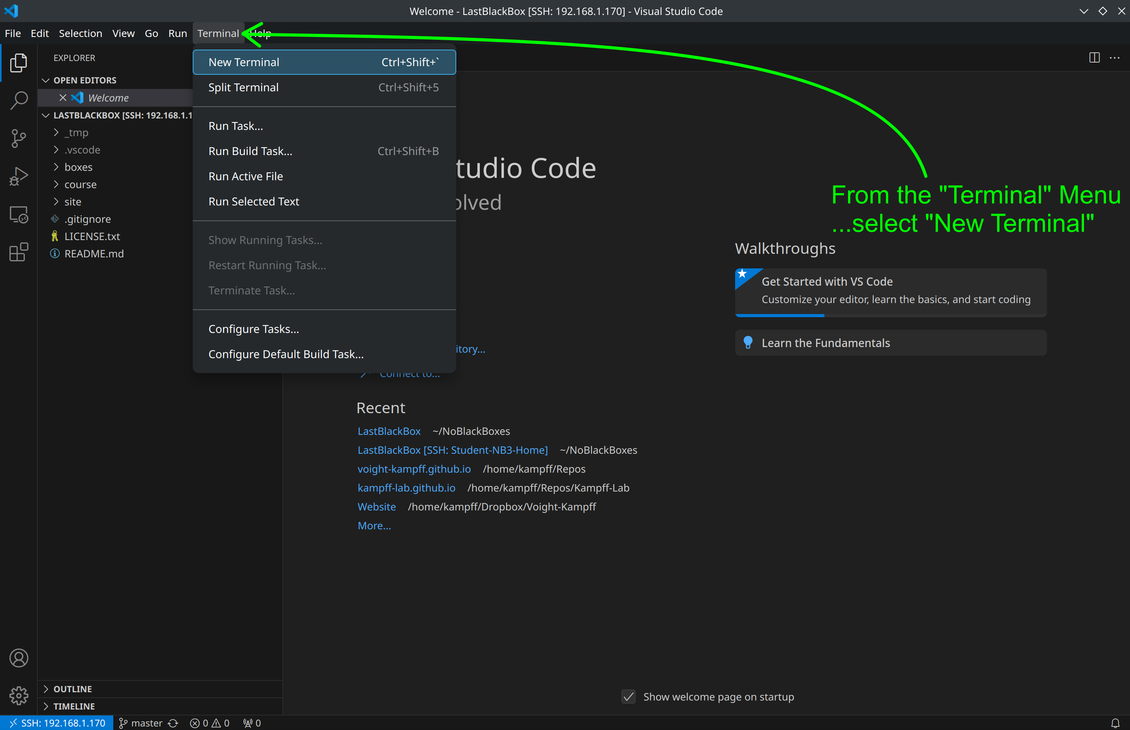
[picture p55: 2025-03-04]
course/versions/buildabrain/_resources/images/linux-vs-code-new-terminal.png

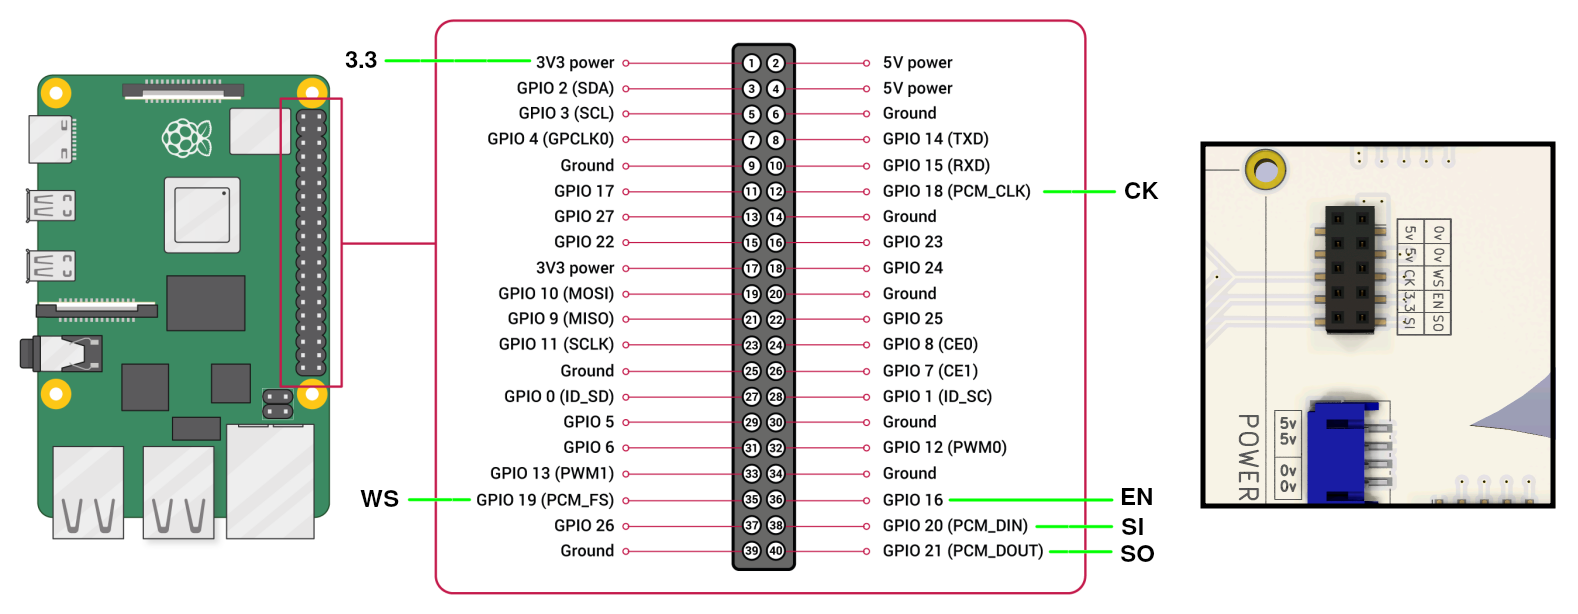
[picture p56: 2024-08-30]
boxes/audio/i2s/_resources/images/NB3_audio_wiring.png

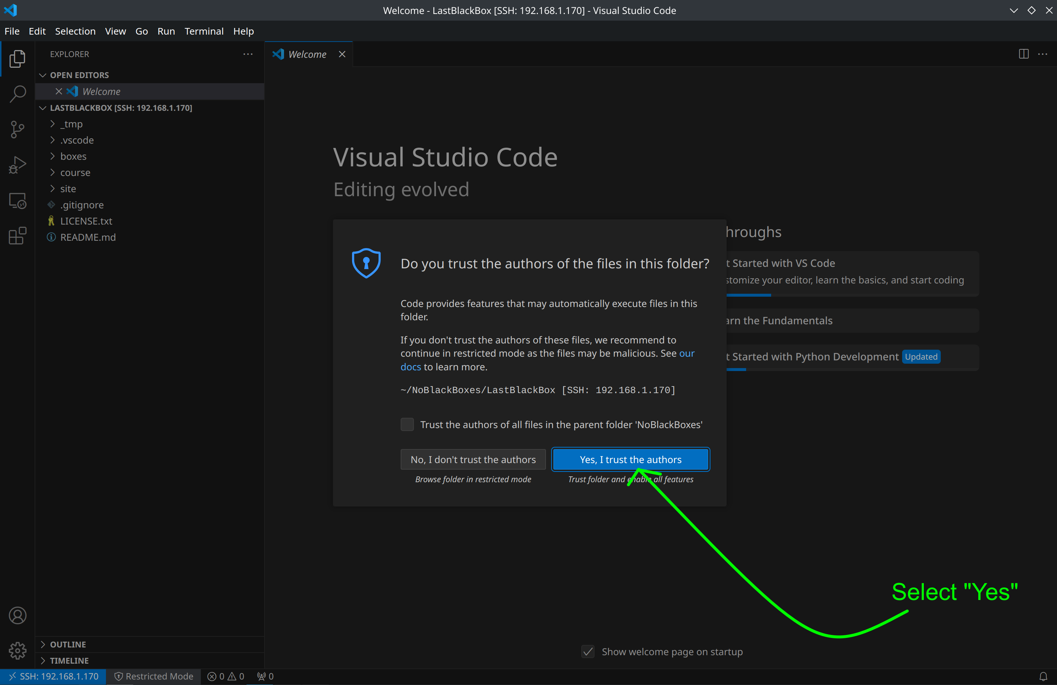
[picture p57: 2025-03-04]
course/versions/buildabrain/_resources/images/linux-vs-code-do-you-trust-repo.png

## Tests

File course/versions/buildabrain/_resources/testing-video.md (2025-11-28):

# Testing your NB3's Video
The following commands will test whether your NB3's Eye (camera) is working.

## Requirements
- Hardware installation of the NB3's eye.
- Open VS Code in the LBB repository folder
- Open a terminal window for entering commands

## Taking a picture (with Linux)
The following command should be entered into the (Linux) terminal window. It will record an image file (PNG) called "test.png" to the current working directory of the terminal.

```bash
# Capture a still image and save it to a file
rpicam-still -o test.png
```

You should see a new file created in the VS Code "file explorer". If you select this file, then you will be able to view it on your own computer.

## Streaming video
We have added a "shortcut" to your Linux installation that will run Python code to "stream" live images from your camera to a website *hosted by your NB3!*. Any device on the **same** network as your NB3 will be able to connect to this website and see what your robot is seeing.

```bash
# Run video streaming
Stream
# - Press Control+C to stop the streaming
```

When the command runs, you will see a link in the terminal with the URL of your NB3's streaming website. If you press "Control" + Click the link, then it will open it in the default web browser. You can also just type the link into the address bar.

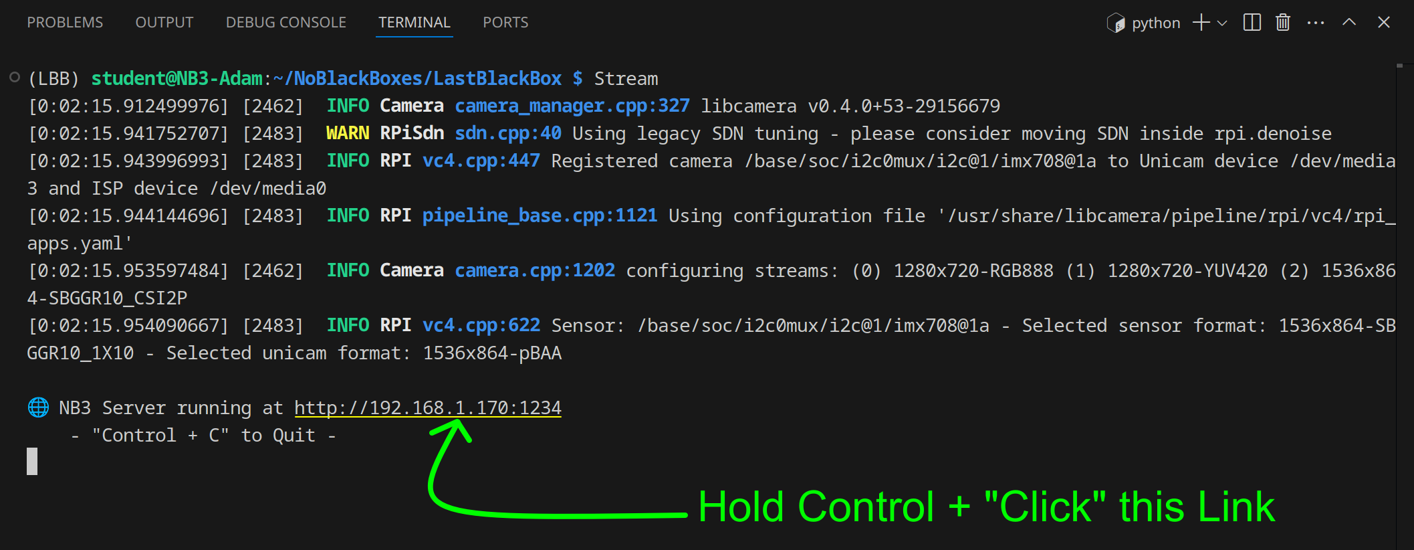
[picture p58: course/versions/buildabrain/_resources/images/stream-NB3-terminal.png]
Stream-NB3 Terminal


The Python code that is run when you enter the "Stream" command is located [here](/boxes/vision/stream-NB3/stream.py).

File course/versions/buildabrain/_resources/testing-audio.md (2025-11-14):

# Testing your NB3's Audio
The following commands will test whether your NB3's Ears (microphones) and Mouth (speaker) are working.

## Requirements
- Software installation for NB3 audio (I2S) driver. This may have been done for you.
- Hardware installation (wiring) of the NB3's ears and mouth.
- Open VS Code in the LBB repository folder
- Open a terminal window for entering commands

## Testing the Ears
The following command should be entered into the (Linux) terminal window. It will record an audio file (WAV) called "file_stereo.wav" to the current working directory of the terminal.

```bash
# Record a sound
arecord -D plughw:3 -c2 -r 48000 -f S32_LE -t wav -V stereo -v file_stereo.wav
# - Press Control+C to stop the recording
```

You should see a new file created in the VS Code "file explorer". If you select this file, then you will be able to play it back on your own computer.

## Testing the Mouth
The following command should be entered into the (Linux) terminal window. It will playback the audio file (WAV) called "file_stereo.wav" using the NB3's speaker.

```bash
# Playback recording
aplay -D plughw:3 -c2 -r 48000 -f S32_LE -t wav -V stereo -v file_stereo.wav
# - Press Control+C to stop the playback
```

Don't worry if the sound playing is rather quiet. This is simply a "scaling" issue caused by the microphones (ears) recording a very high resolution audio file. We can adjust the volume later.

## Play some music using Python!
Use Python to play a music file.

```bash
# Play some music
python $LBB/boxes/audio/i2s/python/output/play_wav.py $LBB/_tmp/sounds/Rose_Mars_APT.wav
# - Press "q" to stop the playback
```

## Download more music (of dubious legality)
You can download music from YouTube using a handy command line tool!

Download and install the YouTube download tool.

```bash
mkdir ~/.local/bin
wget https://github.com/yt-dlp/yt-dlp/releases/latest/download/yt-dlp -O ~/.local/bin/yt-dlp
chmod a+rx ~/.local/bin/yt-dlp  # Make executable
```

Navigate to your NB3's temporary "sounds" folder using the Linux command "cd" (change directory)

```bash
cd $LBB/_tmp/sounds
```

Find a YouTube video link to your music of choice and run the following command. Be sure to replace the YouTube URL in the command below (https://www.youtube.com/watch?v=dQw4w9WgXcQ) with the link to your YouTube video.

```bash
~/.local/bin/yt-dlp -f bestaudio --extract-audio --audio-format wav --audio-quality 48K -o my_song.wav https://www.youtube.com/watch?v=dQw4w9WgXcQ
```

Play your downloaded song using Python.

```bash
# Play some music
python $LBB/boxes/audio/i2s/python/output/play_wav.py my_song.wav
# - Press "q" to stop the playback
```

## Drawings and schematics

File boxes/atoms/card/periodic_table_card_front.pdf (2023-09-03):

## HHydrogen

1.008 1

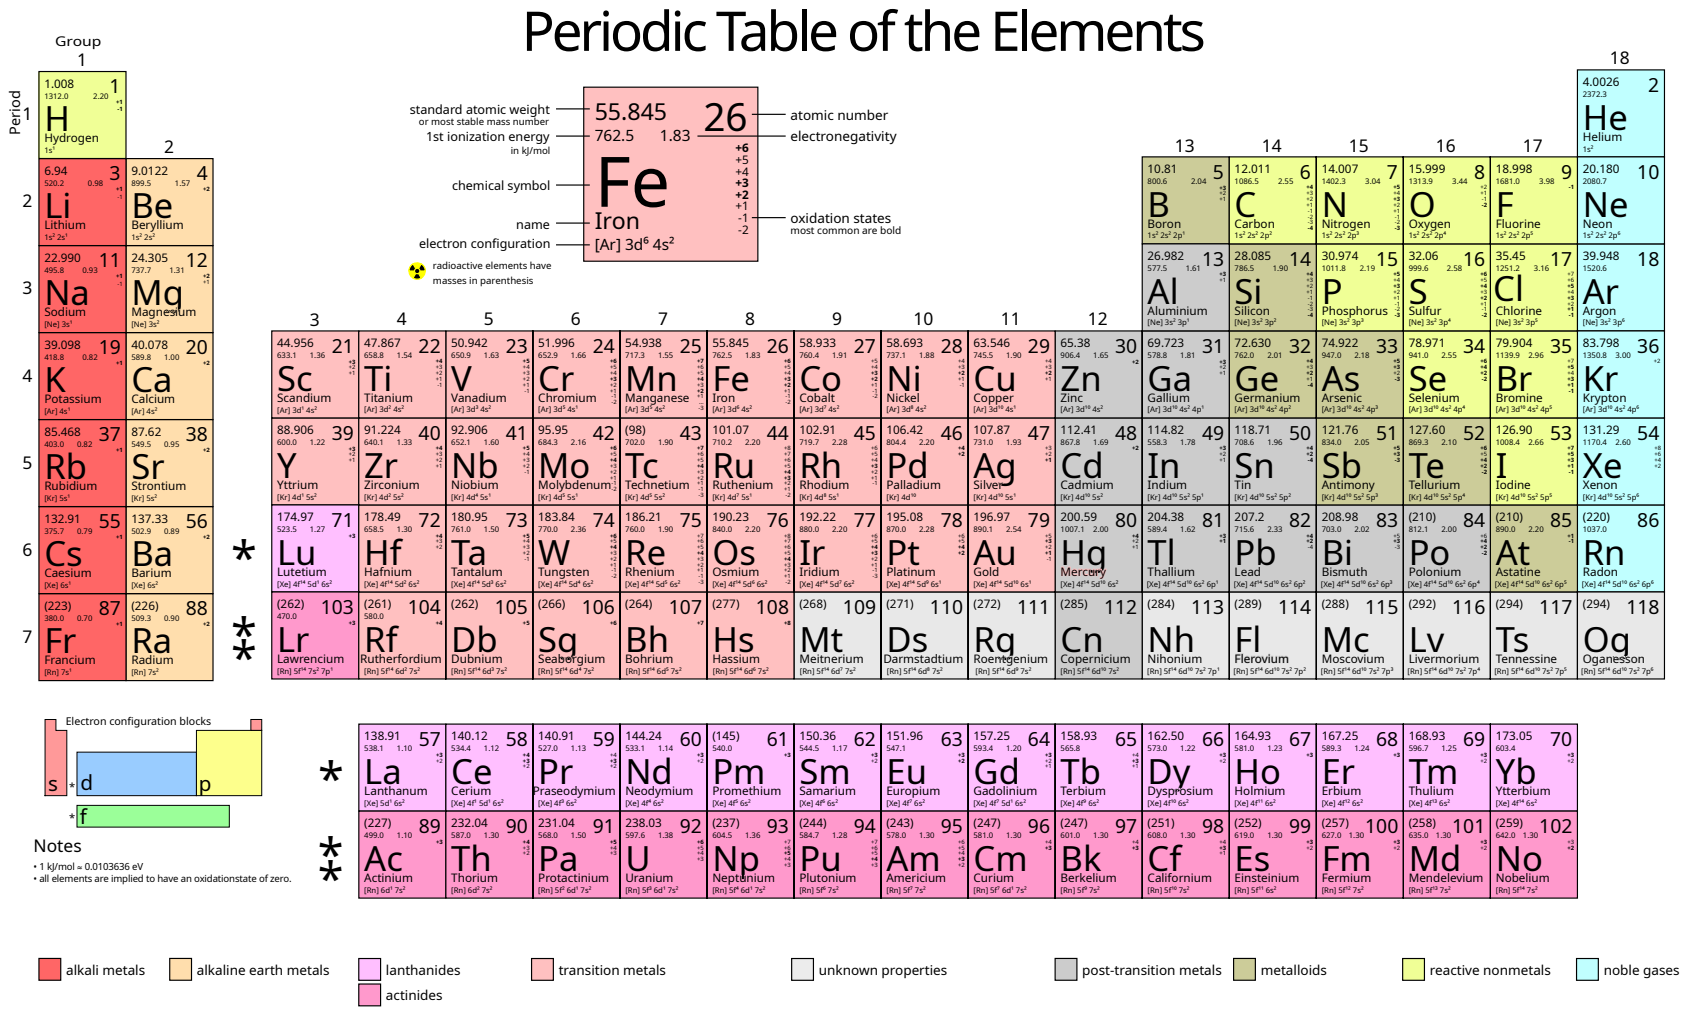
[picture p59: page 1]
Lithium 1s² 2s¹; Beryllium 1s² 2s²; Na Sodium; Magnesium [Ne] 3s²; KPotassium; Calcium [Ar] 4s²; Rubidium [Kr] 5s¹; Strontium [Kr] 5s²; Caesium [Xe] 6s¹; Barium [Xe] 6s²; Francium [Rn] 7s¹; Radium [Rn] 7s²; Scandium [Ar] 3d¹ 4s²; YYttrium; LaLanthanum; Actinium [Rn] 6d¹ 7s²; LuLutetium; [Xe] 4f¹⁴ 5d¹ 6s²; Lawrencium [Rn] 5f¹⁴ 7s² 7p¹; alkali metals; alkaline earth metals; lanthanides; transition metals; post-transition metals; actinides; unknown properties; metalloids; reactive nonmetals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

Periodic Table of the Elements

standard atomic weight
or most stable mass number

in kJ/mol

12.011 6 +3 +2 CCarbon 2.551086.5 +1 1s² 2s² 2p² | 14.007 7 +4 +3 NNitrogen 3.041402.3 +2 +1 −1 −2 −3 −4 1s² 2s² 2p³ | 15.999 8 +5 +4 OOxygen 3.441313.9 +3 +2 +1 −1 −2 −3 1s² 2s² 2p⁴ | 18.998 9 +2 +1 FFluorine −1 −2 1s² 2s² 2p⁵ | −1 3.981681.0

electron configuration
radioactive elements have
masses in parenthesis

oxidation states
most common are bold

30.974 15+5 +3 1011.8 PPhosphorus 2.19 +2 +1 −1 −2 −3 −4 [Ne] 3s² 3p³ | 32.06 16+6 +4 SSulfur 2.58999.6 +3 +2 +1 −1 −2 −3 [Ne] 3s² 3p⁴ | +5 +4 +3 +2 +1 −1 −2

50.942 23+5 +3 VVanadium 1.63650.9 +2 +1 −1 [Ar] 3d³ 4s² | 51.996 24+6 +4 Cr 1.66652.9 +3 +2 +1 −1 Chromium [Ar] 3d⁵ 4s¹ | 54.938 25+7 +5 Mn 1.55717.3 +4 +3 +2 +1 −1 −2 Manganese [Ar] 3d⁵ 4s² | 55.845 26+6 +6 FeIron 1.83762.5 +5 +4 +3 +2 +1 −3 … [Ar] 3d⁶ 4s² | 58.933 27+5 +5 Co 1.91760.4 +4 +3 +2 +1 −1 −2 Cobalt [Ar] 3d⁷ 4s² | 58.693 28+4 +4 Ni 1.88737.1 +3 +2 +1 −1 −2 Nickel [Ar] 3d⁸ 4s² | 63.546 29+4 +3 Cu 1.90745.5 +2 +1 −1 Copper [Ar] 3d¹⁰ 4s¹ | 65.38 30+2 1.65906.4 +3 ZnZinc +2 +1 [Ar] 3d¹⁰ 4s² | 69.723 31+3 Ga 1.81578.8 [Ar] 3d¹⁰ 4s² 4p¹ Gallium | 72.630 32+4 +2 Ge 2.01762.0 +1 [Ar] 3d¹⁰ 4s² 4p² Germanium | 74.922 33+5 +3 As 2.18947.0 +2 +1 −4 Arsenic [Ar] 3d¹⁰ 4s² 4p³ | 78.971 34+6 +3 SeSelenium 2.55941.0 +2 −3 [Ar] 3d¹⁰ 4s² 4p⁴ | 79.904 35+7 +4 Br 2.961139.9 +2 −2 [Ar] 3d¹⁰ 4s² 4p⁵ Bromine | +5 +4 +3 +1 −1

91.224 40+4 +2 Zr 1.33640.1 +1 Zirconium [Kr] 4d² 5s² | 92.906 41+5 +3 Nb 1.60652.1 +2 +1 Niobium [Kr] 4d⁴ 5s¹ | 95.95 42+6 +4 Mo 2.16684.3 +3 +2 −1 Molybdenum [Kr] 4d⁵ 5s¹ | (98) 43+7 +5 Tc 1.90702.0 +4 +3 +2 +1 Technetium −1 −2 [Kr] 4d⁵ 5s² | 101.07 44+8 +6 Ru 2.20710.2 +5 +4 +3 +2 Ruthenium +1 −1 −3 [Kr] 4d⁷ 5s¹ | 102.91 45+6 +7 Rh 2.28719.7 +6 +5 +4 +3 Rhodium +2 +1 −2 [Kr] 4d⁸ 5s¹ | 106.42 46+4 +5 PdPalladium 2.20804.4 +4 +3 +2 +1 −1 [Kr] 4d¹⁰ | 107.87 47+3 +2 AgSilver 1.93731.0 [Kr] 4d¹⁰ 5s¹ | 112.41 48+2 1.69867.8 +2 Cd +1 Cadmium [Kr] 4d¹⁰ 5s² | 114.82 49+3 InIndium 1.78558.3 [Kr] 4d¹⁰ 5s² 5p¹ | 118.71 50+4 +2 SnTin 1.96708.6 +1 [Kr] 4d¹⁰ 5s² 5p² | 121.76 51+5 +2 Sb 2.05834.0 −4 Antimony [Kr] 4d¹⁰ 5s² 5p³ | 127.60 52+6 +3 TeTellurium 2.10869.3 −3 [Kr] 4d¹⁰ 5s² 5p⁴ | +5 +4 +2 −2
178.49 72+4 Hf 1.30658.5 Hafnium [Xe] 4f¹⁴ 5d² 6s² | 180.95 73+5 +3 +2 TaTantalum 1.50761.0 [Xe] 4f¹⁴ 5d³ 6s² | 183.84 74+6 +4 +3 WTungsten 2.36770.0 +2 −1 [Xe] 4f¹⁴ 5d⁴ 6s² | 186.21 75+7 +5 +4 Re 1.90760.0 +3 +2 +1 Rhenium −1 −2 [Xe] 4f¹⁴ 5d⁵ 6s² | 190.23 76+8 +6 +5 Os 2.20840.0 +4 +3 +2 Osmium +1 −1 −3 [Xe] 4f¹⁴ 5d⁶ 6s² | 192.22 77+6 +7 +6 Ir 2.20880.0 +5 +4 +3 Iridium +2 +1 −2 [Xe] 4f¹⁴ 5d⁷ 6s² | 195.08 78+6 +5 +4 Pt 2.28870.0 +3 +2 +1 Platinum −1 −3 [Xe] 4f¹⁴ 5d⁹ 6s¹ | 196.97 79+5 +5 +4 Au 2.54890.1 +2 Gold [Xe] 4f¹⁴ 5d¹⁰ 6s¹ | 200.59 80+4 +3 +2 Hg 2.001007.1 +1 −1 Mercury [Xe] 4f¹⁴ 5d¹⁰ 6s² | 204.38 81+3 +2 +1 Tl 1.62589.4 Thallium [Xe] 4f¹⁴ 5d¹⁰ 6s² 6p¹ | 207.2 82+4 +1 PbLead 2.33715.6 [Xe] 4f¹⁴ 5d¹⁰ 6s² 6p² | 208.98 83+5 +2 −4 Bi 2.02703.0 Bismuth [Xe] 4f¹⁴ 5d¹⁰ 6s² 6p³ | (210) 84+6 +3 −3 PoPolonium 2.00812.1 [Xe] 4f¹⁴ 5d¹⁰ 6s² 6p⁴ | +4 +2 −2
(261) 104+4 580.0 Rf Rutherfordium [Rn] 5f¹⁴ 6d² 7s² | (262) 105+5 Db Dubnium [Rn] 5f¹⁴ 6d³ 7s² | (266) 106+6 SgSeaborgium | (264) 107+7 Bh Bohrium | (277) 108+8 Hs Hassium | (268) 109 Mt Meitnerium | (271) 110 Ds Darmstadtium | (272) 111 Rg Roentgenium | | (284) 113 Nh Nihonium | (289) 114 Fl Flerovium | (288) 115 Mc Moscovium | (292) 116 Lv Livermorium | (294) 117 Ts Tennessine

Electron configuration blocks
Notes
• 1 kJ/mol ≈ 0.0103636 eV
• all elements are implied to have an oxidationstate of zero.

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

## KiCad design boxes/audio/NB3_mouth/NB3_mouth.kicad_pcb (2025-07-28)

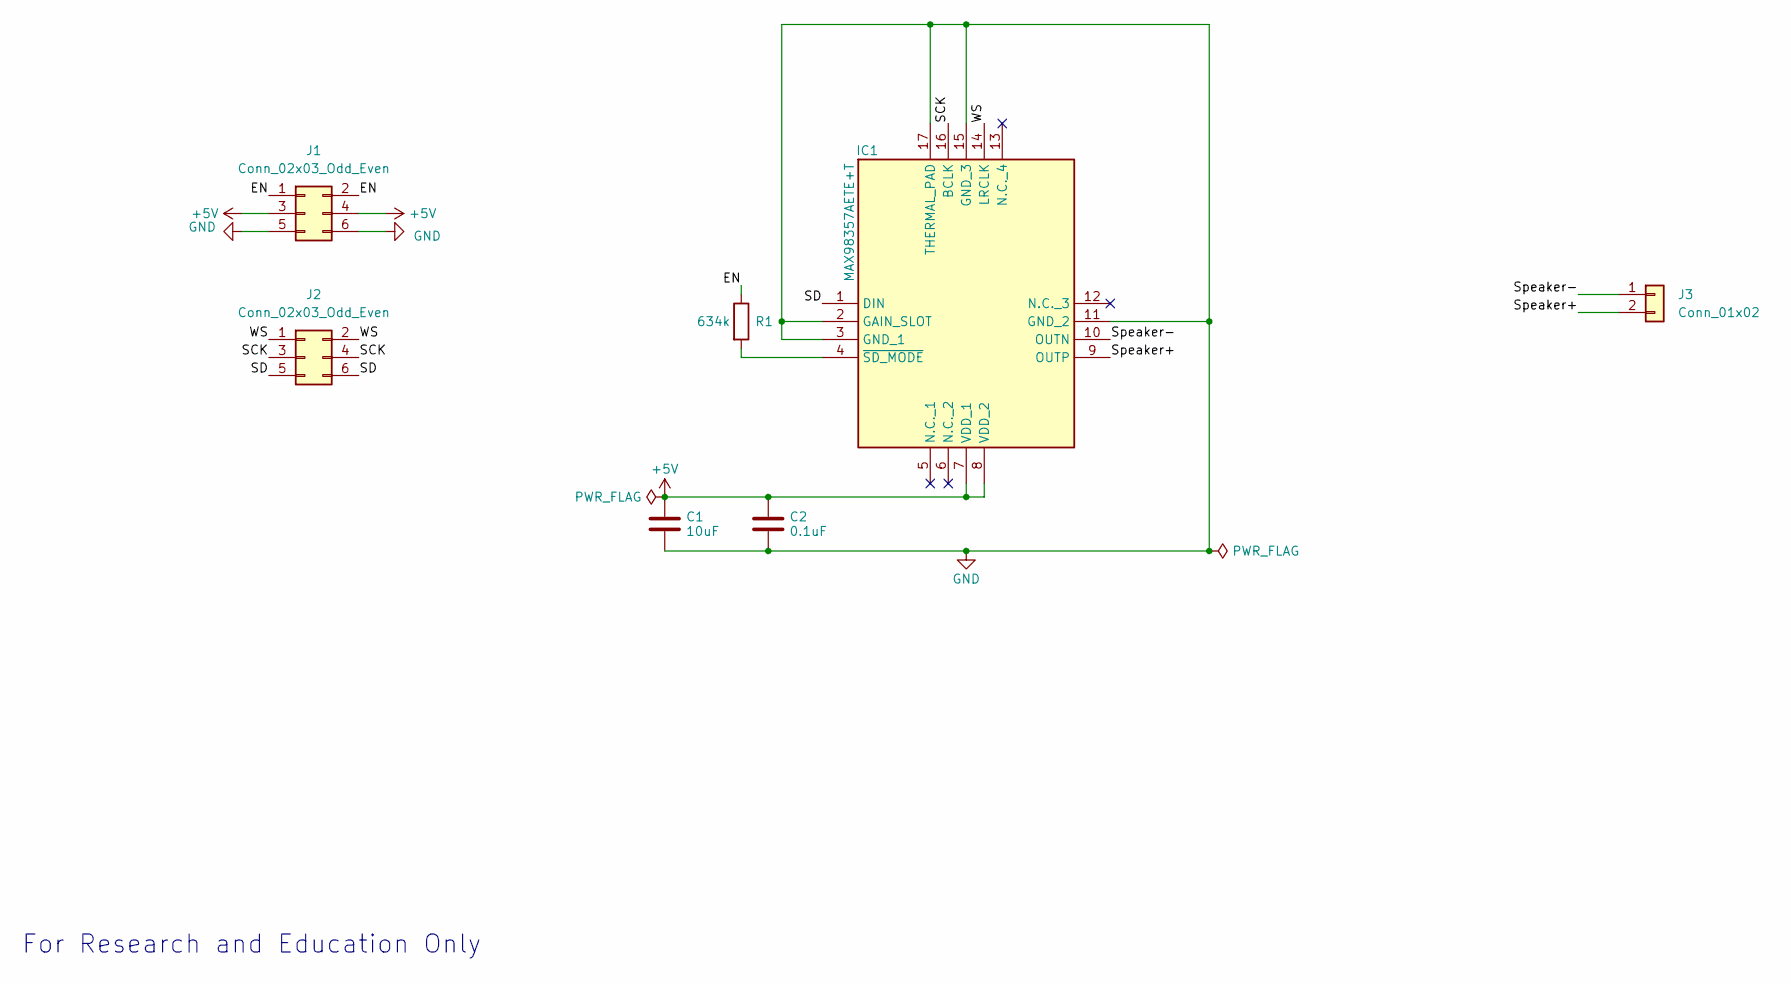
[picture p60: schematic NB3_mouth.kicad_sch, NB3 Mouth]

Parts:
C1: 10uF; C_0805_2012Metric
C2: 0.1uF; C_0402_1005Metric
IC1: MAX98357AETE+T; I2S_DAC-AMP_MAX98357A; Mouser Part Number 700-MAX98357AETE+T
J1, J2: Conn_02x03_Odd_Even; PinHeader_2x03_P2.54mm_Vertical_SMD
J3: Conn_01x02; PinHeader_1x02_P2.54mm_Horizontal
R1: 634k; R_0402_1005Metric

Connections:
+5V: C1.1, C2.1, IC1.7 (VDD_1), IC1.8 (VDD_2), J1.3, J1.4
/EN: J1.1, J1.2, R1.1
/SCK: IC1.16 (BCLK), J2.3, J2.4
/SD: IC1.1 (DIN), J2.5, J2.6
/Speaker+: IC1.9 (OUTP), J3.2
/Speaker-: IC1.10 (OUTN), J3.1
/WS: IC1.14 (LRCLK), J2.1, J2.2
GND: C1.2, C2.2, IC1.2 (GAIN_SLOT), IC1.3 (GND_1), IC1.11 (GND_2), IC1.15 (GND_3), IC1.17 (THERMAL_PAD), J1.5, J1.6
unnamed: IC1.4 (~SD_MODE), R1.2

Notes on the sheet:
For Research and Education Only

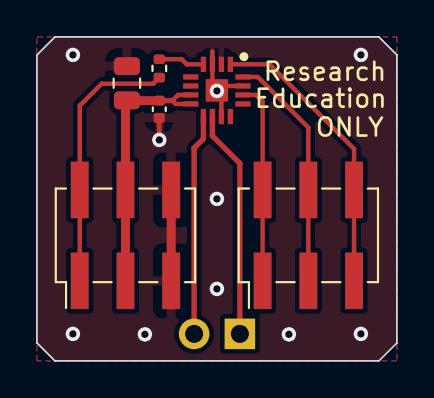
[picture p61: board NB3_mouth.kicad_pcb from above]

Board: 2 copper layers, 20.0 x 18.0 mm, 7 parts (1 on the bottom side), 9 nets.

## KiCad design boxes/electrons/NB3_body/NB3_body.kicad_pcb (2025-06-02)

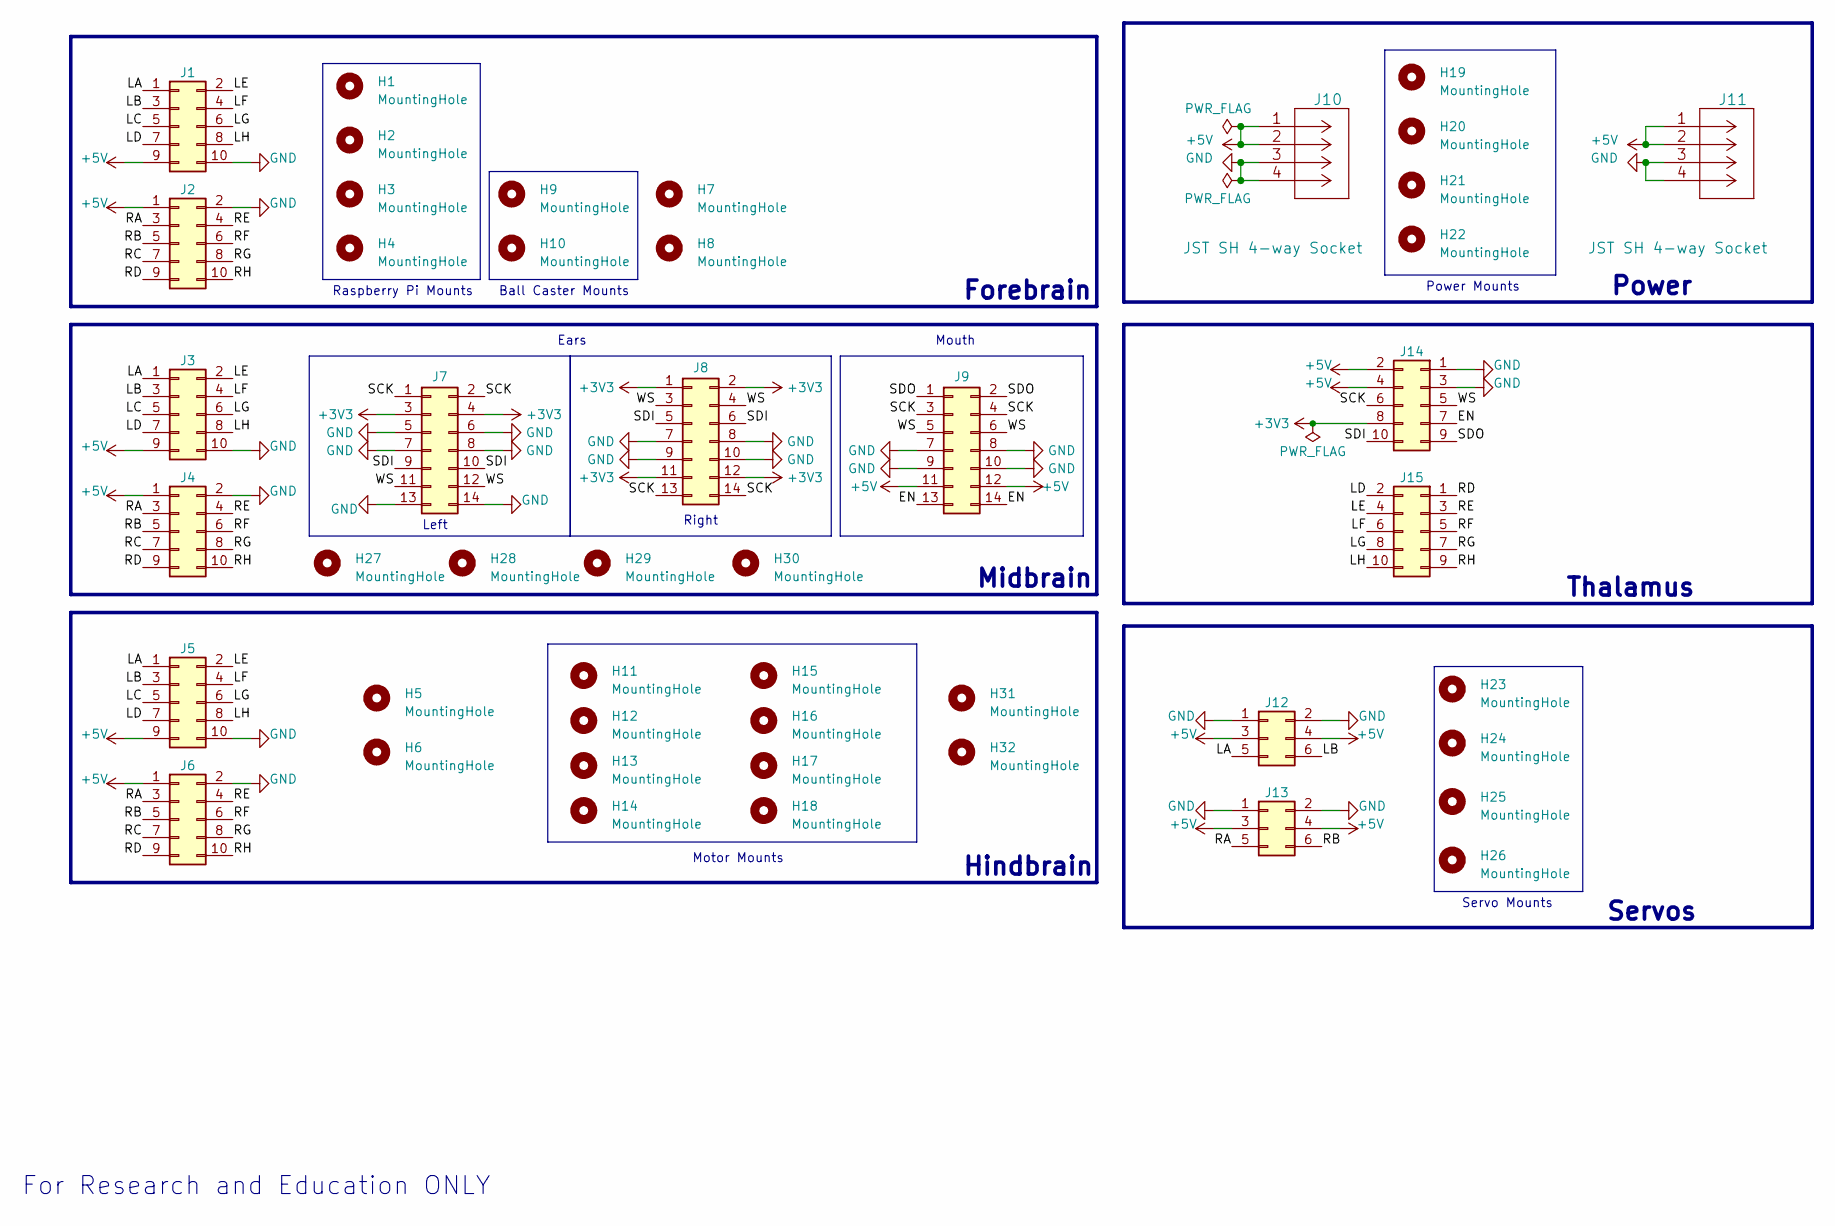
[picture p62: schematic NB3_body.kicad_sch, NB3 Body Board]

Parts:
H1, H2, H3, H4, H5, H6, H7, H8, H19, H20, H21, H22, H23, H24, H25, H26, H27, H28, H29, H30, H31, H32: MountingHole; MountingHole_2.7mm_M2.5_ISO7380_Pad
H9, H10: MountingHole; MountingHole_2.2mm_M2_ISO7380_Pad
H11, H12, H13, H14, H15, H16, H17, H18: MountingHole; MountingHole_3.2mm_M3_ISO7380_Pad
J1, J2, J3, J4, J5, J6, J14, J15: Conn_02x05_Counter_Clockwise; PinSocket_2x05_P2.54mm_Vertical_SMD
J7, J8, J9: Conn_02x07_Odd_Even; PinSocket_2x07_P2.54mm_Vertical_SMD
J10, J11: JST SH 4-way Socket; Connector_S4B-PH-SM4-TB(LF)(SN)
J12, J13: Conn_02x03_Top_Bottom; PinHeader_2x03_P2.54mm_Vertical

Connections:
+3V3: J7.3, J7.4, J8.1, J8.2, J8.11, J8.12, J14.8
+5V: J1.9, J2.1, J3.9, J4.1, J5.9, J6.1, J9.11, J9.12, J10.1, J10.2, J11.1, J11.2, J12.3, J12.4, J13.3, J13.4, J14.2, J14.4
/EN: J9.13, J9.14, J14.7
/LA: J1.1, J3.1, J5.1, J12.5
/LB: J1.3, J3.3, J5.3, J12.6
/LC: J1.5, J3.5, J5.5
/LD: J1.7, J3.7, J5.7, J15.2
/LE: J1.2, J3.2, J5.2, J15.4
/LF: J1.4, J3.4, J5.4, J15.6
/LG: J1.6, J3.6, J5.6, J15.8
/LH: J1.8, J3.8, J5.8, J15.10
/RA: J2.3, J4.3, J6.3, J13.5
/RB: J2.5, J4.5, J6.5, J13.6
/RC: J2.7, J4.7, J6.7
/RD: J2.9, J4.9, J6.9, J15.1
/RE: J2.4, J4.4, J6.4, J15.3
/RF: J2.6, J4.6, J6.6, J15.5
/RG: J2.8, J4.8, J6.8, J15.7
/RH: J2.10, J4.10, J6.10, J15.9
/SCK: J7.1, J7.2, J8.13, J8.14, J9.3, J9.4, J14.6
/SDI: J7.9, J7.10, J8.5, J8.6, J14.10
/SDO: J9.1, J9.2, J14.9
/WS: J7.11, J7.12, J8.3, J8.4, J9.5, J9.6, J14.5
GND: J1.10, J2.2, J3.10, J4.2, J5.10, J6.2, J7.5, J7.6, J7.7, J7.8, J7.13, J7.14, J8.7, J8.8, J8.9, J8.10, J9.7, J9.8, J9.9, J9.10, J10.3, J10.4, J11.3, J11.4, J12.1, J12.2, J13.1, J13.2, J14.1, J14.3

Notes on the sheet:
Ball Caster Mounts
Ears
Servo Mounts
Power
Thalamus
Servos
Hindbrain
Forebrain
Raspberry Pi Mounts
Motor Mounts
For Research and Education ONLY
Right
Midbrain
Left
Power Mounts
Mouth

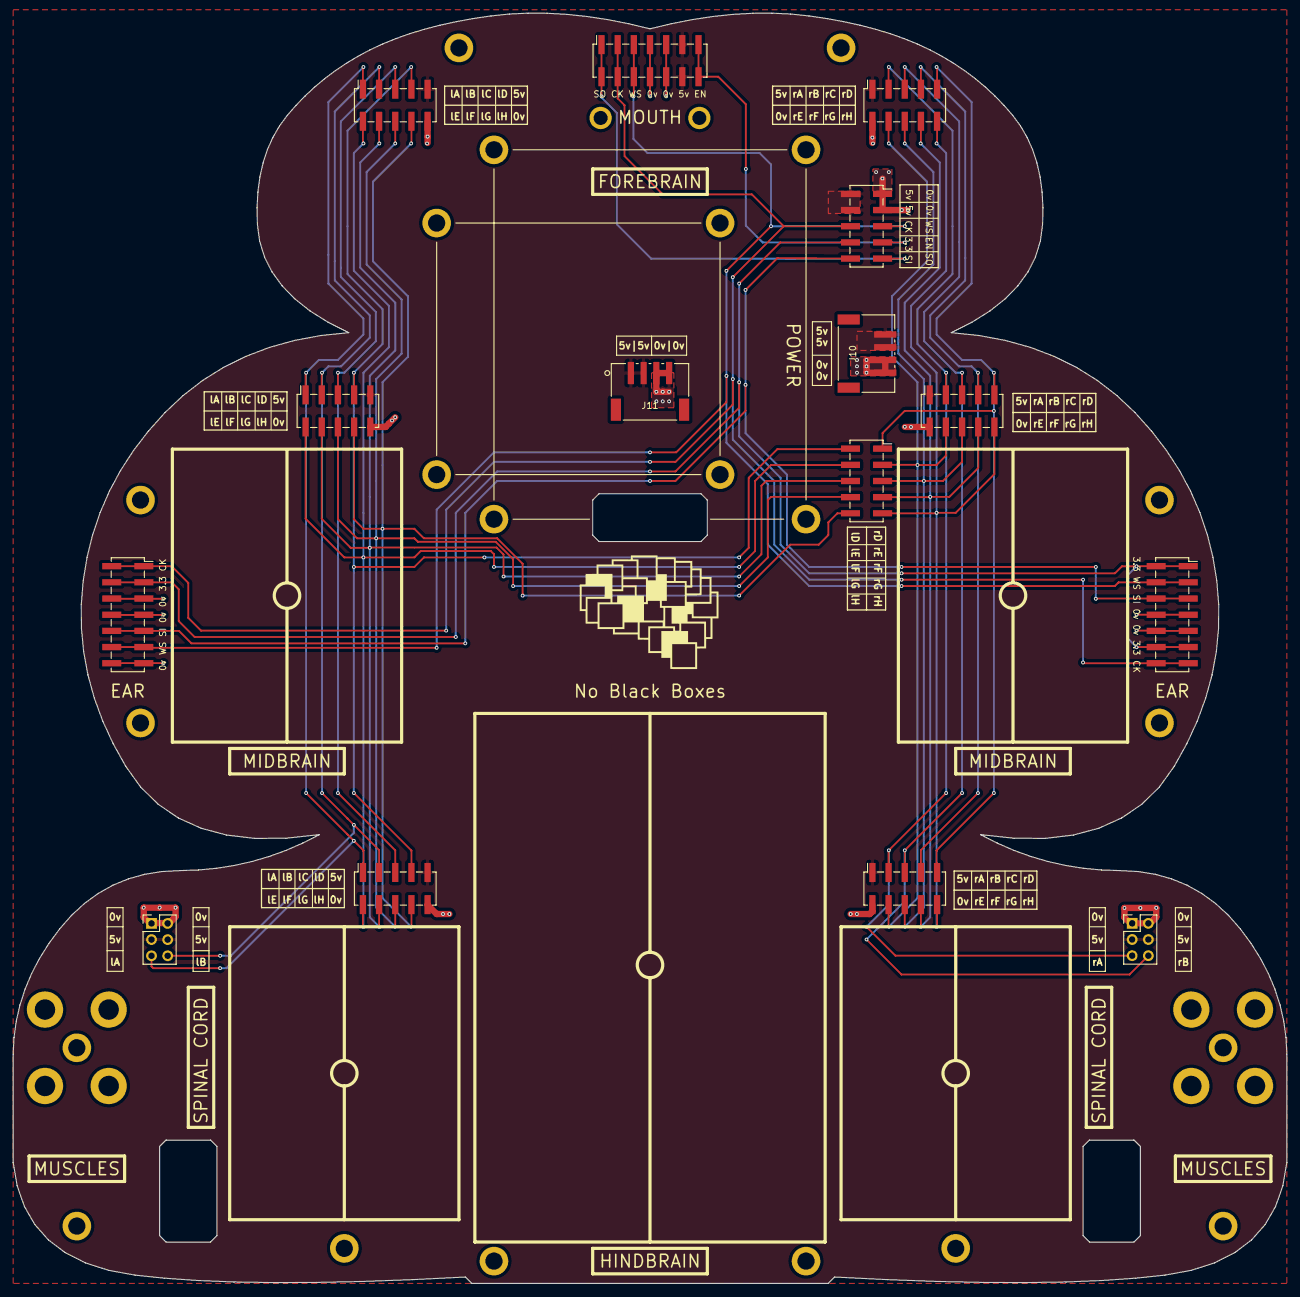
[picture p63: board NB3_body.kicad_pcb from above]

Board: 2 copper layers, 200.0 x 199.5 mm, 47 parts (0 on the bottom side), 24 nets.

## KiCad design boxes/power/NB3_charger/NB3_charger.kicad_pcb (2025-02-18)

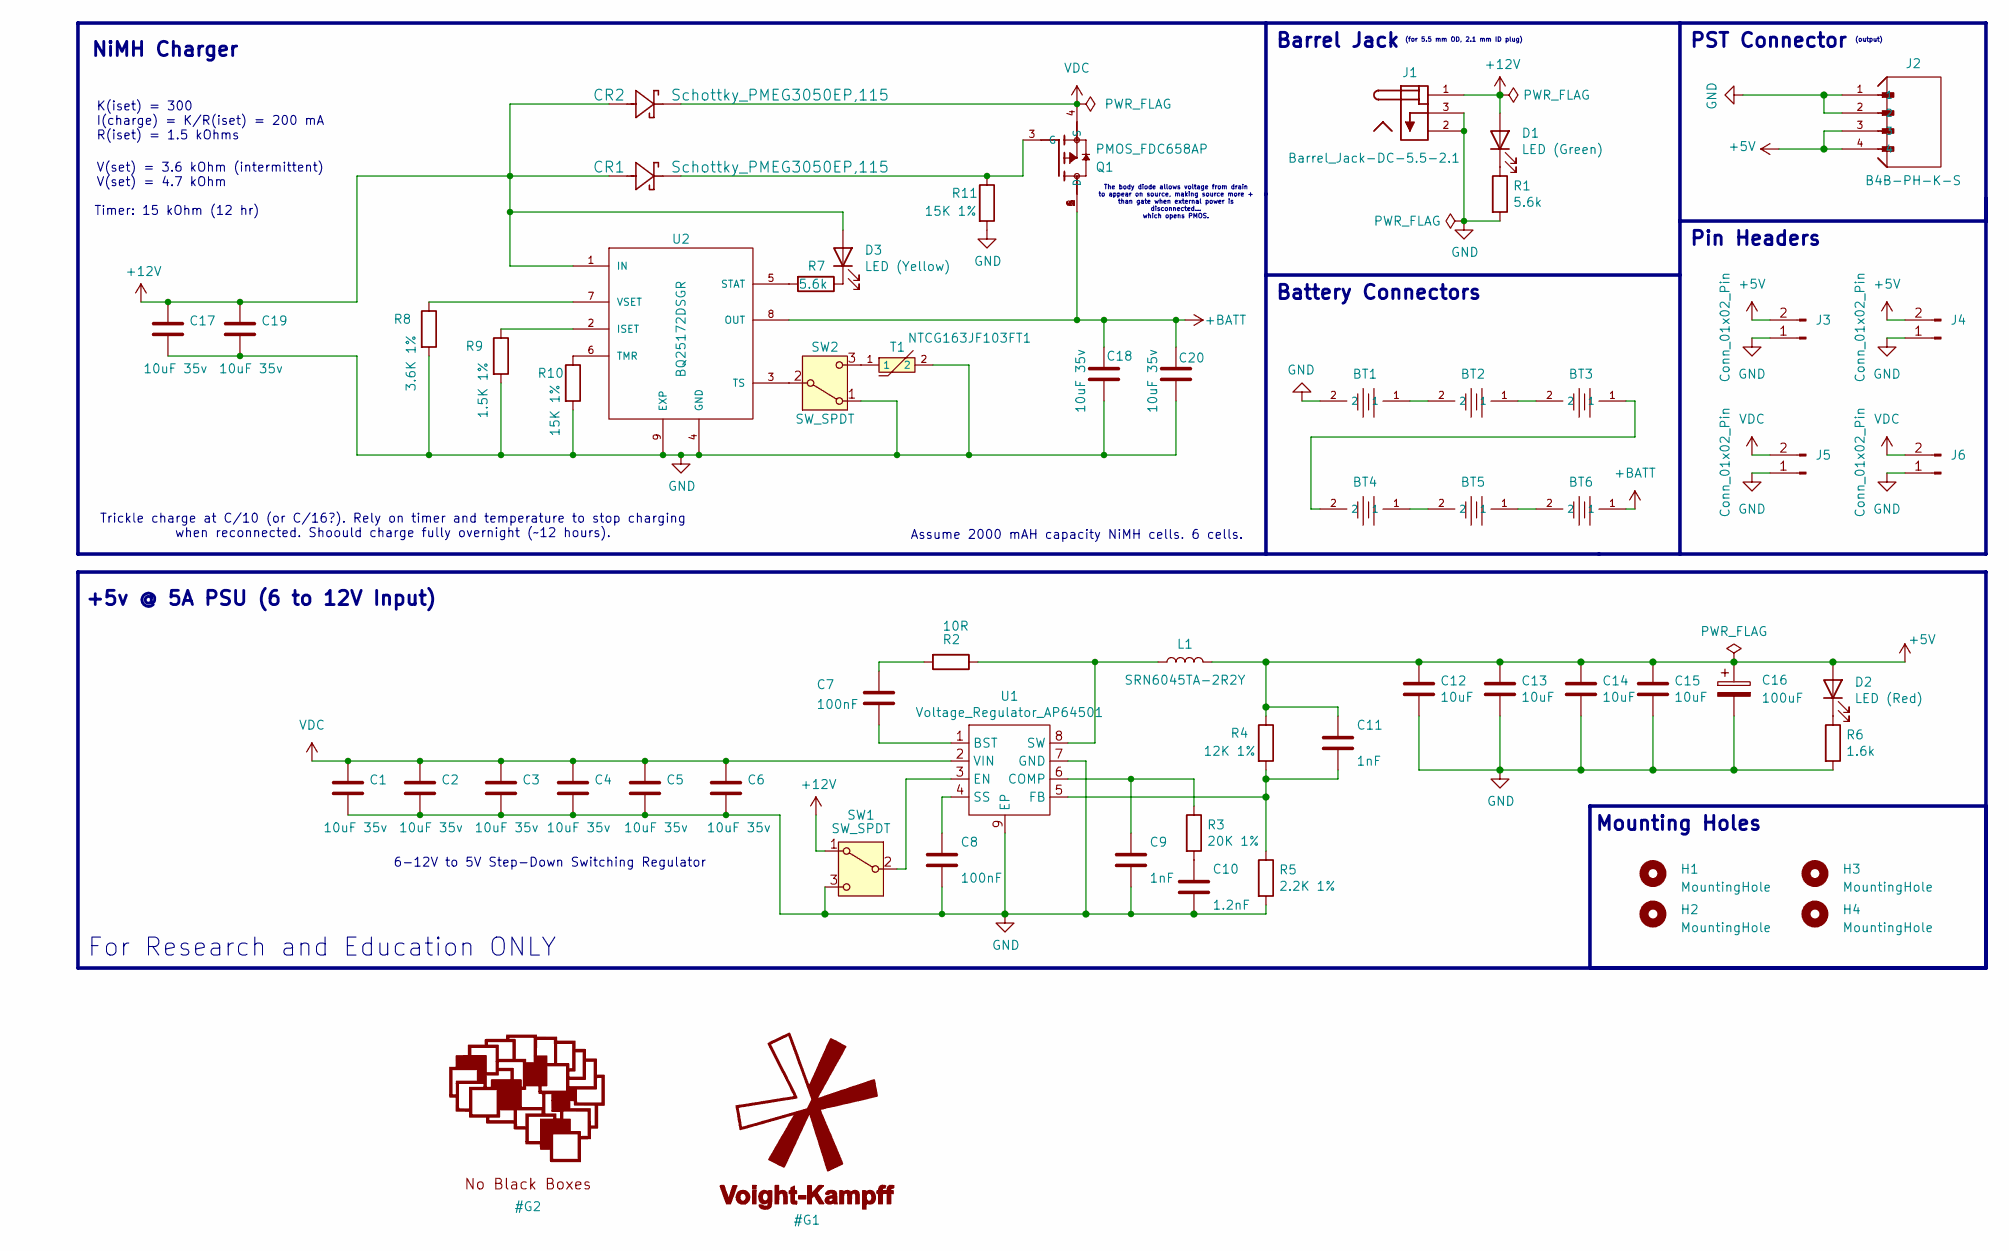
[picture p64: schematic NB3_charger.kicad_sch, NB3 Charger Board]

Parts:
BT1, BT2, BT3, BT4, BT5, BT6: 1028; AA_Battery_Holder_BH-AA-A5BJ012; PARTREV C; LCSC C5290180
C1, C2, C3, C4, C5, C6, C17, C18, C19, C20: 10uF 35v; C_0805_2012Metric; Part Description 10uF 10% or 20% 35V Ceramic Capacitor X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
C7, C8: 100nF; C_0402_1005Metric; Part Description 0.1uF 10% 16V Ceramic Capacitor X7R 040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
C9: 1nF; C_0402_1005Metric
C10: 1.2nF; C_0402_1005Metric; Part Description 1200pF 10% 10V Ceramic Capacitor X5R 04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
C11: 1nF; C_0402_1005Metric; Part Description 220 pF, 50 V, 0402 [1005 Metric], ± 5%,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
C12, C13, C14, C15: 10uF; C_0805_2012Metric; Part Description 10uF 10% 10V Ceramic Capacitor X7R 0805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
C16: 100uF; CP_EIA-7343-31_Kemet-D
CR1, CR2: Schottky_PMEG3050EP,115
D1: LED (Green); LED_0603_1608Metric
D2: LED (Red); LED_0603_1608Metric
D3: LED (Yellow); LED_0603_1608Metric
H1, H2, H3, H4: MountingHole; MountingHole_2.7mm_M2.5_ISO7380_Pad
J1: Barrel_Jack-DC-5.5-2.1; Barrel_Jack_TH_XUNPU_DC-005-A200; MPN DC-005-A200; LCSC C720557
J2: B4B-PH-K-S; Connector_B4B-PH-K-S(LF)(SN)
J3, J4, J5, J6: Conn_01x02_Pin; PinHeader_1x02_P2.54mm_Vertical
L1: SRN6045TA-2R2Y; L_Bourns_SRN6045TA; Part Description 3.3µH Semi-Shielded Wirewound Inductor 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
Q1: PMOS_FDC658AP; PMOS_SMD_FDC658AP
R1, R7: 5.6k; R_0402_1005Metric
R2: 10R; R_0402_1005Metric; Part Description Resistor 10R M1005 1% 63mW
R3: 20K 1%; R_0402_1005Metric; Part Description Resistor 20K M1005 1% 63mW
R4: 12K 1%; R_0402_1005Metric; Part Description Resistor 12K M1005 1% 63mW
R5: 2.2K 1%; R_0402_1005Metric; Part Description Resistor 2.2K M1005 1% 63mW
R6: 1.6k; R_0402_1005Metric
R8: 3.6K 1%; R_0402_1005Metric; Part Description Resistor 12K M1005 1% 63mW
R9: 1.5K 1%; R_0402_1005Metric; Part Description Resistor 12K M1005 1% 63mW
R10, R11: 15K 1%; R_0402_1005Metric; Part Description Resistor 12K M1005 1% 63mW
SW1, SW2: SW_SPDT; Switch_SPDT_SMD_Slide_JS102011JCQN
T1: NTCG163JF103FT1; Thermistor_NTC_NTCG163JF103FT1; LCSC C76589
U1: Voltage_Regulator_AP64501
U2: BQ25172DSGR; NiMH_Charger_BQ25172DSGR

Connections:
+5V: C11.1, C12.1, C13.1, C14.1, C15.1, C16.1, D2.2 (A), J2.3, J2.4, J3.2, J4.2, L1.2, R4.1
+12V: C17.1, C19.1, CR1.2, CR2.2, D1.2 (A), D3.2 (A), J1.1, SW1.1 (A), U2.1 (IN)
+BATT: BT6.1, C18.1, C20.1, Q1.1 (D), Q1.2 (D), Q1.5 (D), Q1.6 (D), U2.8 (OUT)
GND: BT1.2, C1.2, C2.2, C3.2, C4.2, C5.2, C6.2, C8.2, C9.2, C10.2, C12.2, C13.2, C14.2, C15.2, C16.2, C17.2, C18.2, C19.2, C20.2, J1.2, J1.3, J2.1, J2.2, J3.1, J4.1, J5.1, J6.1, R1.2, R5.2, R6.2, R8.2, R9.2, R10.2, R11.2, SW1.3 (C), SW2.1 (A), T1.2, U1.7 (GND), U1.9 (EP), U2.4 (GND), U2.9 (EXP), U2.10, U2.11
unnamed: BT1.1, BT2.2
unnamed: BT2.1, BT3.2
unnamed: BT3.1, BT4.2
unnamed: BT4.1, BT5.2
unnamed: BT5.1, BT6.2
unnamed: C7.1, R2.2
unnamed: C10.1, R3.2
unnamed: D1.1 (K), R1.1
unnamed: D2.1 (K), R6.1
unnamed: D3.1 (K), R7.1
unnamed: CR1.1, Q1.3 (G), R11.1
unnamed: SW1.2 (B), U1.3 (EN)
unnamed: SW2.2 (B), U2.3 (TS)
unnamed: SW2.3 (C), T1.1
unnamed: C7.2, U1.1 (BST)
unnamed: C9.1, R3.1, U1.6 (COMP)
unnamed: C11.2, R4.2, R5.1, U1.5 (FB)
unnamed: C8.1, U1.4 (SS)
unnamed: L1.1, R2.1, U1.8 (SW)
unnamed: R9.1, U2.2 (ISET)
unnamed: R7.2, U2.5 (STAT)
unnamed: R10.1, U2.6 (TMR)
unnamed: R8.1, U2.7 (VSET)
VDC: C1.1, C2.1, C3.1, C4.1, C5.1, C6.1, CR2.1, J5.2, J6.2, Q1.4 (S), U1.2 (VIN)

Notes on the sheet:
Timer: 15 kOhm (12 hr)
(output)
K(iset) = 300 I(charge) = K/R(iset) = 200 mA R(iset) = 1.5 kOhms
Pin Headers
The body diode allows voltage from drain to appear on source, making source more + than gate when external power is disconnected... which opens PMOS.
NiMH Charger
Mounting Holes
V(set) = 3.6 kOhm (intermittent) V(set) = 4.7 kOhm
(for 5.5 mm OD, 2.1 mm ID plug)
PST Connector
Trickle charge at C/10 (or C/16?). Rely on timer and temperature to stop charging when reconnected. Shoould charge fully overnight (~12 hours).
Battery Connectors
+5v @ 5A PSU (6 to 12V Input)
For Research and Education ONLY
Barrel Jack
Assume 2000 mAH capacity NiMH cells. 6 cells.
6-12V to 5V Step-Down Switching Regulator

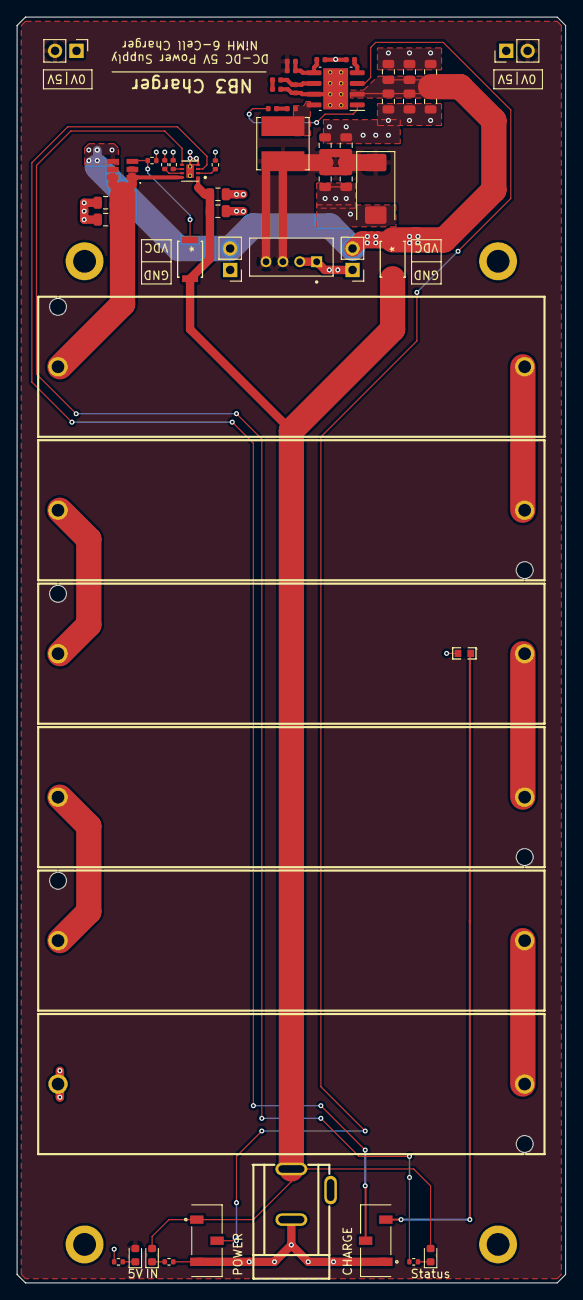
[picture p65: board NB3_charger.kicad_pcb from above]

Board: 2 copper layers, 65.0 x 150.0 mm, 59 parts (0 on the bottom side), 28 nets.

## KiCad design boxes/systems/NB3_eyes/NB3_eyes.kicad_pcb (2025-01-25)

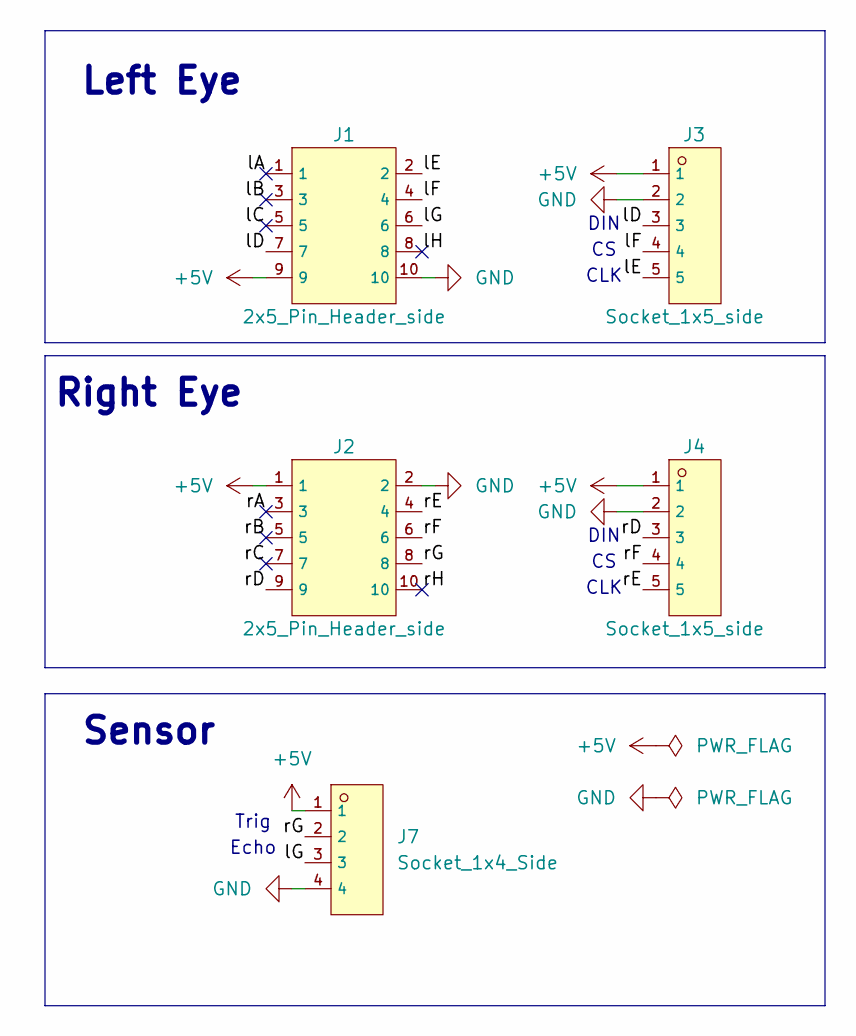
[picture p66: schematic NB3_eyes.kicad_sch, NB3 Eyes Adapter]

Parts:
J1, J2: 2x5_Pin_Header_side; PinHeader_Male_TH_Side_2x5_C60563; LCSC C60563
J3, J4: Socket_1x5_side; SocketHeader_Female_TH_Side_1x5_C2897387; LCSC C2897387
J7: Socket_1x4_Side; SocketHeader_Female_TH_Side_1x4_C5252508; LCSC C5252508

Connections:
+5V: J1.9, J2.1, J3.1, J4.1, J7.1
/lA: J1.1
/lB: J1.3
/lC: J1.5
/lD: J1.7, J3.3
/lE: J1.2, J3.5
/lF: J1.4, J3.4
/lG: J1.6, J7.3
/lH: J1.8
/rA: J2.3
/rB: J2.5
/rC: J2.7
/rD: J2.9, J4.3
/rE: J2.4, J4.5
/rF: J2.6, J4.4
/rG: J2.8, J7.2
/rH: J2.10
GND: J1.10, J2.2, J3.2, J4.2, J7.4

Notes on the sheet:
Trig
DIN
Echo
Right Eye
Sensor
CLK
Left Eye

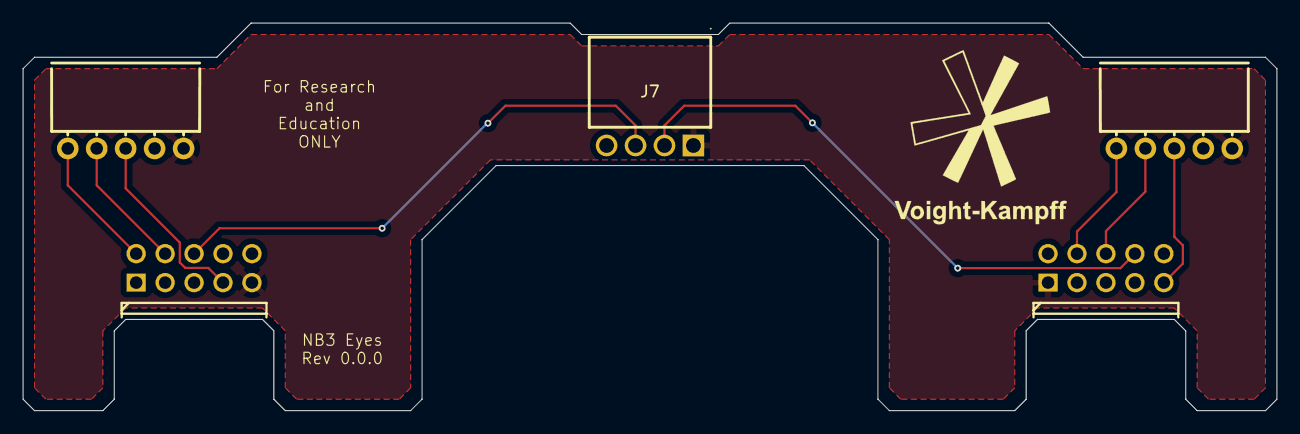
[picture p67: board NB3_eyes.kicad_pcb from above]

Board: 2 copper layers, 110.0 x 34.0 mm, 5 parts (0 on the bottom side), 10 nets.

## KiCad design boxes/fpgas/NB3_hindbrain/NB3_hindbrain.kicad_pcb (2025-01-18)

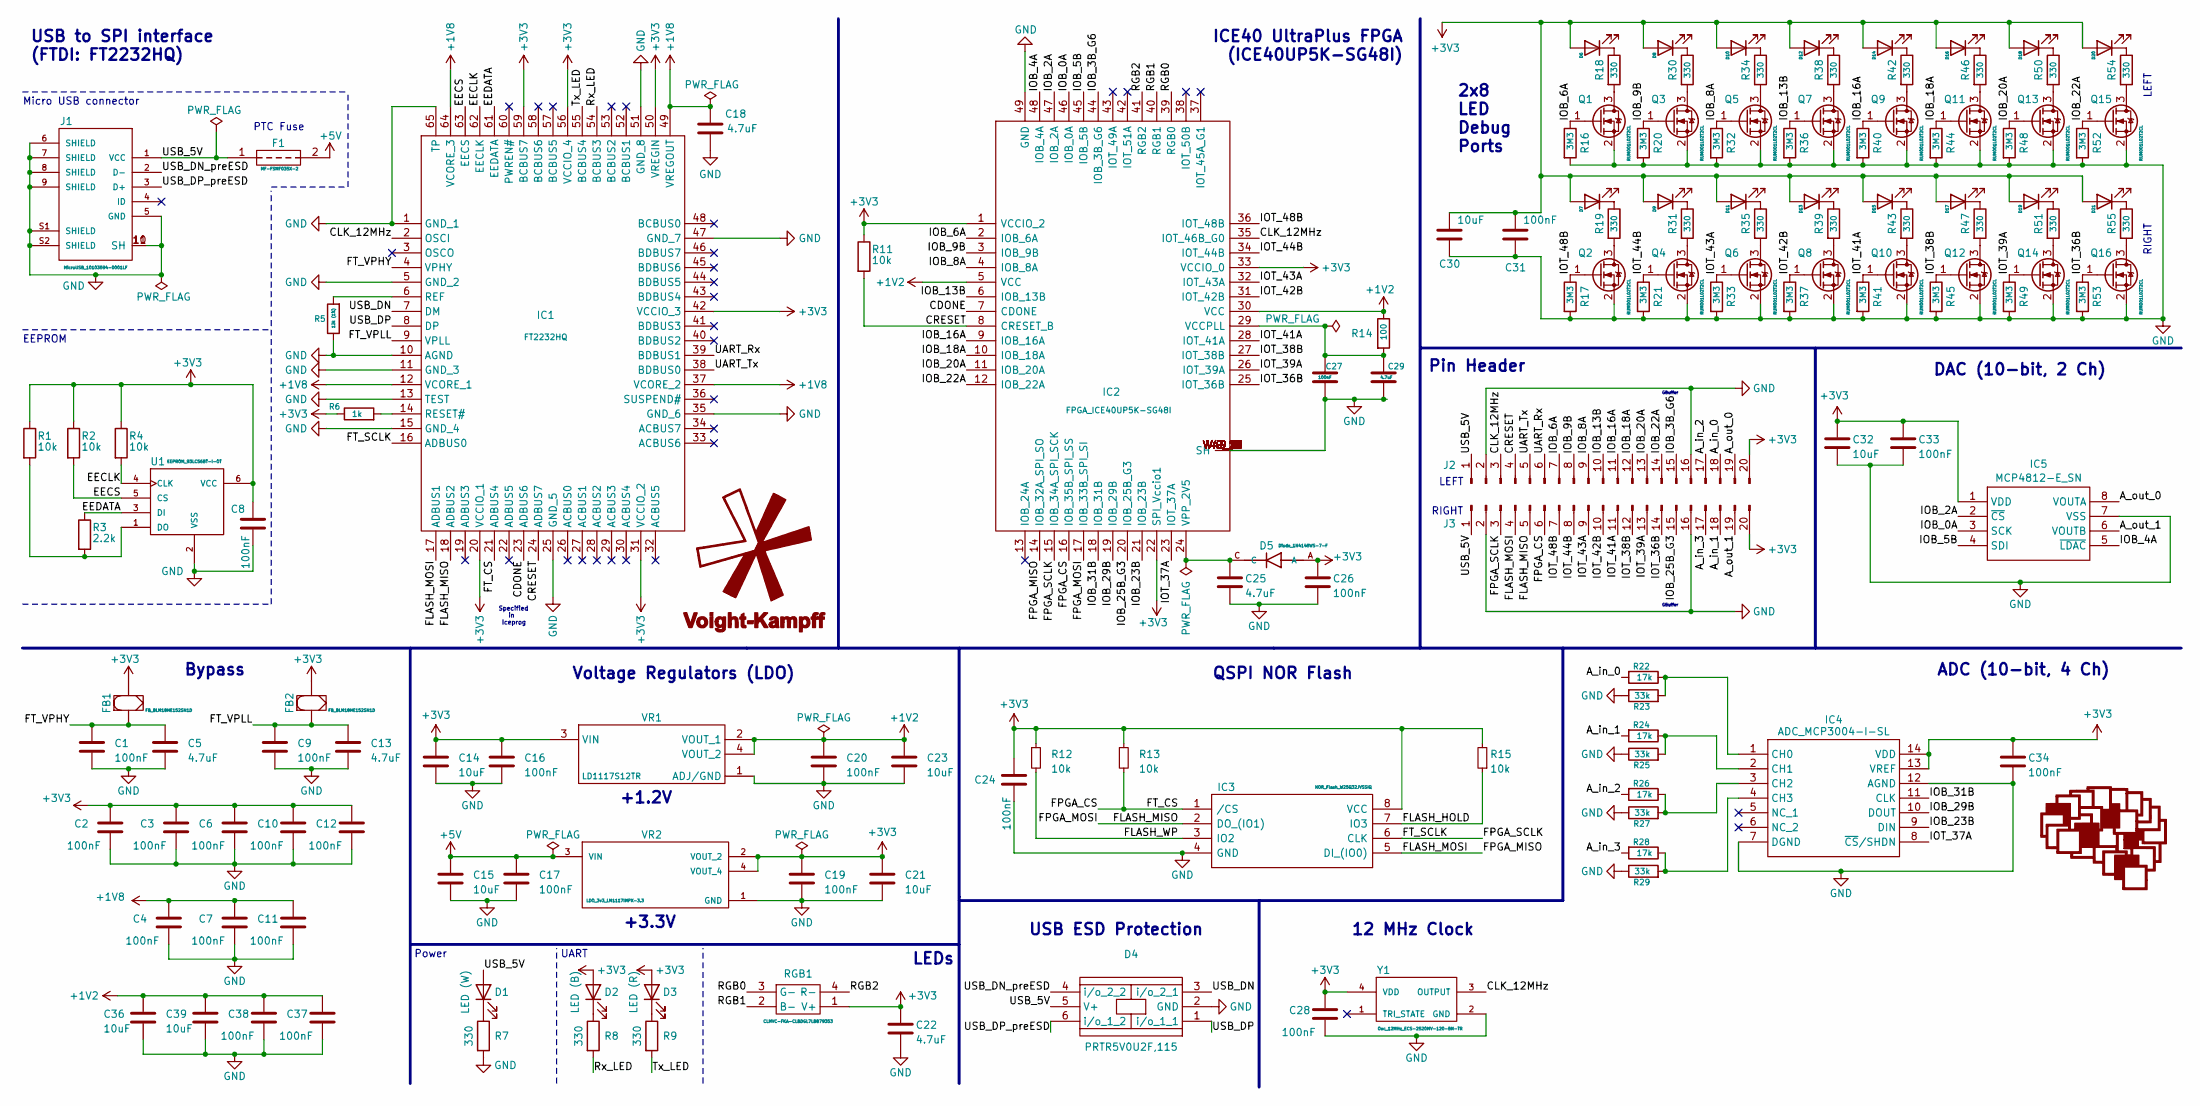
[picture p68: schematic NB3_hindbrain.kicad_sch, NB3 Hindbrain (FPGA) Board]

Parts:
C1, C2, C3, C4, C6, C7, C8, C9, C10, C11, C12, C16, C17, C19, C20, C24, C26, C27, C28, C31, C33, C34, C37, C38: 100nF; C_0402_1005Metric
C5, C13, C18, C22, C25, C29: 4.7uF; C_0603_1608Metric
C14, C15, C21, C23, C30, C32, C36, C39: 10uF; C_0603_1608Metric
D1: LED (W); LED_0402_1005Metric
D2, D6, D8, D10, D12, D14, D16, D18, D20: LED (B); LED_0402_1005Metric
D3, D7, D9, D11, D13, D15, D17, D19, D21: LED (R); LED_0402_1005Metric
D4: PRTR5V0U2F,115; ESD_Diodes_PRTR5V0U2F-115; Mouser Part Number 771-PRTR5V0U2F-T/R
D5: Diode_1N4148WS-7-F
F1: MF-FSMF035X-2; PTC_MF-FSMF035X-2; Mouser Part Number 652-MFFSMF035X-2
FB1, FB2: FB_BLM18HE152SN1D
G1: LOGO; Logo_NBB_5mm
G2: Logo_VK; Logo_VK_5mm
IC1: FT2232HQ; USBtoSerial_FT2232HQ; Mouser Part Number 895-FT2232HQ
IC2: FPGA_ICE40UP5K-SG48I; Manufacturer_Part_Number ICE40UP5K-SG48I; Mouser Part Number 842-ICE40UP5K-SG48I
IC3: NOR_Flash_W25Q32JVSSIQ; Manufacturer_Part_Number W25Q32JVSSIQ; Mouser Part Number 454-W25Q32JVSSIQ
IC4: ADC_MCP3004-I-SL; Mouser Part Number 579-MCP3004-I/SL
IC5: MCP4812-E_SN; DAC_MCP4812-E-SN; Mouser Part Number 579-MCP4812-E/SN
J1: MicroUSB_10103594-0001LF
J2, J3: Conn_01x20_Pin; PinHeader_1x20_P2.54mm_Vertical
Q1, Q2, Q3, Q4, Q5, Q6, Q7, Q8, Q9, Q10, Q11, Q12, Q13, Q14, Q15, Q16: RUM001L02T2CL; MOSFET_Nch_SOT-723_RUM001L02T2CL
R1, R2, R4, R11, R12, R13, R15: 10k; R_0402_1005Metric
R3: 2.2k; R_0402_1005Metric
R5: 12k (1%); R_0402_1005Metric
R6: 1k; R_0402_1005Metric
R7, R8, R9, R18, R19, R30, R31, R34, R35, R38, R39, R42, R43, R46, R47, R50, R51, R54, R55: 330; R_0402_1005Metric
R14: 100; R_0402_1005Metric
R16, R17, R20, R21, R32, R33, R36, R37, R40, R41, R44, R45, R48, R49, R52, R53: 3M3; R_0402_1005Metric
R22, R24, R26, R28: 17k; R_0402_1005Metric
R23, R25, R27, R29: 33k; R_0402_1005Metric
RGB1: CLMVC-FKA-CLBDGL7LBB79353; RGB_CLMVC-FKA-CLBDGL7LBB79353; Mouser Part Number 941-CLMVCFKACLBDGL7L
U1: EEPROM_93LC56BT-I-OT
VR1: LD1117S12TR; LDO_1v2_LD1117S12TR; Mouser Part Number 511-LD1117S12
VR2: LDO_3v3_LM1117IMPX-3.3; PARTREV O
Y1: Osc_12MHz_ECS-2520MV-120-BN-TR

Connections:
+1V2: C20.1, C23.1, C36.1, C37.2, C38.2, C39.1, IC2.5 (VCC), IC2.30 (VCC), R14.1, VR1.2 (VOUT_1), VR1.4 (VOUT_2)
+1V8: C4.2, C7.2, C11.2, C18.1, IC1.12 (VCORE_1), IC1.37 (VCORE_2), IC1.49 (VREGOUT), IC1.64 (VCORE_3)
+3V3: C2.2, C3.2, C6.2, C8.1, C10.2, C12.2, C14.1, C16.1, C19.1, C21.1, C22.1, C24.2, C26.1, C28.2, C30.1, C31.1, C32.1, C33.1, C34.1, D2.2 (A), D3.2 (A), D5.A, D6.2 (A), D7.2 (A), D8.2 (A), D9.2 (A), D10.2 (A), D11.2 (A), D12.2 (A), D13.2 (A), D14.2 (A), D15.2 (A), D16.2 (A), D17.2 (A), D18.2 (A), D19.2 (A), D20.2 (A), D21.2 (A), FB1.2, FB2.2, IC1.20 (VCCIO_1), IC1.31 (VCCIO_2), IC1.42 (VCCIO_3), IC1.50 (VREGIN), IC1.56 (VCCIO_4), IC1.59 (BCBUS7), IC2.1 (VCCIO_2), IC2.22 (SPI_Vccio1), IC2.33 (VCCIO_0), IC3.8 (VCC), IC4.13 (VREF), IC4.14 (VDD), IC5.1 (VDD), J2.20, J3.20, R1.1, R2.1, R4.1, R6.1, R11.1, R12.1, R13.1, R15.2, RGB1.1 (V+), U1.6 (VCC), VR1.3 (VIN), VR2.2 (VOUT_2), VR2.4 (VOUT_4), Y1.4 (VDD)
+5V: C15.1, C17.1, F1.2, VR2.3 (VIN)
/A_in_0: J2.18, R22.2
/A_in_1: J3.18, R24.2
/A_in_2: J2.17, R26.2
/A_in_3: J3.17, R28.2
/A_out_0: IC5.8 (VOUTA), J2.19
/A_out_1: IC5.6 (VOUTB), J3.19
/CDONE: IC1.23 (ADBUS6), IC2.7 (CDONE)
/CLK_12MHz: IC1.2 (OSCI), IC2.35 (IOT_46B_G0), J2.3, Y1.3 (OUTPUT)
/CRESET: IC1.24 (ADBUS7), IC2.8 (CRESET_B), J2.4, R11.2
/EECLK: IC1.62 (EECLK), R4.2, U1.4 (CLK)
/EECS: IC1.63 (EECS), R2.2, U1.5 (CS)
/EEDATA: IC1.61 (EEDATA), R3.1, U1.3 (DI)
/FLASH_HOLD: IC3.7 (IO3), R15.1
/FLASH_MISO: IC1.18 (ADBUS2), IC2.17 (IOB_33B_SPI_SI), IC3.2 (DO_(IO1)), J3.5
/FLASH_MOSI: IC1.17 (ADBUS1), IC2.14 (IOB_32A_SPI_SO), IC3.5 (DI_(IO0)), J3.4
/FLASH_WP: IC3.3 (IO2), R12.2
/FPGA_CS: IC1.21 (ADBUS4), IC2.16 (IOB_35B_SPI_SS), IC3.1 (/CS), J3.6, R13.2
/FPGA_SCLK: IC1.16 (ADBUS0), IC2.15 (IOB_34A_SPI_SCK), IC3.6 (CLK), J3.3
/FT_VPHY: C1.1, C5.1, FB1.1, IC1.4 (VPHY)
/FT_VPLL: C9.1, C13.1, FB2.1, IC1.9 (VPLL)
/IOB_0A: IC2.46 (IOB_0A), IC5.3 (SCK)
/IOB_2A: IC2.47 (IOB_2A), IC5.2 (~CS)
/IOB_3B_G6: IC2.44 (IOB_3B_G6), J2.15
/IOB_4A: IC2.48 (IOB_4A), IC5.5 (~LDAC)
/IOB_5B: IC2.45 (IOB_5B), IC5.4 (SDI)
/IOB_6A: IC2.2 (IOB_6A), J2.7, Q1.1 (G), R16.1
/IOB_8A: IC2.4 (IOB_8A), J2.9, Q5.1 (G), R32.1
/IOB_9B: IC2.3 (IOB_9B), J2.8, Q3.1 (G), R20.1
/IOB_13B: IC2.6 (IOB_13B), J2.10, Q7.1 (G), R36.1
/IOB_16A: IC2.9 (IOB_16A), J2.11, Q9.1 (G), R40.1
/IOB_18A: IC2.10 (IOB_18A), J2.12, Q11.1 (G), R44.1
/IOB_20A: IC2.11 (IOB_20A), J2.13, Q13.1 (G), R48.1
/IOB_22A: IC2.12 (IOB_22A), J2.14, Q15.1 (G), R52.1
/IOB_23B: IC2.21 (IOB_23B), IC4.9 (DIN)
/IOB_25B_G3: IC2.20 (IOB_25B_G3), J3.15
/IOB_29B: IC2.19 (IOB_29B), IC4.10 (DOUT)
/IOB_31B: IC2.18 (IOB_31B), IC4.11 (CLK)
/IOT_36B: IC2.25 (IOT_36B), J3.14, Q16.1 (G), R53.1
/IOT_37A: IC2.23 (IOT_37A), IC4.8 (~CS/SHDN)
/IOT_38B: IC2.27 (IOT_38B), J3.12, Q12.1 (G), R45.1
/IOT_39A: IC2.26 (IOT_39A), J3.13, Q14.1 (G), R49.1
/IOT_41A: IC2.28 (IOT_41A), J3.11, Q10.1 (G), R41.1
/IOT_42B: IC2.31 (IOT_42B), J3.10, Q8.1 (G), R37.1
/IOT_43A: IC2.32 (IOT_43A), J3.9, Q6.1 (G), R33.1
/IOT_44B: IC2.34 (IOT_44B), J3.8, Q4.1 (G), R21.1
/IOT_48B: IC2.36 (IOT_48B), J3.7, Q2.1 (G), R17.1
/RGB0: IC2.39 (RGB0), RGB1.3 (G-)
/RGB1: IC2.40 (RGB1), RGB1.2 (B-)
/RGB2: IC2.41 (RGB2), RGB1.4 (R-)
/Rx_LED: IC1.54 (BCBUS3), R8.2
/Tx_LED: IC1.55 (BCBUS4), R9.2
/UART_Rx: IC1.39 (BDBUS1), J2.6
/UART_Tx: IC1.38 (BDBUS0), J2.5
/USB_5V: D1.2 (A), D4.5 (V+), F1.1, J1.1 (VCC), J2.1, J3.1
/USB_DN: D4.3 (i/o_2_1), IC1.7 (DM)
/USB_DN_preESD: D4.4 (i/o_2_2), J1.2 (D-)
/USB_DP: D4.1 (i/o_1_1), IC1.8 (DP)
/USB_DP_preESD: D4.6 (i/o_1_2), J1.3 (D+)
GND: C1.2, C2.1, C3.1, C4.1, C5.2, C6.1, C7.1, C8.2, C9.2, C10.1, C11.1, C12.1, C13.2, C14.2, C15.2, C16.2, C17.2, C18.2, C19.2, C20.2, C21.2, C22.2, C23.2, C24.1, C25.2, C26.2, C27.2, C28.1, C29.2, C30.2, C31.2, C32.2, C33.2, C34.2, C36.2, C37.1, C38.1, C39.2, D4.2 (GND), IC1.1 (GND_1), IC1.5 (GND_2), IC1.10 (AGND), IC1.11 (GND_3), IC1.13 (TEST), IC1.15 (GND_4), IC1.25 (GND_5), IC1.35 (GND_6), IC1.47 (GND_7), IC1.51 (GND_8), IC1.65 (TP), IC2.49 (GND), IC2.V49_1 (SH), IC2.V49_2 (SH), IC2.V49_3 (SH), IC2.V49_4 (SH), IC2.V49_5 (SH), IC2.V49_6 (SH), IC2.V49_7 (SH), IC2.V49_8 (SH), IC2.V49_9 (SH), IC2.V49_10 (SH), IC2.V49_11 (SH), IC2.V49_12 (SH), IC2.V49_13 (SH), IC2.V49_14 (SH), IC2.V49_15 (SH), IC2.V49_16 (SH), IC2.V49_17 (SH), IC2.V49_18 (SH), IC2.V49_19 (SH), IC2.V49_20 (SH), IC2.V49_21 (SH), IC3.4 (GND), IC4.7 (DGND), IC4.12 (AGND), IC5.7 (VSS), J1.5 (GND), J1.6 (SHIELD), J1.7 (SHIELD), J1.8 (SHIELD), J1.9 (SHIELD), J1.10 (SH), J1.11 (SH), J1.S1 (SHIELD), J1.S2 (SHIELD), J2.2, J2.16, J3.2, J3.16, Q1.2 (S), Q2.2 (S), Q3.2 (S), Q4.2 (S), Q5.2 (S), Q6.2 (S), Q7.2 (S), Q8.2 (S), Q9.2 (S), Q10.2 (S), Q11.2 (S), Q12.2 (S), Q13.2 (S), Q14.2 (S), Q15.2 (S), Q16.2 (S), R5.1, R7.2, R16.2, R17.2, R20.2, R21.2, R23.1, R25.1, R27.1, R29.1, R32.2, R33.2, R36.2, R37.2, R40.2, R41.2, R44.2, R45.2, R48.2, R49.2, R52.2, R53.2, U1.2 (VSS), VR1.1 (ADJ/GND), VR2.1 (GND), Y1.2 (GND)
unnamed: D1.1 (K), R7.1
unnamed: D2.1 (K), R8.1
unnamed: D3.1 (K), R9.1
unnamed: D6.1 (K), R18.1
unnamed: D7.1 (K), R19.1
unnamed: D8.1 (K), R30.1
unnamed: D9.1 (K), R31.1
unnamed: D10.1 (K), R34.1
unnamed: D11.1 (K), R35.1
unnamed: D12.1 (K), R38.1
unnamed: D13.1 (K), R39.1
unnamed: D14.1 (K), R42.1
unnamed: D15.1 (K), R43.1
unnamed: D16.1 (K), R46.1
unnamed: D17.1 (K), R47.1
unnamed: D18.1 (K), R50.1
unnamed: D19.1 (K), R51.1
unnamed: D20.1 (K), R54.1
unnamed: D21.1 (K), R55.1
unnamed: IC1.6 (REF), R5.2
unnamed: IC1.14 (RESET#), R6.2
unnamed: C27.1, C29.1, IC2.29 (VCCPLL), R14.2
unnamed: C25.1, D5.C, IC2.24 (VPP_2V5)
unnamed: IC4.1 (CH0), R22.1, R23.2
unnamed: IC4.2 (CH1), R24.1, R25.2
unnamed: IC4.3 (CH2), R26.1, R27.2
unnamed: IC4.4 (CH3), R28.1, R29.2
unnamed: Q1.3 (D), R18.2
unnamed: Q2.3 (D), R19.2
unnamed: Q3.3 (D), R30.2
unnamed: Q4.3 (D), R31.2
unnamed: Q5.3 (D), R34.2
unnamed: Q6.3 (D), R35.2
unnamed: Q7.3 (D), R38.2
unnamed: Q8.3 (D), R39.2
unnamed: Q9.3 (D), R42.2
unnamed: Q10.3 (D), R43.2
unnamed: Q11.3 (D), R46.2
unnamed: Q12.3 (D), R47.2
unnamed: Q13.3 (D), R50.2
unnamed: Q14.3 (D), R51.2
unnamed: Q15.3 (D), R54.2
unnamed: Q16.3 (D), R55.2
unnamed: R1.2, R3.2, U1.1 (DO)

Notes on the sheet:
12 MHz Clock
LEFT
+1.2V
Power
ICE40 UltraPlus FPGA (ICE40UP5K-SG48I)
GBuffer
Pin Header
DAC (10-bit, 2 Ch)
PTC Fuse
UART
Specified in Iceprog
Micro USB connector
RIGHT
Voltage Regulators (LDO)
+3.3V
2x8 LED Debug Ports
LEDs
QSPI NOR Flash
Bypass
EEPROM
USB to SPI interface (FTDI: FT2232HQ)
USB ESD Protection
ADC (10-bit, 4 Ch)

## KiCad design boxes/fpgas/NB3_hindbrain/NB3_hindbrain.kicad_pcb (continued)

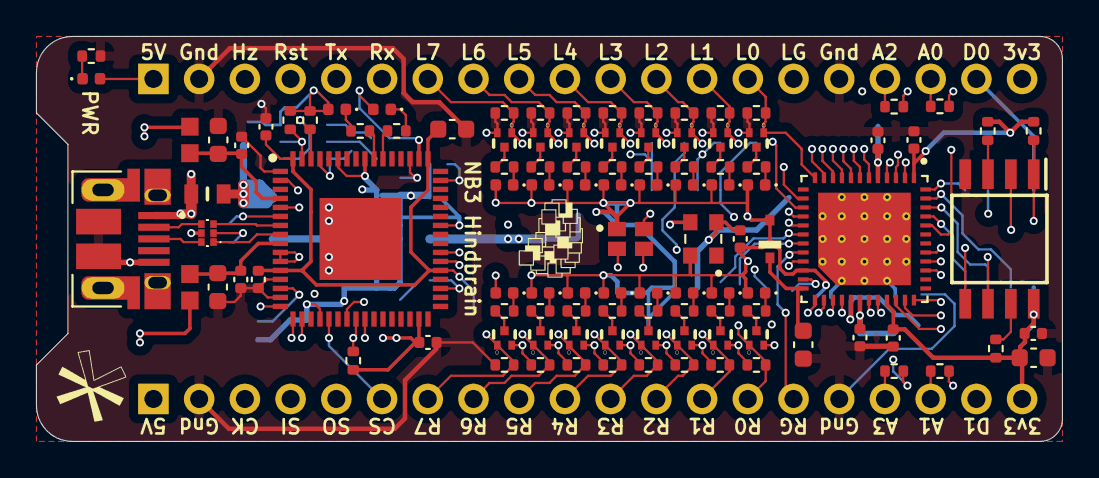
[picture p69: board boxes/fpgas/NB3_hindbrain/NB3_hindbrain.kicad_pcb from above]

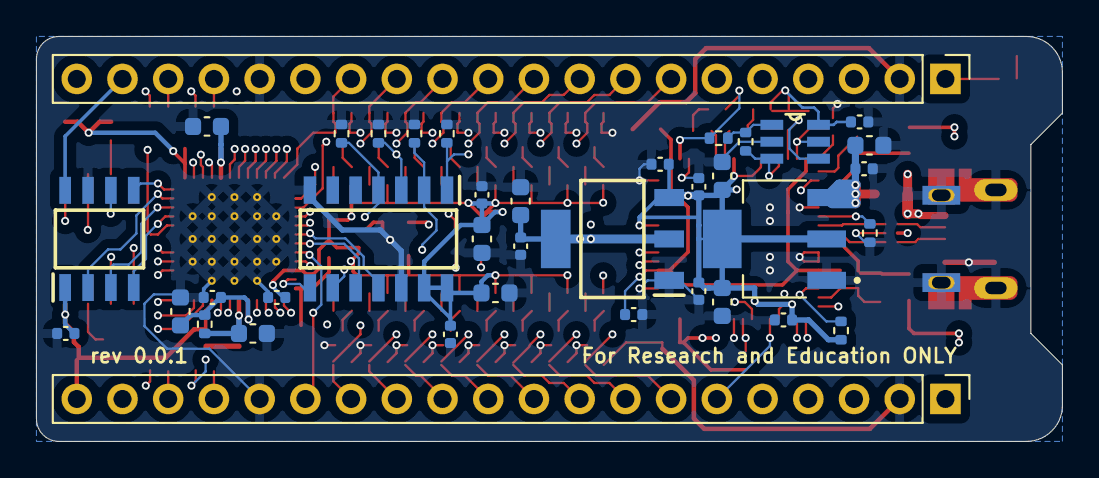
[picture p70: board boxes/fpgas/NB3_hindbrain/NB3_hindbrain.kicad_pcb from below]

Board: 4 copper layers, 57.0 x 22.5 mm, 147 parts (38 on the bottom side), 107 nets.

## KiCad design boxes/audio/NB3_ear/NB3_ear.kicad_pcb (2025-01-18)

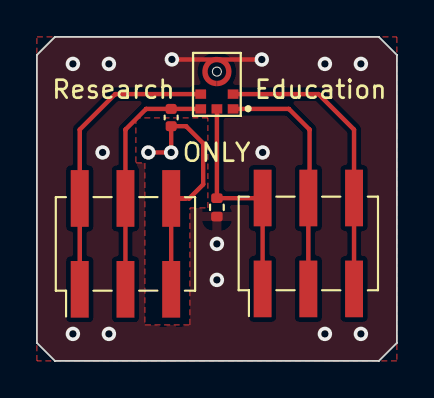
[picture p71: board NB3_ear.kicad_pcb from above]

Board: 2 copper layers, 20.0 x 18.0 mm, 5 parts (0 on the bottom side), 6 nets.

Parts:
C1: 0.1 uF; C_0402_1005Metric
J1, J2: Conn_02x03_Odd_Even; PinHeader_2x03_P2.54mm_Vertical_SMD
MK1: Mic_ICS-43434
R1: 100k; R_0402_1005Metric

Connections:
+3.3V: C1.1, J1.3, J1.4, MK1.5 (VDD)
/LR: J2.5, J2.6, MK1.2 (LR)
/SCK: J1.1, J1.2, MK1.4 (SCK)
/SD: J2.1, J2.2, MK1.6 (SD), R1.2
/WS: J2.3, J2.4, MK1.1 (WS)
GND: C1.2, J1.5, J1.6, R1.1

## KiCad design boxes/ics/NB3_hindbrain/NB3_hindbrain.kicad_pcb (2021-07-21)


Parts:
C1, C2, C3, C4, C6, C7, C8, C9, C10, C11, C12, C16, C17, C19, C20, C23, C24, C26, C28: 100nF; C_0402_1005Metric
C5, C13, C25, C27: 4.7uF; C_0603_1608Metric
C14, C15, C21, C22: 10uF; C_0603_1608Metric
C18: 3.3uF; C_0603_1608Metric
D1, D2: LED; LED_0603_1608Metric
D3: Diode_1N4148WS-7-F
FB1, FB2: FB_BLM18HE152SN1D
IC1: FPGA_ICE40UP5K-SG48I; Manufacturer_Part_Number ICE40UP5K-SG48I; Mouser Part Number 842-ICE40UP5K-SG48I
IC2: NOR_Flash_W25Q32JVSSIQ; Manufacturer_Part_Number W25Q32JVSSIQ; Mouser Part Number 454-W25Q32JVSSIQ
J1: MicroUSB_10103594-0001LF
J2, J3: Conn_01x20_Male; PinHeader_1x20_P2.54mm_Vertical
R1, R2, R4, R6, R11, R12, R14: 10k; R_0402_1005Metric
R3: 2.2k; R_0402_1005Metric
R5: 4.7k; R_0402_1005Metric
R7: 1k; R_0402_1005Metric
R8, R10: 150; R_0402_1005Metric
R9: 12k; R_0402_1005Metric
R13: 100; R_0402_1005Metric
U1: EEPROM_93LC56BT-I-OT
VR1: LDO_3v3_LM1117IMPX-3.3; PARTREV O
VR2: LDO_1v2_AP7217D-12YG-13; Manufacturer_Part_Number AP7217D-12YG-13; Mouser Part Number 621-AP7217D-12YG-13
Y1: Osc_12MHz_ECS-2520MV-120-BN-TR

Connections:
+1V2: C19.1, C21.1, IC1.5 (VCC), IC1.30 (VCC), R13.1, VR2.3 (VOUT)
+1V8: C4.2, C8.2, C11.2, C18.2; also elsewhere on the board
+3V3: C2.2, C3.2, C6.2, C7.1, C10.2, C12.2, C15.1, C17.1, C20.1, C22.1, C23.2, C25.1, C28.2, D3.A, FB1.2, FB2.2, IC1.1 (VCCIO_2), IC1.22 (SPI_Vccio1), IC1.33 (VCCIO_0), IC2.8 (VCC), J3.20, R1.1, R2.1, R4.1, R11.1, R12.1, R14.2, U1.6 (VCC), VR1.2 (VOUT_2), VR1.4 (VOUT_4), VR2.2 (VIN_1), VR2.4 (VIN_2), Y1.4 (VDD); also elsewhere on the board
/CDONE: IC1.7 (CDONE); also elsewhere on the board
/CLK_12MHz: Y1.3 (OUTPUT); also elsewhere on the board
/CRESET_B: IC1.8 (CRESET_B); also elsewhere on the board
/EECLK: R1.2, U1.4 (CLK); also elsewhere on the board
/EECS: R4.2, U1.5 (CS); also elsewhere on the board
/EEDATA_I: R3.2, U1.3 (DI); also elsewhere on the board
/EEDATA_O: R2.2, R3.1, U1.1 (DO)
/FLASH_HOLDn: IC2.7 (IO3), R14.1; also elsewhere on the board
/FLASH_SCK: IC1.15 (IOB_34A_SPI_SCK), IC2.6 (CLK); also elsewhere on the board
/FLASH_SI: IC1.14 (IOB_32A_SPI_SO), IC2.5 (DI_(IO0)); also elsewhere on the board
/FLASH_SO: IC1.17 (IOB_33B_SPI_SI), IC2.2 (DO_(IO1)); also elsewhere on the board
/FLASH_SSn: IC1.16 (IOB_35B_SPI_SS), IC2.1 (/CS), R12.2; also elsewhere on the board
/FLASH_WPn: IC2.3 (IO2), R11.2
/FT_VPHY: C1.1, C5.1, FB2.1; also elsewhere on the board
/FT_VPLL: C9.1, C13.1, FB1.1; also elsewhere on the board
/IOB_0A: IC1.46 (IOB_0A), J2.4
/IOB_2A: IC1.47 (IOB_2A), J2.5
/IOB_3B_G6: IC1.44 (IOB_3B_G6), J2.2
/IOB_4A: IC1.48 (IOB_4A), J2.6
/IOB_5B: IC1.45 (IOB_5B), J2.3
/IOB_6A: IC1.2 (IOB_6A), J2.7
/IOB_8A: IC1.4 (IOB_8A), J2.9
/IOB_9B: IC1.3 (IOB_9B), J2.8
/IOB_13B: IC1.6 (IOB_13B), J2.10
/IOB_16A: IC1.9 (IOB_16A), J2.11
/IOB_18A: IC1.10 (IOB_18A), J2.12
/IOB_20A: IC1.11 (IOB_20A), J2.13
/IOB_22A: IC1.12 (IOB_22A), J2.14
/IOB_23B: IC1.21 (IOB_23B), J2.19
/IOB_24A: IC1.13 (IOB_24A), J2.15
/IOB_25B_G3: IC1.20 (IOB_25B_G3), J2.18
/IOB_29B: IC1.19 (IOB_29B), J2.17
/IOB_31B: IC1.18 (IOB_31B), J2.16
/IOT_36B: IC1.25 (IOT_36B), J3.7
/IOT_37A: IC1.23 (IOT_37A), J3.6
/IOT_38B: IC1.27 (IOT_38B), J3.9
/IOT_39A: IC1.26 (IOT_39A), J3.8
/IOT_41A: IC1.28 (IOT_41A), J3.10
/IOT_42B: IC1.31 (IOT_42B), J3.11
/IOT_43A: IC1.32 (IOT_43A), J3.12
/IOT_44B: IC1.34 (IOT_44B), J3.13
/IOT_45A_G1: IC1.37 (IOT_45A_G1), J3.16
/IOT_46B_G0: IC1.35 (IOT_46B_G0), J3.14
/IOT_48B: IC1.36 (IOT_48B), J3.15
/IOT_49A: IC1.43 (IOT_49A), J3.19
/IOT_50B: IC1.38 (IOT_50B), J3.17
/IOT_51A: IC1.42 (IOT_51A), J3.18
/RGB0: IC1.39 (RGB0), J3.5
/RGB1: IC1.40 (RGB1), J3.4
/RGB2: IC1.41 (RGB2), J3.3
/USB_DN: J1.2 (D-); also elsewhere on the board
/USB_DP: J1.3 (D+); also elsewhere on the board
GND: C1.2, C2.1, C3.1, C4.1, C5.2, C6.1, C7.2, C8.1, C9.2, C10.1, C11.1, C12.1, C13.2, C14.2, C15.2, C16.2, C17.2, C18.1, C19.2, C20.2, C21.2, C22.2, C23.1, C24.2, C25.2, C26.2, C27.2, C28.1, IC1.49 (GND), IC2.4 (GND), J1.5 (GND), J1.6 (SHIELD), J1.7 (SHIELD), J1.8 (SHIELD), J1.9 (SHIELD), J1.S1 (SHIELD), J1.S2 (SHIELD), J2.1, J2.20, R6.2, R8.2, R9.2, R10.2, U1.2 (VSS), VR1.1 (GND), VR2.1 (GND), Y1.2 (GND); also elsewhere on the board
unnamed: C24.1, D3.C, IC1.24 (VPP_2V5)
unnamed: C26.1, C27.1, IC1.29 (VCCPLL), R13.2
unnamed: D1.1 (K), R8.1
unnamed: D2.1 (K), R10.1
unnamed: R5.2, R6.1, R7.1
unnamed 61: R7.2; also elsewhere on the board
unnamed 62: R9.1; also elsewhere on the board

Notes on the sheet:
EEPROM
USB to SPI interface (FTDI: FT4232H)
Micro USB connector
Bypass
LEDs
Voltage Regulators (LDO) +1.2V +3.3V
QSPI NOR Flash (W25Q32JVSSIQ)
ICE40 UltraPlus FPGA (ICE40UP5K-SG48I)
Pin Header
12 MHz Clock

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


Board: 4 copper layers, 57.0 x 22.0 mm, 57 parts (26 on the bottom side), 65 nets.

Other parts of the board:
U2: USBtoSPI_FT4232HL

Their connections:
+1V8: U2.12 (VCORE), U2.37 (VCORE), U2.49 (VREGOUT), U2.64 (VCORE); also elsewhere on the board
+3V3: U2.20 (VCCIO), U2.31 (VCCIO), U2.42 (VCCIO), U2.50 (VREGIN), U2.56 (VCCIO); also elsewhere on the board
/CDONE: U2.23 (ADBUS6), U2.33 (BDBUS6); also elsewhere on the board
/CLK_12MHz: U2.2 (OSCI); also elsewhere on the board
/CRESET_B: U2.24 (ADBUS7), U2.34 (BDBUS7); also elsewhere on the board
/EECLK: U2.62 (EECLK); also elsewhere on the board
/EECS: U2.63 (EECS); also elsewhere on the board
/EEDATA_I: U2.61 (EEDATA); also elsewhere on the board
/FLASH_HOLDn: U2.32 (BDBUS5); also elsewhere on the board
/FLASH_SCK: U2.16 (ADBUS0), U2.26 (BDBUS0); also elsewhere on the board
/FLASH_SI: U2.17 (ADBUS1), U2.28 (BDBUS2); also elsewhere on the board
/FLASH_SO: U2.18 (ADBUS2), U2.27 (BDBUS1); also elsewhere on the board
/FLASH_SSn: U2.21 (ADBUS4), U2.30 (BDBUS4); also elsewhere on the board
/FT_VPHY: U2.4 (VPHY); also elsewhere on the board
/FT_VPLL: U2.9 (VPLL); also elsewhere on the board
/USB_DN: U2.7 (DM); also elsewhere on the board
/USB_DP: U2.8 (DP); also elsewhere on the board
GND: U2.1 (GND), U2.5 (GND), U2.10 (AGND), U2.11 (GND), U2.13 (TEST), U2.15 (GND), U2.25 (GND), U2.35 (GND), U2.47 (GND), U2.51 (GND); also elsewhere on the board
unnamed 61: U2.14 (~RESET#); also elsewhere on the board
unnamed 62: U2.6 (REF); also elsewhere on the board

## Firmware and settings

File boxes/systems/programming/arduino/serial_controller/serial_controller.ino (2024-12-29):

/*
  Serial Controller
*/

// Globals
int pin_left_PWM = 9;
int pin_left_A = 2;
int pin_left_B = 3;
int pin_right_PWM = 10;
int pin_right_A = 4;
int pin_right_B = 5;

void setup() {
  // Initialize serial port
  Serial.begin(115200);

  // LED Feedback
  pinMode(LED_BUILTIN, OUTPUT);

  // Left Motor Digital Outputs
  pinMode(pin_left_PWM, OUTPUT);  // PWM
  pinMode(pin_left_A, OUTPUT);    // A
  pinMode(pin_left_B, OUTPUT);    // B

  // Right Motor Digital Outputs
  pinMode(pin_right_PWM, OUTPUT);  // PWM
  pinMode(pin_right_A, OUTPUT);    // A
  pinMode(pin_right_B, OUTPUT);    // B

  // Initialize
  digitalWrite(pin_left_PWM, LOW);
  digitalWrite(pin_left_A, LOW);
  digitalWrite(pin_left_B, LOW);
  digitalWrite(pin_right_PWM, LOW);
  digitalWrite(pin_right_A, LOW);
  digitalWrite(pin_right_B, LOW);
}

void loop() {
  
  // Check for any incoming bytes
  if (Serial.available() > 0) {
    char newChar = Serial.read();

    // Respond to command "f"
    if(newChar == 'f') {
      forward();
    }

    // Respond to command "b"
    if(newChar == 'b') {
      backward();
    }

    // Respond to command "l"
    if(newChar == 'l') {
      left();
    }

    // Respond to command "r"
    if(newChar == 'r') {
      right();
    }

    // Respond to command "x"
    if(newChar == 'x') {
      stop();
    }
  }

  // Wait a bit
  delay(10);
}

// Go
void go()
{
  digitalWrite(LED_BUILTIN, HIGH);
  digitalWrite(pin_left_PWM, HIGH);
  digitalWrite(pin_right_PWM, HIGH);
}

// Stop
void stop()
{
  digitalWrite(LED_BUILTIN, LOW);
  digitalWrite(pin_left_PWM, LOW);
  digitalWrite(pin_left_A, LOW);
  digitalWrite(pin_left_B, LOW);
  digitalWrite(pin_right_PWM, LOW);
  digitalWrite(pin_right_A, LOW);
  digitalWrite(pin_right_B, LOW);
}

// Forward
void forward()
{
  // Left motor
  digitalWrite(pin_left_A, HIGH);
  digitalWrite(pin_left_B, LOW);
  
  // Right motor
  digitalWrite(pin_right_A, HIGH);
  digitalWrite(pin_right_B, LOW);

  // Move
  go();
}

// Backward
void backward()
{
  // Left motor
  digitalWrite(pin_left_A, LOW);
  digitalWrite(pin_left_B, HIGH);
  
  // Right motor
  digitalWrite(pin_right_A, LOW);
  digitalWrite(pin_right_B, HIGH);

  // Move
  go();
}

// Left
void left()
{
  // Left motor
  digitalWrite(pin_left_A, LOW);
  digitalWrite(pin_left_B, HIGH);
  
  // Right motor
  digitalWrite(pin_right_A, HIGH);
  digitalWrite(pin_right_B, LOW);

  // Move
  go();
}

// Right
void right()
{
  // Left motor
  digitalWrite(pin_left_A, HIGH);
  digitalWrite(pin_left_B, LOW);
  
  // Right motor
  digitalWrite(pin_right_A, LOW);
  digitalWrite(pin_right_B, HIGH);

  // Move
  go();
}

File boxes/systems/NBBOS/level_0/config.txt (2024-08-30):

core_freq_min=500
uart_2ndstage=1

[pi4]
kernel=kernel8.img

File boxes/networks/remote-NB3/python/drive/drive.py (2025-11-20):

# Requires installing sshkeyboard: pip install sshkeyboard
import os
import serial
import time
from sshkeyboard import listen_keyboard

# Turn off key echo
os.system("stty -echo")

# Specify global states
quit = False
moving = False

# Open serial port
ser = serial.Serial(port='/dev/ttyUSB0', baudrate=115200)
time.sleep(2.00) # Wait for connection before sending any data

# Start key listening thread
def press(key):
    global quit
    global moving

    # Quit?
    if key == "q":
        print("\rQuiting                  ", end="", flush=True)
        ser.write(b'x')
        moving = False
        quit = True
        time.sleep(0.05)
        return False

    # Stopped?
    if not moving:
        # Forward?
        if key == "up":
            print("\rForward (press \'q\') to quit           ", end="", flush=True)
            ser.write(b'f')
            moving = True
            time.sleep(0.05)
        # Backward?
        if key == "down":
            print("\rBackward (press \'q\') to quit           ", end="", flush=True)
            ser.write(b'b')
            moving = True
            time.sleep(0.05)
        # Left?
        if key == "left":
            print("\rLeft (press \'q\') to quit           ", end="", flush=True)
            ser.write(b'l')
            moving = True
            time.sleep(0.05)
        # Right?
        if key == "right":
            print("\rRight (press \'q\') to quit           ", end="", flush=True)
            ser.write(b'r')
            moving = True
            time.sleep(0.05)
    return True
        
def release(key):
    global moving
    if (key == "up") or (key == "down") or (key == "left") or (key == "right"):
        print("\rStopped (press \'q\') to quit           ", end="", flush=True)
        ser.write(b'x')
        moving = False
        time.sleep(0.05)
    return True

# Listen for keyboard events
listen_keyboard(on_press=press, on_release=release, delay_second_char=0.10, until="q")

# Turn on key echo
os.system("stty echo")
print()

# Close serial port
ser.close()

#FIN

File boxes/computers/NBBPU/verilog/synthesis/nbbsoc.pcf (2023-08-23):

# The LED pins are on dedicated pins and cannot be modified!
# Note that they are negative logic (write a 0 to turn on).
# These are also brought out to the left side of the board. 
# Cut the board trace on jumper R28 to disable the onboard 3 color LED.
#set_io -nowarn led_green 39
#set_io -nowarn led_red	41
#set_io -nowarn led_blue 40
set_io -nowarn RGB[2]	41
set_io -nowarn RGB[1]	39
set_io -nowarn RGB[0]	40

# FTDI chip interface
set_io -nowarn serial_txd 14 # FPGA transmit to USB
set_io -nowarn serial_rxd 15 # FPGA receive from USB
set_io -nowarn spi_cs 16 # Connected to SPI flash, drive high unless using SPI flash!

# If using the FTDI MPSSE engine, the following signals apply
set_io -nowarn spi_sck 15  # Shared with the flash
set_io -nowarn spi_ssn 16  # Connected to SPI flash, drive high unless using SPI flash!
set_io -nowarn spi_mosi 17 # Shared with the flash
set_io -nowarn spi_miso 14 # Shared with the flash

# Normal GPIO pins, left side
set_io -nowarn gpio_23 23
set_io -nowarn gpio_25 25
set_io -nowarn gpio_26 26
set_io -nowarn gpio_27 27
set_io -nowarn gpio_32 32
set_io -nowarn gpio_35 35
set_io -nowarn gpio_31 31
set_io -nowarn gpio_37 37
set_io -nowarn gpio_34 34
set_io -nowarn gpio_43 43
set_io ADC_control[2] 36    # ADC reset (active low)
set_io ADC_control[0] 42    # ADC control signal (D_in)
set_io ADC_data 38          # ADC data (D_out)
set_io ADC_control[1] 28    # ADC sample clock

# Normal GPIO pins, right side

# Following pins are added on the v3.0 of the board.
# SPI pins are brought out to the right side of the board

# Note: On board 12MHz clock can be brought to IOB_25B_G3 (pin 20) which is a global
# clock input. Short across R16 (labelled OSC on the board) to enable 12MHz clock to
# pin 20.
set_io -nowarn clock 20
set_io -nowarn reset 12

# Following are also found on v2.x of the UPduino
#set_io -nowarn gpio_12 12
set_io -nowarn gpio_21 21
set_io -nowarn gpio_13 13
set_io -nowarn gpio_19 19
set_io -nowarn gpio_18 18
set_io -nowarn gpio_11 11
set_io -nowarn gpio_9 9
set_io -nowarn gpio_6 6
set_io -nowarn gpio_44 44
set_io -nowarn gpio_4 4
set_io -nowarn gpio_3 3
set_io -nowarn gpio_48 48
set_io -nowarn gpio_45 45
set_io -nowarn gpio_47 47
set_io -nowarn gpio_46 46
set_io -nowarn gpio_2 2

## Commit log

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2020-07-13 Converted BOM to csv
    [BOM.csv]
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2020-08-29 Switch to custom server (from GH-pages/Jekyll)
    [BOM.csv]
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2020-08-30 Update _template box, add White box
    [materials.csv]
2020-08-30 Added "materials.csv" to each box, for auto-BOM
    [BOM.csv, materials.csv]
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2020-08-31 Remove search refs from links
    [materials.csv]
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2020-09-04 Added "hearing" box, amongst other tweaks
    [BOM.csv, cut.dxf, cut_logo.dxf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]
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2020-09-07 Add mouning hardware to BOM
    [materials.csv]
2020-09-07 More additions to BOM
    [BOM.csv, materials.csv]
2020-09-09 Split large boxes (e.g. electrons)
    [BOM.csv, materials.csv]
2020-09-09 Add content for data
    [BOM.csv, materials.csv]
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2020-09-10 Add 2019 content, unorganized
    [picam_holder.stl]
2020-09-10 Add words and images to memory box
    [BOM.csv, materials.csv]
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2020-09-10 Update decisions with comparator BOM
    [BOM.csv, materials.csv]
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2020-09-10 Distinguish LBBROOT from LBBREPO
    [BOM.csv]
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2020-09-14 Fix datasheet links (issue)
    [BOM.csv, materials.csv]
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2020-09-18 Update BOM (digital boxes)
    [BOM.csv, materials.csv]
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2020-11-12 Draft for NB3 power board PCB
    [NB3_power.kicad_pcb, NB3_power.kicad_sch, materials.csv]
2020-11-13 Work on NB3_power PCB
    [NB3_power.kicad_pcb, NB3_power.kicad_sch]
2020-11-13 More work on NB3_power PCB
    [NB3_power.kicad_pcb, NB3_power.kicad_sch]
2020-11-16 Work on NB3_power PCB (layout)
    [NB3_power.kicad_pcb, NB3_power.kicad_sch]
2020-11-17 More work on NB£_power PCB
    [NB3_power.kicad_pcb, NB3_power.kicad_sch]
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2020-11-18 NB3_power PCB layout finished
    [NB3_power.csv, NB3_power.kicad_pcb, NB3_power.kicad_sch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]
2020-11-18 NB3_power PCB fab submisson
    [NB3_power.csv, NB3_power.kicad_pcb, NB3_power.kicad_sch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]
2021-06-25 Added new NB3 board drafts (body and power)
    [NB3_body.kicad_pcb, NB3_body.kicad_sch, NB3_body.ods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]
2021-06-28 Final draft (rev 0.0.1) of NB3_power PCB
    [NB3_power.csv, NB3_power.kicad_pcb, NB3_power.kicad_sch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]
2021-06-28 Work on NB3_body PCB...
    [NB3_body.dxf, NB3_body.kicad_pcb, NB3_body.kicad_sch]
2021-06-29 Optimized NB3_power BOM for cost
    [NB3_power-B_Cu.gbl, NB3_power-B_Mask.gbs, NB3_power-B_Paste.gbp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]
2021-06-30 Work on NB£_body PCB layout
    [NB3_body.kicad_pcb, NB3_body.kicad_sch]
2021-06-30 Work on NB3_body routing
    [NB3_body.kicad_pcb, NB3_body.kicad_sch]
2021-07-02 NB3 pcb design tweaks
    [NB3_body.kicad_pcb, NB3_body.kicad_sch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]
2021-07-05 Added laser cut (DXF) designs for NB3 mounts
    [NB3_camera_mount.dxf, NB3_npu_mount.dxf, NB3_spacer.dxf]
2021-07-06 Work on NB£_body PCB
    [NB3_body.kicad_pcb, NB3_body.kicad_sch]
2021-07-06 Finished NB3_body PCB (pre-Fab)
    [NB3_body-B_Cu.gbl, NB3_body-B_Mask.gbs, NB3_body-B_Paste.gbp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]
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2021-07-06 Draft design for NB3 Ear PCB
    [NB3_ear.kicad_pcb, NB3_ear.kicad_sch]
2021-07-07 Added NB3 Ear PCB design
    [NB3_body.kicad_pcb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]
2021-07-12 FPGA hindbrain PCB draft
    [NB3_ear-B_Cu.gbl, NB3_ear-B_Mask.gbs, NB3_ear-B_Paste.gbp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]
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2021-09-22 Changed "?" box name for lame windows users
    [materials.csv]
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2022-08-02 Updated NB3_power: compatible w/replacement PS
    [NB3_power.kicad_pcb, NB3_power.kicad_sch]
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2022-10-06 Updated Fab details for NB3 power (rev 3)
    [NB3_body-B_Cu.dxf, NB3_body-B_Mask.dxf, NB3_body-B_Paste.dxf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]
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2023-08-05 Revert to box "FPGAs" vs "ICs"
    [NB3_hindbrain.kicad_pcb, NB3_hindbrain.kicad_sch, materials.csv]
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2023-08-12 Work on NB3_bidy (v4) - TT DC motors
    [NB3_body.kicad_pcb, NB3_body.kicad_sch]
2023-08-13 Updated NB3 body (v4) - ear/mouth and TT motors
    [NB3_body-B_Cu.dxf, NB3_body-B_Mask.dxf, NB3_body-B_Paste.dxf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]
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2023-08-30 Fix DRC fill in NB3_hindbrain
    [NB3_hindbrain-B_Cu.gbl, NB3_hindbrain-B_Mask.gbs, NB3_hindbrain-B_Paste.gbp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]
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2023-09-02 Update NB3_Body (fix right ear orientation)
    [NB3_body.kicad_pcb, NB3_body.kicad_sch]
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2024-06-10 Work on animation (compat with Firefox/Chrome issue)
    [animation_parameters_position_hover.csv]
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2024-07-16 Bug note in audio wiring
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2024-09-30 Remove LBB site draft. Course taught via Github/Discord
    [animation_parameters_badge.csv, box_parameters_badge.csv]
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2024-10-02 Update NB3 mouth for better panelization (rev 3)
    [NB3_mouth.kicad_pcb, NB3_mouth.kicad_sch]
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2024-11-09 Large refactor (lessons go into each box, includes video description)
    [NB3_servo_mount.dxf, NB3_spacer.dxf, materials.csv]
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2024-12-07 Fix some spellings
    [materials.csv]
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2024-12-10 Refactor course folder structure (libs, scripts, versions, _resources)
    [BOM_01.csv, BOM_10.csv, BOM_11.csv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]
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2024-12-20 Fix BOM bug
    [course_BOM.csv]
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2025-01-20 Fix video URL parsing
    [12V_DC_Power_Supply.step, Batteries__AA_.step, Battery.step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]
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2025-02-06 Update packaging dimensions/tolerances
    [Body.step, Cables.step, Large.step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]
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2025-02-10 Update NB3 Body (servo mounts for metal motors)
    [NB3_body.kicad_pcb]
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2025-02-15 Update package designs (final time for current draft)
    [Body.step, Cables.step, Large.step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]
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2025-02-18 Finish draft of NB3 Charger (submitted for Fab)
    [NB3_charger-B_Cu.gbl, NB3_charger-B_Mask.gbs, NB3_charger-B_Paste.gbp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]
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2025-03-10 Update skull mount hardware (M2.5 12 mm standoff PS)
    [materials.csv]
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2025-08-15 Fix ' in video titles (and slugs)
    [bootcamp_BOM.csv, bootcamp_packing_list.csv, buildabrain_BOM.csv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]
2025-08-15 Update package names and include in "materials included"
    [bootcamp_BOM.csv, bootcamp_packing_list.csv, buildabrain_BOM.csv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]
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2025-10-30 Slowly removing the concept of depth from the "boxes" and courses. Materials are per box (core), with additional requirements listed in each Lesson file
    [materials.csv]
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2025-10-31 Change "additional materials" to lesson linked CSV file. Also start removing "connections" section in Lesson md
    [Capacitors.csv, Induction.csv, NB3_Build-an-ADC-input.csv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]
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2025-11-01 refactor out concept of "depth" in course lessons/tasks/boxes
    [NB3_Sensory-Systems.csv]
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2025-11-28 Remove old NB3_eye (LED screen) board from Repo
    [NB3_eye-B_Cu.gbl, NB3_eye-B_Mask.gbs, NB3_eye-B_Paste.gbp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]
2025-11-28 Update Light,Cameras,Noise lesson (video)
2026-03-13 audio workshop: student-facing README, docstrings, aplay fix
    README:
    - Drop venv step; assume env already active, add git pull + install + .env
    - Document ffmpeg as required for MP3→WAV; table for ffmpeg/ffplay/aplay/arecord
    - Add copy-paste cd commands from repo root for pip, touch .env, pipeline, demo, aplay
    - Renumber setup (1.1–1.3), add “What’s in this folder” and “Playing the WAV”
    - Shorten workshop ideas and notes
    Code:
    - 01/02: add docstrings for transcribe, record_from_mic, ask_llm, text_to_speech; trim comments
    - nb3_audio: docstring for playback+recording; aplay: pass WAV path as last arg (drop -v)
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2026-04-14 Fix face detection rectangles in NB3 streamed camera overlay
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2026-05-22 Make course build engine stable and deterministic
    - Drop AI-Workshops from course_names: 02_vision has no top-level
    template.md so generate_courses.py crashes; 01_audio's README is
    hand-maintained.
    - Use ordered list (not set) for lesson_boxes in Session.parse so
    Materials-table row order is deterministic across runs.
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

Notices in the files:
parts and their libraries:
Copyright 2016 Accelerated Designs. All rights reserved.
